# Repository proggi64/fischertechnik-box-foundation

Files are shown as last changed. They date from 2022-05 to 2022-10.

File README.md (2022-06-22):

# Fischertechnik Sorting Box Construction Foundation For OpenSCAD
Find the documentation at https://proggi64.github.io/fischertechnik-box-foundation/

The foundation library provides a continuously expanding collection of parametric sorting elements, deployment and placement modules, as well as base sorting boxes for the Fischertechnik building blocks system. The results are intended to be printed with 3D printers.

This library is based on the mid-1970's high-grade plastic sorting boxes used by the Fischertechnik building kits. Some sample boxes that are almost identical to the original ones are included.

ec2

The goals of this library is to simplify the contruction of sorting boxes and provide an alternative to using CAD software. However, the elements and element groups may be exported as STLs and used in CAD software, as well.

The library modules are divided in these groups:
- Base
- ModelBase
- Elements
- Test
- Original Building Kits
- Building Kits

## Documentation

- [English](Documentation/en/Contents.md) - Not available, yet
- [German](Documentation/de/Contents.md)

## Base
Contains the base functionality of the library:
- Alignment.scad
- Boxes.scad
- BoxInlays.scad
- Constants.scad
- Deployment.scad
- Placement.scad
- PlacementOptions.scad
- Rotation.scad

Additionally, in the base folder are the STL files of the empty 190x130 and 130x95 boxes that are used to place the building block elements.

## ModelBase
Contains simple and complex parametrized base objects that are used with different parameters by concrete elements.

## Elements
Contains concrete elements for specific building parts, some of them with parameters. All of them are linked to one or more Fischertechnik part numbers.

## Test
Contains sample code for each module that demonstrate the parameters und functionality.

## Original Building Kits
Contains boxes that are almost identical to existing boxes from the 1970's and 1980's that demonstrate how to build boxes with the library. Each bulding kit series has its own subfolder (i.e. "ec", "em").

## Building Kits
Contains boxes for newer building kits from the last 20 years or so, that never had there own sorting box. These boxes are completely new designs. Each bulding kit series has its own subfolder (i.e. "Profi", "Computing").

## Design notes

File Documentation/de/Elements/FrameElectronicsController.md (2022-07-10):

# FrameElectronicsController
E-Tec-, Electronics Modul oder Robotics Modul mit Fach für montiertes Kabel.
- 32263
- 152063
- 156499

Das Element kann an Wände oder in Ecken des Sortierkastens angedockt werden.

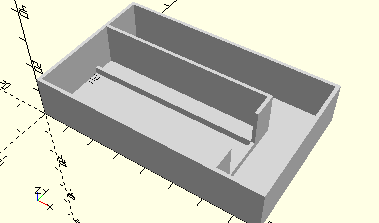
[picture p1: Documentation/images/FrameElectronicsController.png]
FrameElectronicsController


## Use
```
use <../Elements/FrameElectronicsController.scad>

include <../../Base/PlacementOptions.scad>
```

## Syntax
```
FrameElectronicsController(
    alignX);

space = get$FrameElectronicsControllerSpace(
    alignX);
```

| Parameter | Typ | Beschreibung |
| --- | --- | --- |
| alignX | typ | beschreibung |

## Rückgabewert getFrameElectronicsControllerSpace
Fläche als \[x,y]-Liste

## Beispiel
```
use <../../Base/Placement.scad>
use <../../Base/Boxes.scad>
use <../../Elements/FrameElectronicsController.scad>

include <../../Base/PlacementOptions.scad>

Box190();

Place(alignX=AlignRight, alignY=AlignTop, elementSpace=getFrameElectronicsControllerSpace())
    FrameElectronicsController(alignX=AlignRight, alignY=AlignTop);
```

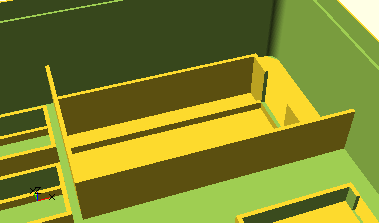
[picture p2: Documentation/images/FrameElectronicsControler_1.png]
FrameElectronicsController angedockt


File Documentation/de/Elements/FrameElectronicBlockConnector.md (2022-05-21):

# FrameElectronicBlockConnector
Verbindungsstecker für Elektronik-Bausteine.
- 36380

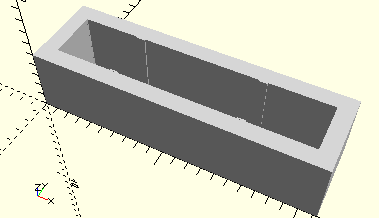
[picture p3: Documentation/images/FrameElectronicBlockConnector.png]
FrameElectronicBlockConnector


## Use
```
use <../Elements/FrameElectronicBlockConnector.scad>
```

## Syntax
```
FrameElectronicBlockConnector();

space = getFrameElectronicBlockConnectorSpace();
```

## Rückgabewert getFrameElectronicBlockConnectorSpace
Fläche als \[x,y]-Liste

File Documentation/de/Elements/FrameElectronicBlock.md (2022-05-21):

# FrameElectronicBlock
Elektronikbaustein (Silberling).
- 36391
- 36392
- 36393
- 36394
- 36479
- 36480
- 36481
- 36482
- 36483
- 36713
- 36733
- 36735
- 36786
- 37140 (alt, hobbylabor1)
- 37683

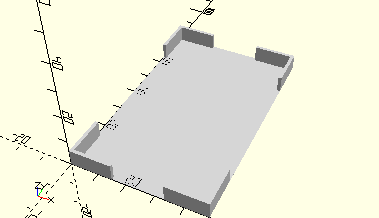
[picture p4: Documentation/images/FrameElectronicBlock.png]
FrameElectronicBlock


## Use
```
use <../Elements/FrameElectronicBlock.scad>
```

## Syntax
```
FrameElectronicBlock(
    alignX=NoAlign,
    alingY=NoAlign);

space = getFrameElectronicBlockSpace(
    alignX=NoAlign,
    alingY=NoAlign);
```

| Parameter | Typ | Beschreibung |
| --- | --- | --- |
| alignX | Integer (Enum) | Erzeugt optional einen Rand für das Andocken an die linke oder rechte Wand des Sortierkastens: 0=NoAlign 1=AlignLeft 4=AlignRight. Es werden Stege erzeugt, die mit der Wand verschmelzen. |
| alignY | Integer (Enum) | Erzeugt optional einen Rand für das Andocken an die hintere oder vordere Wand des Sortierkastens: 0=NoAlign 2=AlignBottom 5=AlignTop. Es werden Stege erzeugt, die mit der Wand verschmelzen. |

## Rückgabewert getFrameElectronicBlockSpace
Fläche als \[x,y]-Liste.

## Beispiel
Test/Elements/TestFrameElectronicBlock.scad

```
use <../../Base/Placement.scad>
use <../../Elements/FrameElectronicBlock.scad>

include <../../Base/PlacementOptions.scad>

FrameElectronicBlock();

Place(0, 85)
    FrameElectronicBlock(alignX=AlignLeft);

Place(80, 85)
    FrameElectronicBlock(alignX=AlignRight);

Place(0, 170)
    FrameElectronicBlock(alignY=AlignBottom);

Place(80, 170)
    FrameElectronicBlock(alignY=AlignTop);

Place(0, 260)
    FrameElectronicBlock(alignX=AlignLeft, alignY=AlignBottom);

Place(80, 260)
    FrameElectronicBlock(alignX=AlignLeft, alignY=AlignTop);

Place(0, 350)
    FrameElectronicBlock(alignX=AlignRight, alignY=AlignBottom);

Place(80, 350)
    FrameElectronicBlock(alignX=AlignRight, alignY=AlignTop);
```

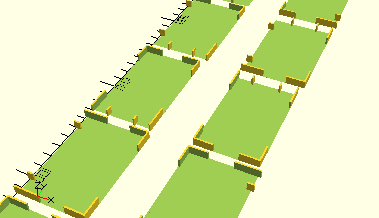
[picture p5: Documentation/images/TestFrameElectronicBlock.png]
TestFrameElectronicBlock


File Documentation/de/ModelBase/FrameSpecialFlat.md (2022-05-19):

# FrameSpecialFlat

Erzeugt einen Rahmen für spezielle Flachbausteine.

Diese Art Rahmen wurde in den ec-Kästen vor allem für Linsen und Lochblenden eingesetzt. Der Baustein liegt flach in Rahmen auf erhöhten Auflagen. Der Rahmen hat seitliche Eingriffe.

## Use
```
use <../ModelBase/Complex.scad>
```

## Syntax
```
FrameSpecialFlat(
  volume);
```

| Parameter | Typ | Beschreibung |
| --- | --- | --- |
| volume | \[x,y,z] | Länge x Breite x Höhe des speziellen Flachbausteins. Auf Länge und Breite wird noch der Wert von *tolerance* für das tatsächliche innere Volumen gerechnet. Die Höhe darf 15 mm nicht überschreiten, da der Rahmen nur so hoch ist. |

## Beispiel
```
use <../../ModelBase/Complex.scad>

FrameSpecialFlat([30, 37, 4]);

translate([40, 0])
FrameSpecialFlat([30, 34, 9]);
```

FrameSpecialFlat

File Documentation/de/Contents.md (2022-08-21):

# Inhalt

Dies ist die erste Version vom 1. Juni 2022. Der Grundstock für die Konstruktion von Sortierkästen umfasst schon ca. 100 Elemente der grauen Bausteine, die Ende der 1970er Jahre existierten. Bis Anfang Juli kamen noch mehr als 35 neue Elemente hinzu. Als Beispiele wurden die Kästen [ec1-3](../../Original%20Building%20Kits/ec/) sowie [mot1 bis mot3](../../Original%20Building%20Kits/mot/) nachgebaut. Unter [Motor Set XS](../../Building%20Kits/PLUS/) findet man ein Beispiel für einen kompletten Eigenentwurf. Für die hobby-Elektronikbausteine ("Silberlinge") sind druckbare Kästen im Verzeichnis [hobby](../../Building%20Kits/hobby/) als SCAD- und STL-Dateien hinterlegt.

Zwei Tutorials [Sortierkästen konstruieren](TutorialSortingBoxes.md) und [Elemente selbst konstruieren](TutorialElements.md) sollen helfen, eigene Beiträge zu ermöglichen.

## Allgemeines
- [Über die Bibliothek](readme.md)
- [Konstruktionsprinzipien](Principles.md)
- [Elemente erst im 3D-Druck testen](PrintTests.md)
- [Sortierkästen konstruieren](TutorialSortingBoxes.md)
- [Elemente selbst konstruieren](TutorialElements.md)
- [Elemente für CAD-Software nach STL exportieren](STLExport.md)
- [Beispielkästen und -Inlays](SampleBoxes.md)
- [Glossar](Glossar.md)

## Elemente für Sortierkästen

[Liste nach Fischertechnik-Artikelnummer](PartFinder.md)

## Basisfunktionen und -module

### Module für Grundelemente
- [__Box130__](Base/Box130.md): Importiert einen leeren Sortierkasten 130 x 95 mm als Basis für eigene Entwürfe.
- [__Box190__](Base/Box190.md): Importiert einen leeren Sortierkasten 190 x 130 mm als Basis für eigene Entwürfe.
- [__Box190Inlay__](Base/Box190Inlay.md): Erzeugt eine Grundplatte für Elemente, die in einen Original-Sortierkasten gelegt werden kann.
- [__Box190InlayWeb__](Base/Box190InlayWeb.md): Erzeugt einen kurzen Steg mit Einrast-Mechanismus für [__Box190Inlay__](Base/Box190Inlay.md).
- [__BoxWeb__](Base/BoxWeb.md): Erzeugt einen kurzen Steg an der Innenwand einer Sortierbox.

### Module zur Platzierung von Elementen
- [__Center__](Base/Center.md): Platziert Children-Elemente horizontal und/oder vertikal zentriert.
- [__CenterHorizontal__](Base/CenterHorizontal.md): Platziert Children-Elemente horizontal zentriert.
- [__CenterVertical__](Base/CenterVertical.md): Platziert Children-Elemente vertikal zentriert.
- [__DeployHorizontal__](Base/DeployHorizontal.md): Verteilt Children-Elemente mit gleichem Abstand horizontal.
- [__DeploySame__](Base/DeploySame.md): Verteilt mehrere Kopien des Children-Elements auf die angegebenen Spalten und Zeilen.
- [__DeployVertical__](Base/DeployVertical.md): Verteilt Children-Elemente mit gleichem Abstand vertikal.
- [__Merge__](Base/Merge.md): Fügt Kopien des Children-Elements so aneinander, dass dessen Trennwände zu jeweils einer verschmelzen.
- [__MergeRow__](Base/MergeRow.md): Fügt die Children-Elemente so aneinander, dass dessen Trennwände zu jeweils einer verschmelzen.
- [__Place__](Base/Place.md): Platziert die Children-Elemente auf die angegebene Position (absolut oder ausgerichtet).
- [__RotateFix__](Base/RotateFix.md): Rotiert das Children-Element um 0, 90, 180 oder 270 Grad im Uhrzeigersinn.

### Funktionen zur Koordinatenberechnung
- [__getAlignedX__](Base/getAlignedX.md): Berechnet X-Position für horizontal ausgerichtetes Element.
- [__getAlignedY__](Base/getAlignedY.md): Berechnet Y-Position für vertikal ausgerichtetes Element.
- [__getDepthSum__](Base/getDepthSum.md): Liefert Summe aller Tiefen der angegebenen Flächen.
- [__getIsHorizontal__](Base/getIsHorizontal.md): Liefert true, wenn die angegebene Ausrichtung eine horizontale Trennwand erfordert.
- [__getIsVertical__](Base/getIsVertical.md): Liefert true, wenn die angegebene Ausrichtung eine vertikale Trennwand erfordert.
- [__getMaxDepth__](Base/getMaxDepth.md): Liefert größte Tiefe der angegebenen Flächen.
- [__getMaxWidth__](Base/getMaxWidth.md): Liefert größte Breite der angegebenen Flächen.
- [__getMergedRowWidth__](Base/getMergedRowWidth.md): Liefert die Gesamtbreite einer zusammengefügten Reihe von Frame-basierten Elementen.
- [__getRotatedSpace__](Base/getRotatedSpace.md): Liefert eine Fläche so transformiert, dass die angegebene Drehung angewandt wird.
- [__getWidthSum__](Base/getWidthSum.md): Liefert Summe aller Breiten der angegebenen Flächen.
- [__getX__](Base/getX.md): Liefert eine Elementposition für die gleichmäßige Verteilung über eine Breite.
- [__getY__](Base/getY.md): Liefert eine Elementposition für die gleichmäßige Verteilung über eine Tiefe.

### Funktionen zur Ermittlung von Konstanten
- [__getAxisBottomDiameter__](Base/getAxisBottomDiameter.md): Liefert den Durchmesser für die Basis einer Achse.
- [__getAxisDiameter__](Base/getAxisDiameter.md): Liefert den Durchmesser einer Fischertechnik-Achse.
- [__getAxisLockingLength__](Base/getAxisLockingLength.md):Liefert die Länge des Rastbereichs einer Rastachse.
- [__getAxisTolerance__](Base/getAxisTolerance.md): Liefert den Betrag, der vom Durchmesser einer Fischertechnik-Achse abgezogen wird, wenn Standachsen generiert werden, damit die Fischertechnikteil darauf passen.
- [__getBox130Space__](Base/getBox130Space.md): Liefert die nutzbare Fläche eines Sortierkastens 130 x 95 mm.
- [__getBox190Space__](Base/getBox190Space.md): Liefert die nutzbare Fläche eines Sortierkastens 190 x 130 mm.
- [__getBoxBaseThickness__](Base/getBoxBaseThickness.md): Liefert die Stärke des Bodens eines Sortierkastens.
- [__getBoxUsageHeight__](Base/getBoxUsageHeight.md): Liefert die nutzbare innere Höhe eines Sortierkastens.
- [__getBoxWallThickness__](Base/getBoxWallThickness.md): Liefert die Stärke der Wände eines Sortierkastens.
- [__getBoxWebWidth__](Base/getBoxWebWidth.md): Liefert die Standardlänge eines Stegs für Sortierkästen.
- [__getDividerThickness__](Base/getDividerThickness.md): Liefert die Standardbreite einer Trennwand.
- [__getExcess__](Base/getExcess.md): Liefert den Betrag, um den ein Objekt mit einem verbundenen Objekt verschmilzt.
- [__getFragments__](Base/getFragments.md): Liefert die Anzahl der Fragmente für cylinder-Objekte ($fn).
- [__getFullStrutLength__](Base/getFullStrutLength.md): Liefert die Gesamtlänge einer Strebe auf Basis ihrer Nominallänge.
- [__getHubRingDiameter__](Base/getHubRingDiameter.md): Äußerer Durchmesser des Zylinders für Räder.
- [__getHubRingLevelDiameter__](Base/getHubRingLevelDiameter.md): Äußerer Durchmesser der Zylinderbasis für Räder.
- [__getPropellerAxisDiameter__](Base/getPropellerAxisDiameter.md): Liefert den Durchmesser der Propellerachse.
- [__getPropellerAxisTolerance__](Base/getPropellerAxisTolerance.md): Wird beim Durchmesser der Propellerachse als Druck-Toleranz verwendet.
- [__getStudHeight__](Base/getStudHeight.md): Länge eines Baustein-Verbindungszapfens.
- [__getStudRailDistance__](Base/getStudRailDistance.md): Abstand zweier Stege, damit Zapfen dazwischen passen.
- [__getStudTolerance__](Base/getStudTolerance.md): Wird zur Länge eines Baustein-Verbindungszapfens addiert, wenn Platz in Elementen dafür erzeugt wird.
- [__getSmallPartsFrameHeight__](Base/getSmallPartsFrameHeight.md): Liefert die Höhe für Rahmen, die für in Sortierkästen Kleinteile vorgesehen sind.
- [__getStandardEdgeDistance__](Base/getStandardEdgeDistance.md): Liefert den Standard-Abstand für andockbare Rahmen mit Stegen.
- [__getStandardWebDistance__](Base/getStandardWebDistance.md): Liefert den Abstand eines Stegs zur jeweiligen Ecke eines andockbaren Elements.
- [__getStandAxisDiameter__](Base/getStandAxisDiameter.md): Liefert den Durchmesser für Standachsen (z.B. für [__Axis__](ModelBase/Axis.md))
- [__getStrutDepth__](Base/getStrutDepth.md): Liefert die Stärke einer Strebe.
- [__getStrutEndRadius__](Base/getStrutEndRadius.md): Liefert den Radius vom Mittelpunkt des Schraublochs zum 
äußeren Ende einer Strebe.
- [__getStrutThickness__](Base/getStrutThickness.md): Liefert den Dicke einer Strebe.
- [__getStrutTolerance__](Base/getStrutTolerance.md): Liefert den Toleranzwert für Strebenhalterungen.
- [__getTolerance__](Base/getTolerance.md): Liefert den Betrag für die Toleranz bei Elementen, damit die Bauteile nach dem Druck in die Elemente passen.
- [__getTubeWallThickness__](Base/getTubeWallThickness.md): Liefert Stärke der Wände eines Element-Zylinders.

## Funktionen und Module für das Konstruieren von Elementen

### Module für einfache Grundformen
- [__AlignedFrame__](Modelbase/AlignedFrame.md): Erzeugt einen Rahmen, der an bis zu zwei Wände gleichzeitig angedockt werden kann.
- [__AngeledFrame__](ModelBase/AngeledFrame.md): Erzeugt einen um 90° gewinkelten Rahmen.
- [__Axis__](ModelBase/Axis.md): Erzeugt eine stehende Achse.
- [__AxisWithSpace__](ModelBase/AxisWithSpace.md): Erzeugt eine stehende Achse mit einer Grundplatte.
- [__Divider__](ModelBase/Divider.md): Erzeugt einen Trenner innerhalb eines Sortierkastens.
- [__DockableFrame__](ModelBase/DockableFrame.md): Erzeugt einen Rahmen, der an Wände angedockt werden kann.
- [__Frame__](ModelBase/Frame.md): Erzeugt einen Rahmen mit optional einzeln offenen Wänden.
- [__FrameBottomCutoff__](Modelbase/FrameBottomCutoff.md): Mit __difference__ in [__Frame__](ModelBase/Frame.md) einen Ausschnitt in die vordere Wand schneiden.
- [__FrameLeftCutoff__](Modelbase/FrameLefttCutoff.md): Mit __difference__ in [__Frame__](ModelBase/Frame.md) einen Ausschnitt in die linke Wand schneiden.
- [__FrameRails__](ModelBase/FrameRails.md): Erzeugt zwei parallele Stege am Boden eines mit [__Frame__](ModelBase/Frame.md) erzugten Rahmens.
- [__FrameRightCutoff__](Modelbase/FrameRightCutoff.md): Mit __difference__ in [__Frame__](ModelBase/Frame.md) einen Ausschnitt in die rechte Wand schneiden.
- [__FrameTopCutoff__](Modelbase/FrameTopCutoff.md): Mit __difference__ in [__Frame__](ModelBase/Frame.md) einen Ausschnitt in die hintere Wand schneiden.
- [__LeveledAxis__](ModelBase/LeveledAxis.md): Erzeugt eine stehende Achse mit einer stärkeren Achsbasis.
- [__LeveledAxisWithSpace__](ModelBase/LeveledAxisWithSpace.md): Erzeugt eine stehende Achse mit einer stärkeren Achsbasis und einer Grundplatte.
- [__LeveledTube__](ModelBase/LeveledTube.md): Erzeugt eine stehenden hohlen Zylinder mit einer stärkeren Basis.
- [__LockingAxis__](ModelBase/LockingAxis.md): Erzeugt eine stehende Achse für Rastachsenkupplungen.
- [__Space__](ModelBase/Space.md): Erzeugt eine dünne Fläche als Basis für ein Element.
- [__Text__](ModelBase/Text.md): Erzeugt einen reliefartigen Text im Boden des Sortierkastens.
- [__Tube__](ModelBase/Tube.md): Erzeugt eine stehenden hohlen Zylinder.
- [__Wall__](ModelBase/Wall.md): Erzeugt eine Wand.

### Funktionen zur Ermittlung der Größe einfacher Grundformen
- [__getAngeledFrameOuterVolume__](ModelBase/getAngeledFrameOuterVolume.md): Liefert das äußere Gesamtvolumen ("bounding box") eines gewinkelten Rahmens.
- [__getFrameInnerVolume__](ModelBase/getFrameInnerVolume.md): Liefert das innere Volumen eines Rahmens.
- [__getFrameOuterVolume__](ModelBase/getFrameOuterVolume.md): Liefert das äußere Volumen ("bounding box") eines Rahmens.

### Module für komplexe Grundformen
- [__AxisMiddleSupport__](ModelBase/AxisMiddleSupport.md): Erzeugt ein Stützelement für Achsen.
- [__ElevatedFramesWithCutoff__](ModelBase/ElevatedFramesWithCutoff.md): Erzeugt eine Halterung, die im Normalfall für einzelne Achsen verwendet wird.
- [__DockableEdgedFrame__](ModelBase/DockableEdgedFrame.md): Erzeugt einen Rahmen für Bauteile, der optional an bis zu zwei Wänden angedockt werden kann.
- [__FrameAxis__](ModelBase/FrameAxis.md): Erzeugt eine Achshalterung für eine Achse.
- [__FrameBracket__](ModelBase/FrameBracket.md): Erzeugt einen Rahmen für einen Getriebeaufsatz mit oder ohne Schnecke.
- [__FrameFlatPiece__](ModelBase/FrameFlatPiece.md): Erzeugt einen Rahmen für Flachstücke.
- [__FrameRack__](ModelBase/FrameRack.md): Erzeugt einen Rahmen für Zahnstangen.
- [__FrameSpecialFlat__](ModelBase/FrameSpecialFlat.md): Erzeugt einen Rahmen für spezielle Flachbausteine.
- [__HolderBuildingPlate__](ModelBase/HolderBuildingPlate.md): Erzeugt Halter für Bauplatten.
- [__RackBase__](ModelBase/RackBase.md): Erzeugt den inneren Rahmen für Zahnstangen.
- [__RailsBasePlate__](ModelBase/RailsBasePlate.md): Erzeugt Fläche mit Stegen für die Ablage einer Grundplatte.

### Funktionen zur Ermittlung von Werten zu komplexen Grundformen
- [__getAxisMiddleSupportSpace__](ModelBase/getFrameAxisMiddleSupportSpace.md): Liefert die Fläche eines mit [__AxisMiddleSupport__](ModelBase/AxisMiddleSupport.md) erzeugten Stützelements.
- [__getDockableEdgedFrameDepth__](ModelBase/getDockableEdgedFrameDepth.md): Liefert den vertikalen Abstand des angedockten Rahmens für [__DockableEdgedFrame__](ModelBase/DockableEdgedFrame.md).
- [__getDockableEdgedFrameWidth__](ModelBase/getDockableEdgedFrameWidth.md): Liefert den horizontalen Abstand des angedockten Rahmens für [__DockableEdgedFrame__](ModelBase/DockableEdgedFrame.md).
- [__getDockableEdgedFrameSpace__](ModelBase/getDockableEdgedFrameSpace.md): Liefert die Fläche für einen mit [__DockableEdgedFrame__](ModelBase/DockableEdgedFrame.md) erzeugten Rahmen.
- [__getDepthPerPlate__](ModelBase/getDepthPerPlate.md): Liefert die Tiefe (Dicke) einer Bauplatte für [__HolderBuildingPlate__](HolderBuildingPlate.md).
- [__getElevatedFramesWithCutoffSpace__](ModelBase/getElevatedFramesWithCutoffSpace.md): Liefert die Fläche des Elements, das mit dem Modul [__ElevatedFramesWithCutoff__](ElevatedFramesWithCutoff.md) erzeugt wird.
- [__getFrameAxisDepth__](ModelBase/getFrameAxisDepth.md): Liefert die Tiefe der Achshalterungen für [__FrameAxis__](ModelBase/FrameAxis.md).
- [__getFrameAxisHeight__](ModelBase/getFrameAxisHeight.md): Liefert die Höhe der Achshalterungen für [__FrameAxis__](ModelBase/FrameAxis.md).
- [__getFrameAxisSpace__](ModelBase/getFrameAxisSpace.md): Liefert die Fläche einer mit [__FrameAxis__](ModelBase/FrameAxis.md) erzeugte Achshalterung.
- [__getFrameBracketSpace__](ModelBase/getFrameBracketSpace.md): Liefert die Fläche für eine Halterung eines Getriebeaufsatzes.
- [__getFrameBracketWidth__](ModelBase/getFrameBracketWidth.md): Liefert die Breite für eine Halterung eines Getriebeaufsatzes ohne die Achse/Schnecke.
- [__getFrameFlatPieceVolume__](ModelBase/getFrameFlatPieceVolume.md): Liefert das Volumen eines mit [__FrameFlatPiece__](Modelbase/FrameFlatPiece.md) erzeugt wird.
- [__getFrameRackSpace__](ModelBase/getFrameRackSpace.md): Liefert die Fläche eines Rahmens für Zahnstangen.
- [__getHolderBuildingPlateSpace__](ModelBase/getHolderBuildingPlateSpace.md): Liefert die Fläche einer Halterung für Bauplatten.
- [__getRackInnerHeight__](ModelBase/getRackInnerHeight.md): Liefert die innere Höhe der Halterungen für Zahnstangen.
- [__getRailsBasePlateVolume__](ModelBase/getRailsBasePlateVolume.md): Liefert das Volumen des Rahmens für Grundplatten.

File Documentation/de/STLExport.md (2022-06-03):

# Elemente als STLs erzeugen
Mit OpenSCAD ist es sehr einfach, ein einzelnes Element als STL-Datei zu exportieren. Damit können die Elemente in CAD-Software weiter verwendet werden.

## Elemente ohne Parameter
Hier gibt es nur eine Variante, so dass nur ein einziger Export notwendig ist.

- die SCAD-Datei des gewünschten Elements aus dem __Elements__-Ordner in OpenSCAD öffnen
- der Dateiname entspricht 1:1 dem Namen aus der Dokumentation
- im Vorschaufenster erscheint bereits das Element
- Menüpunkt __Design__ | __Rendern F6__ wählen 
- die Farbe des Elements in der Vorschau wechselt von grau auf gelb
- Menüpunkt __Datei__ | __Exportieren...__ | __STL exportieren... F7__ wählen
- Zielverzeichnis im Dialog __STL Datei exportieren__ wählen
- Schaltfläche __Speichern__ klicken

## Elemente mit Parametern
Hier muss man sich die Variante einrichten, die man im jeweiligen Fall benötigt. Dazu sind die Parameter einzugeben. OpenSCAD hat ein schönes Feature namens __Customizer__. Die Elemente mit Parametern sind so erstellt, dass man ohne Änderungen des Codes die Parameter über diese Oberfläche einstellen und sich passende Varianten erstellen kann.

- SCAD laden wir bei den Elementen ohne Parameter
- Menüpunkt __Fenster__ | __Customizer__ anklicken

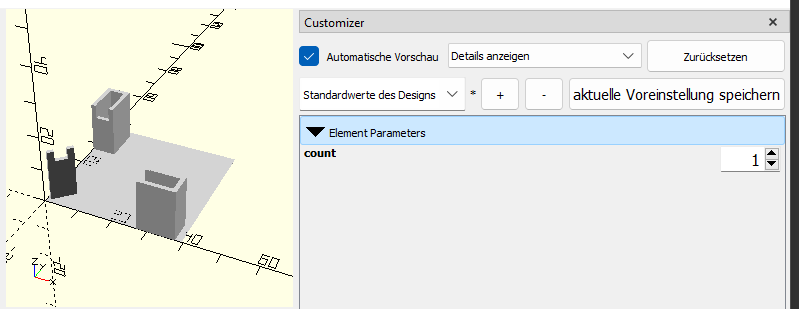
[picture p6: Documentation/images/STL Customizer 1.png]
STL Customizer count 1


- __Element Parameters__ im Customizer-Fenster aufklappen
- alle Parameter des Elements sind jetzt hier sichtbar und können angepasst werden
- nach Änderung eines Parameters einfach die __Tab__-Taste drücken, die Vorschau wird aktualisiert

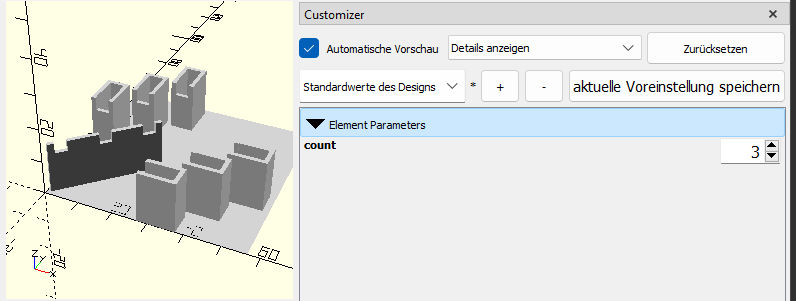
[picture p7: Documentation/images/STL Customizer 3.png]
STL Customizer count 3


- dann wie bei *Elemente ohne Parameter* mit __Rendern__ fortfahren und bis __Speichern__ gehen
- verschiedenen Varianten sollte man unterschiedliche STL-Dateinamen geben

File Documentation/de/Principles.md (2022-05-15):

# Konstruktionsprinzipien

Für die Konstruktion der Bibliothek wurden einige Prinzipien festgelegt, die beim weiteren Ausbau beachtet werden sollten, die aber auch wertvoll für den Einsatz der Bibliothek sind.

## Ziel 3D-Druck

Der gesamte Code ist darauf ausgerichtet, dass die 3D-Druck-Ergebnisse verwendbare Sortierboxen produzieren.

- Sinnvolle Toleranzen für alle Elemente (Constants.scad - __getTolerance()__), damit die Teile in die Elemente passen
- Saubere Verschmelzung von 3D-Elementen und Box (Constants.scad - __getExcess()__), um ungewollte Luftspalte zu vermeiden
- Druckbare Wandstärken, die hinreichend stabil bleiben sollten (Constants.scad - __getDividerThickness()__)
- Elemente benötigen keine Stützstrukturen

Die Bibliothek geht davon aus, dass ein 3D-Drucker mit einer 0,4 mm-Extruderdüse und einer Genauigkeit von 0,2 mm eingesetzt wird. Das Bauvolumen muss für die Sortierbox 190 x 130 ca. 20 x 14 x 4 cm groß sein.

## Elemente
Elemente sind die Konstrukte, die in der Sortierbox zur Aufnahme von ein oder mehreren Bauelementen platziert werden. Sie sind i.d.R. speziell für bestimmte Bauteile zugeschnitten. Für Kleinteile gibt es auch einfache parametrisierbare Kastenformen. Die passenden Elemente können über ihre Artikelnummer gefunden werden.

- Jedes Element hat eine eigene SCAD-Datei, deren Dateiname dem Namen des *module* entspricht.
- Jedes Element hat ein *module*, was das Element darstellt
- Jedes Element hat eine Funktion namen __get*ElementName*Space()__, welche den exakten Platzbedarf des Elements in der Box als x/y-Liste liefert.
- Manche Element benötigen Parameter, z.B. für die Anzahl der Bauteile, die sie fassen sollen
- Die __get*ElementName*Space()__-Funktionen benötigen i.d.R. dieselben Parameter wie das *module*.

Beispiel Getriebeschnecke 31045 für den 6V-Motor:

- Datei: *Elements/FrameBracketWithWorm.scad*
- Module: __FrameBracketWithWorm()__
- Function: __getFrameBracketWithWormSpace()__

Alle Elemente sind so konstruiert, dass sie bei der Platzierung in den Sortierkasten mit deren Boden verschmelzen. Der Betrag dieser Verschmelzung wird durch die in *Constants.scad* festgelegte Funktion __getExcess()__ bestimmt. Jedes Element hat eine Basisfläche der __get*ElementName*Space()__-Größe in dieser dünnen Stärke, die beim Platzieren im Boden des Sortierkastens verschwindet.

## Andockbare Elemente

Einige Elemente sind so entworfen, dass sie an eine oder zwei Wände der Box angedockt werden können. Diese Elemente haben i.d.R. Teile, die mit der Wand der Box beim Platzieren (in Verbindung mit dem Alignment) verschmolzen werden. Dafür ragen diese Teile über die jeweilige Nullposition hinaus, so dass sie in die Wand der Box integriert werden. Beispiele sind die Elemente für die Silberlinge (__FrameElectronicBlock__). Welche Seiten an die Wände gedockt werden, wird i.d.R. über entsprechende Parameter der Module gesteuert.

## Sortierboxen

Die Sortierkästen werden als STL-Dateien eingebunden. Sie wurden mit einem CAD-Programm entworfen und können mit den Original-Kästen von Fischertechnik gestapelt werden. Bei der Platzierung der Elemente ist die z-Nullinie exakt der obere Rand des Bodens des Sortierkastens. Die Position 0,0 ist exakt die Ecke der nutzbaren Innenfläche der Box.

Die Elemente werden, wie schon erwähnt, um den Betrag von __getExcess()__ in den Boden versenkt. Dies erledigen die Unterstützungs- und Platzierungsfunktionen.

## Ausrichtung

Die Bibliothek stell eine Reihe von Platzierungs- und Ausrichtungsfunktionen zur Verfügung, die bei der Konstruktion von Sortierboxen nützlich sind.

## Baukastenprinzip kombinierbar mit individuellen Elementen

Vorgefertigte Elemente und das individuelle Programmieren mit OpenSCAD-Code sollen beliebig kombinierbar sein. Die Funktionen und Module aus dem *Base*-Verzeichnis sollen auch bei der individuellen Gestaltung der Sortierkästen helfen. Beispiele für solche Kombinationen sind die Nachbauten der Originalkästen, z.B. der mot2.

## Tests als Beispiel

Im Verzeichnis *Test* befinden sich in entsprechenden Unterverzeichnissen jeweils Quellcodes mit Demonstrationen der Module, Funktionen und aller Elemente. Jedes Element und jedes Modul hat einen separate Testdatei. Dies sind so aufgebaut, dass sie gleichzeitig als manueller Test und Beispiel dienen.

- Test/Base: *Gruppenname*Test*Module*.scad oder *Gruppenname*Test*Function*.scad
- Test/ModelBase: SimpleTest*Module*.scad oder ComplexTest*Module*.scad
- Test/Elements: Test*Elementname*.scad

## Weitere Prinzipien

- Redundanzen bei Code und Konstanten werden vermieden, um an zentralen Stellen Anpassungen zu ermöglichen
- Namen sind über alle Quellcodes konsistent
- Sinnvolle Standardwerte für Parameter sollen den Einsatz vereinfachen

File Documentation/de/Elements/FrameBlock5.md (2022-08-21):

# FrameBlock5
Baustein 5 mit einem Zapfen.
- 37237
- 37468

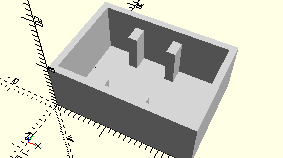
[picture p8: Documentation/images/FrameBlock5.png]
FrameBlock5


Die Abbildung zeigt ein Beispiel für 3 Bausteine 5. Es werden ab einer Zahl größer 1 automatisch Trenner eingefügt, damit die Steine nicht kippen.

3D-Druck getestet.

## Use
```
use <../Elements/FrameBlock5.scad>
```

## Syntax
```
FrameBlock5(
    count=1);

space = get$FrameBlock5Space(
    count=1);
```

| Parameter | Typ | Beschreibung |
| --- | --- | --- |
| count | Integer | Anzahl der Bausteine 5. |

## Rückgabewert getFrameBlock5Space
Fläche als \[x,y]-Liste

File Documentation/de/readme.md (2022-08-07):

# Fischertechnik Konstruktionsbibliothek für Sortierkästen mit OpenSCAD
Die Bibliothek bietet eine sich kontinuierlich erweiternde Sammlung an parametrisierten Sortierlementen, Verteilungs- und Platzierfunktionen, sowie Basis-Sortierkästen und Einsätze für Originalkästen für das Fischertechnik-Baukastensystem. Die Kästen und Einsätze sind so entworfen, dass sie sich mit 3D-Druckern selbst herstellen lassen.

Die Bibliothek wurde inspiriert durch die Kunstoff-Sortierkästen der Fischertechnik-Baukästen der 1970er bis Anfang 1980er Jahre. Einige Beispielkästen im Verzeichnis *Original Building Kits* sind weitgehend identisch mit den Originalkästen.

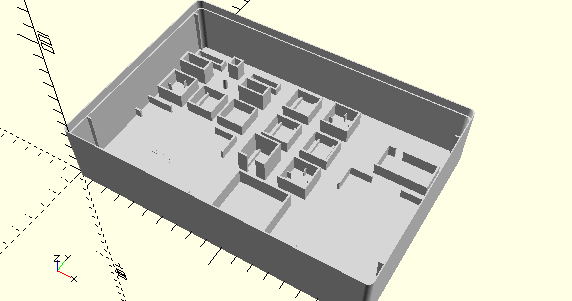
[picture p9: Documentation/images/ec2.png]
ec2


Die Ziele dieser Bibliothek sind es die Konstruktion eigener Sortierkästen zu vereinfachen und eine Alternative zur CAD-Programmen zu bieten. Dennoch können die Elemente auch in CAD-Programmen verwendet werden, wenn man sie einzeln als STL-Dateien exportiert. Dafür wird bei Elementen, die Parameter benötigen, der OpenSCAD-Customizer unterstützt. Dadurch können alle benötigten Varianten gerendert und als STL-Datei exportiert werden, ohne dass OpenSCAD-Skripte geändert werden müssen.

Um die Bibliothek sinnvoll einsetzen zu können, sollte man zumindest die Grundlagen von [OpenSCAD](https://openscad.org/documentation.html) beherrschen:
- Koordinatensystem auf den X/Y/Z-Achsen
- Module und Funktionen
- Einfache Geometrie

Die Bibliothek teilt sich in folgende Gruppen:
- Base
- ModelBase
- Elements
- Test
- Original Building Kits
- Building Kits

## Base
Enthält die Basisfunktionalität der Bibliothek:
- Alignment.scad  
Funktionen für die Berechnung von Koordinaten für die Ausrichtung (Links/Oben/Rechts/Unten/Zentriert)
- Boxes.scad  
Module für den Import leerer Sortierboxen als Grundlage für jede Box
- BoxInlays.scad  
Module zum Erzeugen von bestückbaren Bodeneinlagen für Original-Fischertechnik Sortierkästen statt ganzer Kästen
- Constants.scad  
Funktionen, die konstante Werte liefern, z.B. die Wandstärke und die Toleranz
- Deployment.scad  
Module, die Elemente gleichmäßig verteilen
- Placement.scad  
Module, die Elemente platzieren und ausrichten
- PlacementOptions.scad  
Optionswerte für die Ausrichtung und Drehung, die per __include__ eingebunden werden
- Rotation.scad  
Module, die Elemente drehen

Im Base-Verzeichnis finden sich auch die STL-Dateien mit den Leerboxen 190x130 und 130x95, die als Basis zur Konstruktion verwendet werden.

## ModelBase
Enthält einfache (__Simple.scad__) und komplexere (__Complex.scad__) parametrisierbare Basiselemente, mit denen die Elemente für spezifische Bauteile erstellt werden. Diese können aber auch für individuelle Elemente für spezifische Sortierkästen verwendet werden.

## Elements
Enthält Elemente für spezifische Fischertechnik-Bauteile, einige von ihnen parametrisierbar. Alle sind auch Fischertechnik-Teilenummern zugeordnet, die in den Quelldateien als Kommentare vermerkt sind. Diese Elemente sind sofort für die Konstruktion von Sortierboxen verwendbar. Diese Sammlung wird kontinuierlich erweitert. Über die Dokumentationsseite [PartFinder](PartFinder.md) können mit der Fischertechnik-Teilenummer die passenden Elemente gefunden werden.

## Test
Enthält Testdateien für alle Module, die Funktionalität und Elemente demonstrieren. Im Unterverzeichnis __PrintTest__ befinden sich außerdem für den 3D-Druck vorbereitete SCAD-Dateien für den Testdruck jedes Elements.

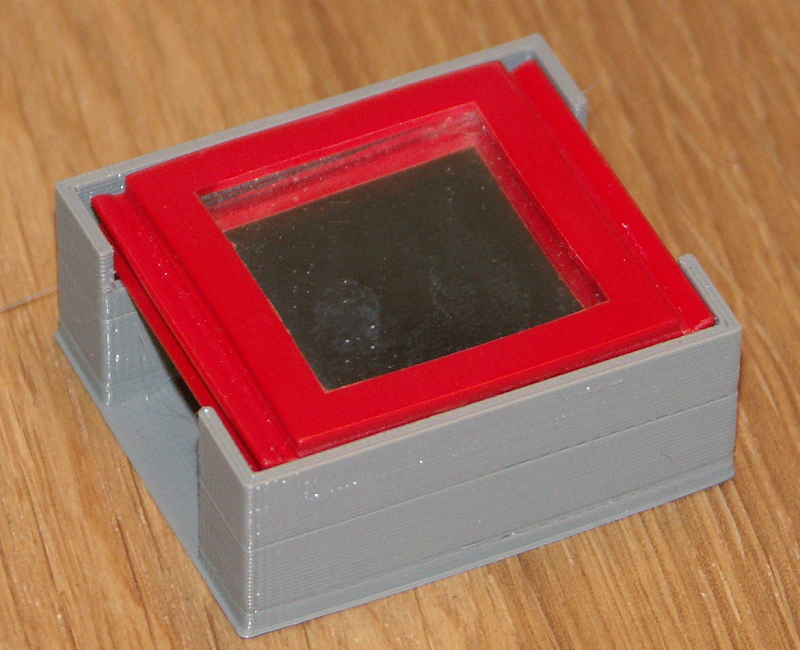
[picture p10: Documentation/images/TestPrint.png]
Testdruck für Element


*Testdruck eines Elements vermeidet große Fehldrucke*

## Original Building Kits
Enthält Beispiele von nachgebauten Original-Sortierkästen aus den 1970er Jahren zur Demonstration, wie Kästen konstruiert werden können. Beispielweise sind die drei Elektronikkästen ec1 bis ec3 im Unterverzeichnis ec enthalten.

## Building Kits
Enthält selbstkonstruierte Sortierkästen für Baukästen ab den 1980er Jahren. Diese sind komplette Neuentwürfe.

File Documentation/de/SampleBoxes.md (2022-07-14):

# Beispiele für Sortierkästen

Es gibt zwei Arten von Beispielkästen, die sukzessive erweitert werden:
- Nachgebaute Originalkästen
- Neue Entwürfe

## Neu entworfene Sortierkästen für aktuelle oder historische Fischertechnikkästen

Verzeichnis: Building Kits/*group*

Im Juli 2022 gibt es hier die Gruppen *hobby*, *PLUS* und *PROFI*.

## Nachgebaute Originalkästen

Verzeichnis: Original Building Kits/*group*

Gruppen sind z.B. Baukastenreihen wie ec (Elektronik) oder mot (Motoren)

## Kompletter Kasten oder Inlay

Die Kästen ec1-ec3 wurden so modifiziert, dass sie als komplette Kästen oder Inlays für die Box-1000-Sortierkästen generiert werden können. Die Auswahl erfolgt über den OpenSCAD-Customizer:

### ec1 als Inlay
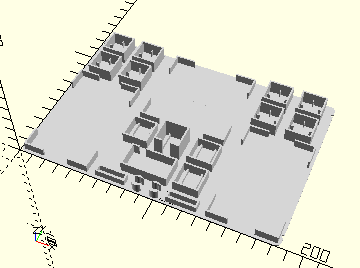
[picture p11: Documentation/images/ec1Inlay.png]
ec1Inlay


### ec1 komplett
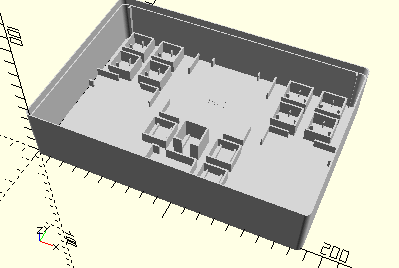
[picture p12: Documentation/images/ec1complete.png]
ec1


### Auswahl im Customizer
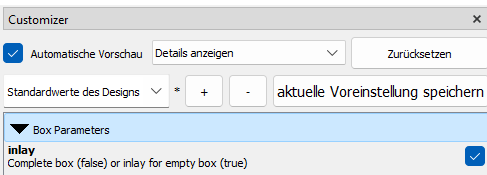
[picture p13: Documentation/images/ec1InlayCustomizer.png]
ec1 Customizer


### Was zu beachten war

Zunächst muss eine boolsche Variable eingeführt werden. Ein sinnvoller Name dafür ist *inlay*:

```
/* [Box Parameters] */
// Complete box (false) or inlay for empty box (true)
inlay = false;
```

Ebenfalls sinnvoll ist das Ausblenden von weiteren internen Variablen durch diese Kommentarzeile:

```
/* [Hidden] */
```

Um den kompletten Kasten durch ein Inlay auszutauschen muss man lediglich diese Sequenz verwenden:

```
if (inlay) {
    Box190Inlay();
} else {
    Box190();
    BoxWeb(LowerLeft, RightOfCorner, 15.2);
    BoxWeb(LowerRight, LeftOfCorner, 15.2);
    BoxWeb(UpperRight, RightOfCorner, 5);
    BoxWeb(UpperLeft, LeftOfCorner, 5);
}
```

Dadurch werden auch die Stege entfernt.

Falls man, wie beim ec1, auch Elemente verwendet, die sich an die Wand andocken, muss man weitere Änderungen einbauen. Beim ec1 war das der Rahmen für die Kassette oben, sowie die beiden links und rechts angedockten Rahmen für Relais und Gleichrichter. Diese beiden Elemente ([__FrameCassette__](Elements/FrameCassette.md) und [__FrameElectronicBlock__](Elements/FrameElectronicBlock.md)) rücken sich automatisch etwas von den Wänden ab und generiern Stege, wenn sie gedockt werden. Das muss man bei *inlay* = __true__ ausschalten:

```
    FrameElectronicBlock(alignX=inlay ? NoAlign : AlignLeft, alignY=inlay ? NoAlign : AlignBottom);
```

Beim Docken am linken (__AlignLeft__) oder unteren Rand (__AlignBottom__) muss man außerdem beim Platzieren berücksichtigen, die Differenz des zusätzlichen Platzes für den Docking-Abstand zu x bzw. y zu addieren. Dadurch bleiben die Rahmen auch ohne Abstand und Stege an der vorgesehenen Position:

```
xInlayDiff = inlay ? 
    (getFrameElectronicBlockSpace(alignX=AlignRight, alignY=AlignBottom).x - getFrameElectronicBlockSpace().x) : 
    0;
yInlayDiff = inlay ? 
    (getFrameElectronicBlockSpace(alignX=AlignRight, alignY=AlignBottom).y - getFrameElectronicBlockSpace().y) : 
    0;
Place(xInlayDiff, yInlayDiff)
    FrameElectronicBlock(alignX=inlay ? NoAlign : AlignLeft, alignY=inlay ? NoAlign : AlignBottom);
```

Beim ec3 liegen Wände genau auf der Höhe der Stege der Sortierboxen des Kastens 1000. Deswegen mussten sie um einen Offset von -1,8 mm nach innen versetzt werden. Auch das muss beachtet werden, wenn man die Kästen für Inlays modifiziert.

In zukünftigen Versionen soll das noch besser unterstützt werden. Zunächst soll aber noch an weiteren Kästen geprüft werden, welche Auswirkungen durch *inlay*-Varianten auftreten können.

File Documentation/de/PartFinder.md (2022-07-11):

# Teileliste

Hier findet man fertige Elemente, die für Fischertechnikteile bereits entworfen wurden. Die Liste ist nach Gruppen von Artikelnummern gegliedert. Auf den verlinkten Seiten für die Elemente sind alle Artikelnummern der Bausteine zum Element aufgeführt.

Alle Elemente besitzen neben dem __module__ auch eine __function__ nach dem Namensschema __get*ElementName*Space__. Sie liefert die benötigte Fläche für das Element in Form einer \[x,y]-Liste. Zumeist haben diese Funktionen dieselben Parameter wie das __module__. Vielen Modulen für die Platzierung muss diese Fläche als Parameter mitgegeben werden, damit Drehungen und die Verteilung funktionieren.

__module__ und __function__ sind beide auf den verlinkten Seiten dokumentiert. Codebeispiele zeigen die Anwendung.

Die hier verlinkten Elemente sind Vorschläge. Viele Bausteine, die hier nicht aufgeführt sind, passen ebenfalls in vorhandene Elemente.

- [1 bis 29999](Parts_1_to_29999.md)
- [30000 bis 31499](Parts_30000_to_31499.md)
- [31500 bis 31999](Parts_31500_to_31999.md)
- [32000 bis 34999](Parts_32000_to_34999.md)
- [35000 bis 35499](Parts_35000_to_35499.md)
- [35500 bis 35999](Parts_35500_to_35999.md)
- [36000 bis 36499](Parts_36000_to_36499.md)
- [36500 bis 36999](Parts_36500_to_36999.md)
- [37000 bis 37999](Parts_37000_to_37999.md)
- [38000 bis 38999](Parts_38000_to_38999.md)
- [39000 bis 39999](Parts_39000_to_39999.md)
- [40000 bis 99999](Parts_40000_to_99999.md)
- [100000 bis 149999](Parts_100000_to_149999.md)
- [150000 bis 169999](Parts_150000_to_169999.md)
- [170000 bis 999999](Parts_170000_to_999999.md)

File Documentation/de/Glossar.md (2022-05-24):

# Glossar

| Begriff | Bedeutung |
| --- | ---  |
| __Alignment__ | Fasst alle Ausrichtungsmodule und -funktionen zusammen, mit denen *Elemente* an Rändern ausgerichtet oder zentriert werden können. |
| __Axis__ | Stehende Achse als Aufnahmeelement für Naben, Achskupplungen oder andere Bauteile, die mit Achsen verbunden werden. Alle *Elemente*, die als Basis eine Achse haben, bekommen im Modulnamen das Präfix *Axis*. |
| __Bottom__ | Bezeichnet den vorderen Bereich von Elementen oder Boxen, z.B. bei __AlignBottom__. |
| __Center__ | Zentrieren von Elementen auf Strecken oder Flächen. |
| __Combo__  | Namens-Präfix für Kombinationen von gruppierten Elementen, die ein größeres Element bilden. |
| __Cylinder__ | Stehende Zylinder als Aufnahmeelement für Reifen oder andere Bauteile, die mit Naben oder anderen rundenBauelementen verbunden werden. Alle *Elemente*, die als Basis einen Zylinder haben, bekommen im Modulnamen das Präfix *Cylinder*. |
| __Deploy__ | Automatisches Verteilen gleicher oder verschiedener Elemente auf Strecken oder Flächen. |
| __Deployment__ | Fasst alle Module und Funktionen zusammen, mit denen mehrere Elemente gleichmäßig über Strecken oder Flächen verteilt werden können. |
| __Depth__ | Strecken auf der Y-Achse ("Tiefe"). |
| __Divider__ | Bezeichner für Trennwand. |
| __Element__ | 3D-Konstrukt, welches den Platz für einzelne oder mehrere Bauteile innerhalb der Sortierbox definiert. Einige können über Parameter modifiziert werden, z.B. um die Anzahl der Teile anzugeben. |
| __Frame__ | Rahmen für Bauteile, die im einfachen Fall *Element* sein können. Alle *Elemente*, die als Basis einen Rahmen haben, bekommen im Modulnamen das Präfix *Frame*. Die Rahmen bestehen aus Wänden, deren Standardstärke über die in *Constants.scad* definierte Funktion *getDividerThickness()* abgerufen werden kann. Das gleichname __Frame__-Modul bekommt als Parameter die Raumgröße des Fischertechnik-Teils und addiert für diesen noch die Standard-Toleranz in x- und y-Richtung (aus *Constants.scad* die Funktion *getTolerance()*). |
| __get__ | Namens-Präfix für alle Funktionen (__function__). |
| __Height__ | Strecken auf der Z-Achse. |
| __Holder__ | Halterung für Bauteile, die z.B. für Achsen oder Naben verwendet werden. Diese haben keinen *Frame* als Basis, sondern andere Grundformen. Diese Elemente bekommen das Präfix *Holder* im Modulnamen. |
| __Horizontal__ | Alles, was auf der X-Achse liegt. |
| __Placement__ | Fasst alle Platzierungs-Module zusammen, mit denen Elemente platziert und ausgerichtet werden können. |
| __Rotation__ | Fasst alle Module zusammen, mit denen Element rotiert werden können. Dabei wird jeweils die neue untere rechte Ecke an der urspünglichen Position der alten platziert. Bei rotierten Elemente, die an Rändern ausgerichtet sind, bleibt die Ausrichtung erwartungskonform, als wenn das Element auch urspünglich die Drehung hatte. |
| __Space__ | Fläche mit x/y-Ausdehnung. In der SCAD-Datei jedes *Elements* ist eine Funktion namens get*ElementName*Space() definiert, welche die Ausdehnung des Elements liefert. Da OpenSCAD eine funktionale Sprache ist und Objekte mit Methoden und Eigenschaften nicht vorgesehen sind, können diese Daten nicht über die 3D-Objekte abgerufen werden, sondern müssen separat als Funktion über Namenskonvention definiert werden. Flächen sind in OpenSCAD Listen aus mindestens zwei Werten \[x,y\]. Viele der Space-Funktionen liefern aber auch gleich den Z-Wert als dritten Wert mit. |
| __Top__ | Bezeichnet den hinteren Bereich von Elementen oder Boxen, z.B. bei __AlignTop__. |
| __Vertikal__ | Alles, was auf der Y-Achse liegt. |
| __Volume__ | Volumen mit x/y/z-Ausdehnung. Diese werden als Listen in OpenSCAD angegeben \[x,y,z\]. |
| __Width__ | Strecken auf der X-Achse ("Breite"). |

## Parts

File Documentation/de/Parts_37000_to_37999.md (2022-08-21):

# 37000 bis 37999
- 37140 [FrameElectronicBlock](Elements/FrameElectronicBlock.md)
- 37237 [FrameBlock5](Elements/FrameBlock5.md), [FrameSmallBlock](Elements/FrameSmallBlock.md)
- 37238 [FrameBlock5TwoStuds](Elements/FrameBlock5TwoStuds.md)
- 37263 [FrameLiftingGear](Elements/FrameLiftingGear.md)
- 37268 [FrameLiftingGear](Elements/FrameLiftingGear.md)
- 37271 [FrameLiftingGear](Elements/FrameLiftingGear.md)
- 37272 [FrameLiftingGear](Elements/FrameLiftingGear.md)
- 37276 [FrameConnectingRod30](Elements/FrameConnectingRod30.md)
- 37282 [HolderLiftingJoint](Elements/HolderLiftingJoint.md)
- 37283 [FrameConnectingRod60](Elements/FrameConnectingRod60.md)
- 37353 [HolderCompleteBucket](Elements/HolderCompleteBucket.md)
- 37354 [HolderCompleteBucket](Elements/HolderCompleteBucket.md)
- 37355 [HolderCompleteBucket](Elements/HolderCompleteBucket.md)
- 37384 [FrameAxis80](Elements/FrameAxis80.md)
- 37451 [FrameGearRack60](Elements/FrameGearRack60.md)
- 37457 [FrameGearRack30](Elements/FrameGearRack30.md)
- 37468 [FrameBlock5](Elements/FrameBlock5.md), [FrameSmallBlock](Elements/FrameSmallBlock.md)
- 37527 [FrameAxis180](Elements/FrameAxis180.md)
- 37636 [FrameBlockWithStud](Elements/FrameBlockWithStud.md)
- 37679 [Divider](ModelBase/Divider.md), [FrameCassette](Elements/FrameCassette.md)
- 37681 [AxisPropellerTip](Elements/AxisPropellerTip.md)
- 37683 [FrameElectronicBlock](Elements/FrameElectronicBlock.md)
- 37780 [FrameMiniPushButton](Elements/FrameMiniPushButton.md)
- 37783 [FrameMiniPushButton](Elements/FrameMiniPushButton.md)
- 37858 [ComboWormAndNutScrew](Elements/ComboWormAndNutScrew.md)
- 37869 [HolderBulbLamp](Elements/HolderBulbLamp.md)
- 37875 [HolderBulbLamp](Elements/HolderBulbLamp.md)

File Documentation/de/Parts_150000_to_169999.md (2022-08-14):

# 150000 bis 169999
- 152059 [FrameTransistorBlock](Elements/FrameTransistorBlock.md)
- 152063 [FrameElectronicsController](Elements/FrameElectronicsController.md)
- 152218 [FrameTransistorBlock](Elements/FrameTransistorBlock.md)
- 152219 [FrameBlockWithStud](Elements/FrameBlockWithStud.md), [Divider](ModelBase/Divider.md), [FrameCassette](Elements/FrameCassette.md)
- 152220 [FrameBlockWithStud](Elements/FrameBlockWithStud.md), [Divider](ModelBase/Divider.md), [FrameCassette](Elements/FrameCassette.md)
- 152222 [FrameBlockWithStud](Elements/FrameBlockWithStud.md), [Divider](ModelBase/Divider.md), [FrameCassette](Elements/FrameCassette.md)
- 152223 [FrameBlockWithStud](Elements/FrameBlockWithStud.md), [Divider](ModelBase/Divider.md), [FrameCassette](Elements/FrameCassette.md)
- 152860 [FrameTransistorBlock](Elements/FrameTransistorBlock.md)
- 153513 [FrameTXTController](Elements/FrameTXTController.md)
- 156042 [Divider](ModelBase/Divider.md), [FrameCassette](Elements/FrameCassette.md)
- 156499 [FrameElectronicsController](Elements/FrameElectronicsController.md)
- 156511 [HolderBuildingPlate30x30](Elements/HolderBuildingPlate30x30.md)
- 158402 [FrameSensor45x30](Elements/FrameSensor45x30.md)
- 160545 [FrameTwoStrut30](Elements/FrameTwoStrut30.md)
- 161944 [FrameBTSmartController](Elements/FrameBTSmartController.md)
- 162134 [FrameBlockWithStud](Elements/FrameBlockWithStud.md)
- 163042 [HolderBuildingPlate30x45](Elements/HolderBuildingPlate30x45.md)
- 163198 [FrameSidePieceLeft](Elements/FrameSidePieceLeft.md)
- 163199 [FrameSidePieceRight](Elements/FrameSidePieceRight.md)
- 163200 [FrameSidePiece15](Elements/FrameSidePiece15.md)
- 163201 [FrameStandardBlock](Elements/FrameStandardBlock.md)
- 163202 [FrameStandardBlock](Elements/FrameStandardBlock.md)
- 163203 [Divider](ModelBase/Divider.md), [FrameCassette](Elements/FrameCassette.md)
- 163204 [Divider](ModelBase/Divider.md), [FrameCassette](Elements/FrameCassette.md)
- 163436 [FrameSidePieceLeft](Elements/FrameSidePieceLeft.md)
- 163437 [FrameSidePieceRight](Elements/FrameSidePieceRight.md)
- 163439 [FrameStandardBlock](Elements/FrameStandardBlock.md)
- 167358 [FrameSensor45x30](Elements/FrameSensor45x30.md)

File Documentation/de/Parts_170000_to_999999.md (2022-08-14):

# 170000 bis 999999
- 172542 [FrameStandardBlock](Elements/FrameStandardBlock.md)
- 172545 [AxisIdlerGearZ15](Elements/AxisIdlerGearZ15.md)
- 172804 [FrameJointBlock](Elements/FrameJointBlock.md)
- 172805 [FrameJointBlock](Elements/FrameJointBlock.md)
- 173067 [FrameTXTController](Elements/FrameTXTController.md)
- 181583 [Divider](ModelBase/Divider.md), [FrameCassette](Elements/FrameCassette.md)
- 181584 [Divider](ModelBase/Divider.md), [FrameCassette](Elements/FrameCassette.md)
- 183025 [CylinderOmniWheel](Elements/CylinderOmniWheel.md)
- 183026 [CylinderOmniWheel](Elements/CylinderOmniWheel.md)
- 183027 [CylinderOmniWheel](Elements/CylinderOmniWheel.md)
- 183028 [CylinderOmniWheel](Elements/CylinderOmniWheel.md)
- 183233 [FrameElectronicsController](Elements/FrameElectronicsController.md)
- 183267 [FrameSensor45x30](Elements/FrameSensor45x30.md)
- 185516 [FrameTransistorBlock](Elements/FrameTransistorBlock.md)
- 186027 [FrameTransistorBlock](Elements/FrameTransistorBlock.md)
- 186028 [FrameTransistorBlock](Elements/FrameTransistorBlock.md)
- 186029 [FrameTransistorBlock](Elements/FrameTransistorBlock.md)
- 185695 [FramePlasticBall20](Elements/FramePlasticBall20.md), [Divider](ModelBase/Divider.md), [FrameCassette](Elements/FrameCassette.md)
- 185849 [FrameAxis50WithGearwheelZ28](Elements/FrameAxis50WithGearwheelZ28.md)
- 186705 [FrameSensor45x30](Elements/FrameSensor45x30.md)

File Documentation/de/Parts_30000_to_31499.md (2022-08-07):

# 30000 bis 31499
- 31001 [RailsBasePlate180x90](Elements/RailsBasePlate180x90.md)
- 31002 [RailsBasePlate90x90](Elements/RailsBasePlate90x90.md)
- 31003 [FrameStandardBlock](Elements/FrameStandardBlock.md)
- 31004 [FrameStandardBlock](Elements/FrameStandardBlock.md), [FrameSingleLayingStandardBlock](Elements/FrameSingleLayingStandardBlock.md)
- 31005 [FrameStandardBlock](Elements/FrameStandardBlock.md)
- 31006 [FrameBlockWithStud](Elements/FrameBlockWithStud.md)
- 31007 [FrameBlockWithStud](Elements/FrameBlockWithStud.md)
- 31008 [FrameHingedBlock](Elements/FrameHingedBlock.md), [FrameJointBlock](Elements/FrameJointBlock.md)
- 31009 [FrameHingedBlock](Elements/FrameHingedBlock.md), [FrameJointBlock](Elements/FrameJointBlock.md)
- 31010 [FrameAngleEquilateral](Elements/FrameAngleEquilateral.md)
- 31011 [FrameAngleIsosceles](Elements/FrameAngleIsosceles.md)
- 31012 [FrameAngleRight](Elements/FrameAngleRight.md)
- 31013 [FrameFlatPiece30](Elements/FrameFlatPiece30.md)
- 31014 [CylinderHub](Elements/CylinderHub.md), [CylinderHubWithZ30](Elements/CylinderHubWithZ30.md)
- 31015 [AxisFlatHub](Elements/AxisFlatHub.md), [CylinderHub](Elements/CylinderHub.md), [ComboFlatHubLargePulleyWheel](Elements/ComboFlatHubLargePulleyWheel.md)
- 31016 [HolderWinchDrum](Elements/HolderWinchDrum.md)
- 31017 [CylinderTire20](Elements/CylinderTire20.md)
- 31018 [HolderTire45](Elements/HolderTire45.md)
- 31019 [CylinderLargePulleyWheel](Elements/CylinderLargePulleyWheel.md), [ComboFlatHubLargePulleyWheel](Elements/ComboFlatHubLargePulleyWheel.md)
- 31020 [FrameLockingRing](Elements/FrameLockingRing.md)
- 31021 [CylinderGearZ20](Elements/CylinderGearZ20.md)
- 31022 [AxisFlatHubWithGearZ40](Elements/AxisFlatHubWithGearZ40.md)
- 31023 [AxisClip10](Elements/AxisClip10.md)
- 31024 [AxisCoupling](Elements/AxisCoupling.md)
- 31025 [Divider](ModelBase/Divider.md), [FrameCassette](Elements/FrameCassette.md)
- 31026 [AxisHandCrank](Elements/AxisHandCrank.md)
- 31027 [Divider](ModelBase/Divider.md), [FrameCassette](Elements/FrameCassette.md)
- 31028 [Divider](ModelBase/Divider.md), [FrameCassette](Elements/FrameCassette.md)
- 31029 [Divider](ModelBase/Divider.md), [FrameCassette](Elements/FrameCassette.md)
- 31031 [FrameAxis110](Elements/FrameAxis110.md)
- 31032 [FrameAxis60](Elements/FrameAxis60.md), [FrameAxis60open](Elements/FrameAxis60Open.md)
- 31033 [FrameAxis50](Elements/FrameAxis50.md)
- 31034 [FrameAxis30](Elements/FrameAxis30.md), [CylinderAxis30](Elements/CylinderAxis30.md)
- 31035 [FrameAngleAxis](Elements/FrameAngleAxis.md)
- 31036 [FrameAxis125](Elements/FrameAxis125.md)
- 31037 [CylinderAndAxisSegmentDisc](Elements/CylinderAndAxisSegmentDisc.md)
- 31038 [CylinderAndAxisDiscCam](Elements/CylinderAndAxisDiscCam.md), [ComboDiscCamPlusCogWheel](Elements/ComboDiscCamPlusCogWheel.md)
- 31039 [FrameMotor6V](Elements/FrameMotor6V.md)
- 31040 [FrameAxis90](Elements/FrameAxis90.md)
- 31041 [HolderBatterySet](Elements/HolderBatterySet.md)
- 31042 [Divider](ModelBase/Divider.md), [FrameCassette](Elements/FrameCassette.md)
- 31043 [FrameDifferentialGearbox](Elements/FrameDifferentialGearbox.md)
- 31044 [FrameUniversalJointCardan](Elements/FrameUniversalJointCardan.md)
- 31045 [FrameBracketWithWorm](Elements/FrameBracketWithWorm.md), [ComboFrameBrackets](Elements/ComboFrameBrackets.md)
- 31046 [FrameBracketWithoutWorm](Elements/FrameBracketWithoutWorm.md), [ComboFrameBrackets](Elements/ComboFrameBrackets.md)
- 31047 [AxisCogWheel](Elements/AxisCogWheel.md), [ComboDiscCamPlusCogWheel](Elements/ComboDiscCamPlusCogWheel.md)
- 31048 [FrameGearBox](Elements/FrameGearBox.md)
- 31051 [AxisCogWheel](Elements/AxisCogWheel.md), [ComboDiscCamPlusCogWheel](Elements/ComboDiscCamPlusCogWheel.md)
- 31052 [CylinderStepUpDownCog](Elements/CylinderStepUpDownCog.md)
- 31053 [FrameRack60](Elements/FrameRack60.md)
- 31054 [FrameRack30](Elements/FrameRack30.md)
- 31055 [FrameRack60](Elements/FrameRack60.md)
- 31056 [FrameRack30](Elements/FrameRack30.md)
- 31057 [Divider](ModelBase/Divider.md), [FrameCassette](Elements/FrameCassette.md)
- 31058 [CylinderHub](Elements/CylinderHub.md), [AxisFlatHub](Elements/AxisFlatHub.md)
- 31059 [FrameStandardBlock](Elements/FrameStandardBlock.md)
- 31060 [FrameTwoConnectors15](Elements/FrameTwoConnectors15.md)
- 31061 [FrameTwoConnectors30](Elements/FrameTwoConnectors30.md)
- 31062 [FrameMiniMotor](Elements/FrameMiniMotor.md)
- 31063 [FrameAxis60WithGearwheelZ28](Elements/FrameAxis60WithGearwheelZ28.md)
- 31064 [FrameAxis40WithGearwheelZ28](Elements/FrameAxis40WithGearwheelZ28.md)
- 31066 [FrameGearBlockWithWorm](Elements/FrameGearBlockWithWorm.md)
- 31067 [FrameGearBlock](Elements/FrameGearBlock.md)
- 31068 [FrameUFormGearbox](Elements/FrameUFormGearbox.md)
- 31069 [HolderGearSupportWithWorm](Elements/HolderGearSupportWithWorm.md)
- 31070 [FrameSwivelBaseForMiniMotor](Elements/FrameSwivelBaseForMiniMotor.md)
- 31075 [FrameGearBlockWithWorm](Elements/FrameGearBlockWithWorm.md)
- 31078 [FrameUFormGearbox](Elements/FrameUFormGearbox.md)
- 31080 [FrameCrankedAxis](Elements/FrameCrankedAxis.md)
- 31082 [CylinderLockingGearZ28](Elements/CylinderLockingGearZ28.md)
- 31194 [Divider](ModelBase/Divider.md), [FrameCassette](Elements/FrameCassette.md)
- 31308 [FrameJointBlock](Elements/FrameJointBlock.md)
- 31316 [FrameLightCap](Elements/FrameLightCap.md)
- 31317 [FrameLightCap](Elements/FrameLightCap.md)
- 31318 [FrameLightCap](Elements/FrameLightCap.md)
- 31319 [FrameLightCap](Elements/FrameLightCap.md)
- 31320 [FrameLightCap](Elements/FrameLightCap.md)
- 31321 [FrameLightCap](Elements/FrameLightCap.md)
- 31330 [FrameTwoConnectors45](Elements/FrameTwoConnectors45.md)
- 31331 [FramePushButton](Elements/FramePushButton.md)
- 31332 [FramePushButton](Elements/FramePushButton.md)
- 31338 [CylinderClipContact](Elements/CylinderClipContact.md)
- 31361 [FramePhotoResistor30](Elements/FramePhotoResistor30.md)
- 31362 [FrameLightCap](Elements/FrameLightCap.md)
- 31363 [FrameLightTube](Elements/FrameLightTube.md)
- 31365 [FrameLens](Elements/FrameLens.md)
- 31366 [FrameLens](Elements/FrameLens.md)
- 31367 [FrameLens](Elements/FrameLens.md)
- 31368 [FramePlaneMirror](Elements/FramePlaneMirror.md)
- 31369 [FrameConcaveMirror](Elements/FrameConcaveMirror.md)
- 31370 [HolderMirrorBand](Elements/HolderMirrorBand.md)
- 31371 [FrameAperture](Elements/FrameAperture.md)
- 31372 [FrameAperture](Elements/FrameAperture.md)
- 31373 [FrameAperture](Elements/FrameAperture.md)
- 31379 [Divider](ModelBase/Divider.md), [FrameCassette](Elements/FrameCassette.md)
- 31380 [Divider](ModelBase/Divider.md), [FrameCassette](Elements/FrameCassette.md)
- 31381 [Divider](ModelBase/Divider.md), [FrameCassette](Elements/FrameCassette.md)
- 31422 [Divider](ModelBase/Divider.md), [FrameCassette](Elements/FrameCassette.md)
- 31426 [FrameStandardBlock](Elements/FrameStandardBlock.md)
- 31436 [FrameStandardBlock](Elements/FrameStandardBlock.md)

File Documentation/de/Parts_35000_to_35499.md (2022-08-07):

# 35000 bis 35499
- 35030 [AxisFlatHub](Elements/AxisFlatHub.md), [CylinderHub](Elements/CylinderHub.md)
- 35049 [FrameBlock15x30x5](Elements/FrameBlock15x30x5.md)
- 35053 [FrameStandardBlock](Elements/FrameStandardBlock.md)
- 35063 [CylinderLockingAxis30](Elements/CylinderLockingAxis30.md), [FrameAxis30](Elements/FrameAxis30.md)
- 35069 [ComboLockingWinchDrumAndHolder](Elements/ComboLockingWinchDrumAndHolder.md)
- 35070 [ComboLockingWinchDrumAndHolder](Elements/ComboLockingWinchDrumAndHolder.md)
- 35072 [AxisLockingWorm](Elements/AxisLockingWorm.md)
- 35073 [AxisLockingAxisCoupling](Elements/AxisLockingAxisCoupling.md), [Divider](ModelBase/Divider.md), [FrameCassette](Elements/FrameCassette.md)
- 35077 [FrameBlockWithStud](Elements/FrameBlockWithStud.md)
- 35078 [FrameBlockWithStud](Elements/FrameBlockWithStud.md)
- 35079 [FrameBlockWithStud](Elements/FrameBlockWithStud.md)
- 35084 [FrameBlockWithStud](Elements/FrameBlockWithStud.md)
- 35085 [FrameBlockWithStud](Elements/FrameBlockWithStud.md)
- 35086 [FrameBlockWithStud](Elements/FrameBlockWithStud.md)
- 35088 [AxisLockingCrank](Elements/AxisLockingCrank.md)
- 35112 [ComboDiscCamPlusCogWheel](Elements/ComboDiscCamPlusCogWheel.md)
- 35113 [ComboDiscCamPlusCogWheel](Elements/ComboDiscCamPlusCogWheel.md), [FrameUniversalJointCardan](Elements/FrameUniversalJointCardan.md)
- 35466 [CylinderAndAxisDiscCam](Elements/CylinderAndAxisDiscCam.md), [ComboDiscCamPlusCogWheel](Elements/ComboDiscCamPlusCogWheel.md)

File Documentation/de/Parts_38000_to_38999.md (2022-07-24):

# 38000 bis 38999
- 38201 [FrameBracketWithAxle80](Elements/FrameBracketWithAxle80.md)
- 38216 [FrameBlockWithStud](Elements/FrameBlockWithStud.md)
- 38217 [FrameBlockWithStud](Elements/FrameBlockWithStud.md)
- 38224 [FrameShortHook](Elements/FrameShortHook.md)
- 38225 [FrameShortHook](Elements/FrameShortHook.md)
- 38237 [HolderBuildingPlate30x45](Elements/HolderBuildingPlate30x45.md)
- 38238 [HolderBuildingPlate30x45](Elements/HolderBuildingPlate30x45.md)
- 38240 [FrameBlockWithStud](Elements/FrameBlockWithStud.md)
- 38243 [HolderBuildingPlate30x45](Elements/HolderBuildingPlate30x45.md)
- 38246 [Divider](ModelBase/Divider.md), [FrameCassette](Elements/FrameCassette.md)
- 38248 [HolderBuildingPlate30x45](Elements/HolderBuildingPlate30x45.md)
- 38251 [HolderBuildingPlate30x90](Elements/HolderBuildingPlate30x90.md)
- 38252 [FrameCouplingBracket](Elements/FrameCouplingBracket.md)
- 38257 [HolderCompleteBucket](Elements/HolderCompleteBucket.md)
- 38259 [HolderBuildingPlate30x30](Elements/HolderBuildingPlate30x30.md)
- 38261 [HolderBuildingPlate30x45](Elements/HolderBuildingPlate30x45.md)
- 38266 [HolderBuildingPlate30x30](Elements/HolderBuildingPlate30x30.md)
- 38267 [HolderBuildingPlate30x30](Elements/HolderBuildingPlate30x30.md)
- 38268 [HolderBuildingPlate30x30](Elements/HolderBuildingPlate30x30.md)
- 38269 [HolderBuildingPlate30x45](Elements/HolderBuildingPlate30x45.md)
- 38313 [FrameAxis30](Elements/FrameAxis30.md), [CylinderAxis30](Elements/CylinderAxis30.md)
- 38314 alt Kunststoffachse grau [FrameAxis40](Elements/FrameAxis40.md)
- 38315 alt Kunststoffachse grau [FrameAxis50](Elements/FrameAxis50.md)
- 38316 alt Kunststoffachse grau [FrameAxis60](Elements/FrameAxis60.md)
- 38414 [FrameAxis40](Elements/FrameAxis40.md)
- 38415 [FrameAxis50](Elements/FrameAxis50.md)
- 38416 [FrameAxis60](Elements/FrameAxis60.md)
- 38418 [HolderLinkBeam](Elements/HolderLinkBeam.md)
- 38423 [FrameAngleBlock10x15x15](Elements/FrameAngleBlock10x15x15.md)
- 38428 [FrameBuildingPlate5x15x30](Elements/FrameBuildingPlate5x15x30.md)
- 38435 [FrameDriversCabLeftRight](Elements/FrameDriversCabLeftRight.md)
- 38436 [FrameDriversCabLeftRight](Elements/FrameDriversCabLeftRight.md)
- 38485 [HolderBuildingPlate30x90](Elements/HolderBuildingPlate30x90.md)
- 38537 [FrameTwoStrut30](Elements/FrameTwoStrut30.md)
- 38538 [FrameTwoStrut30](Elements/FrameTwoStrut30.md)

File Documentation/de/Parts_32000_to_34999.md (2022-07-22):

# 32000 bis 34999
- 32064 [FrameBlockWithStud](Elements/FrameBlockWithStud.md)
- 32071 [FrameAngle7p5](Elements/FrameAngle7p5.md)
- 32076 [FrameCassette](Elements/FrameCassette.md)
- 32085 [FrameRollerBuck](Elements/FrameRollerBuck.md)
- 32263 [FrameElectronicsController](Elements/FrameElectronicsController.md)
- 32293 [Frame9VMiniMotor](Elements/Frame9VMiniMotor.md)
- 32316 [Divider](ModelBase/Divider.md), [FrameCassette](Elements/FrameCassette.md)
- 32321 [FrameBlockWithStud](Elements/FrameBlockWithStud.md)
- 32330 [FrameBuildingPlate5x15x30](Elements/FrameBuildingPlate5x15x30.md)
- 32698 [FrameBlockWithStud](Elements/FrameBlockWithStud.md)
- 32850 [FrameStandardBlock](Elements/FrameStandardBlock.md)
- 32879 [FrameStandardBlock](Elements/FrameStandardBlock.md)
- 32880 [FrameStandardBlock](Elements/FrameStandardBlock.md), [FrameSingleLayingStandardBlock](Elements/FrameSingleLayingStandardBlock.md)
- 32881 [FrameStandardBlock](Elements/FrameStandardBlock.md)
- 32882 [FrameBlockWithStud](Elements/FrameBlockWithStud.md)
- 33582 [Divider](ModelBase/Divider.md), [FrameCassette](Elements/FrameCassette.md)

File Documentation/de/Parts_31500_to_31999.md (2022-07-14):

# 31500 bis 31999
- 31501 [HolderBuildingPlate30x30](Elements/HolderBuildingPlate30x30.md)
- 31502 [HolderBuildingPlate30x45](Elements/HolderBuildingPlate30x45.md)
- 31503 [HolderBuildingPlate30x90](Elements/HolderBuildingPlate30x90.md)
- 31510 [HolderBuildingPlate30x30](Elements/HolderBuildingPlate30x30.md)
- 31511 [HolderBuildingPlate30x45](Elements/HolderBuildingPlate30x45.md)
- 31555 [FrameFlatPiece60](Elements/FrameFlatPiece60.md)
- 31556 [FrameFlatPiece30](Elements/FrameFlatPiece30.md)
- 31597 [Divider](ModelBase/Divider.md), [FrameCassette](Elements/FrameCassette.md)
- 31602 [Divider](ModelBase/Divider.md), [FrameCassette](Elements/FrameCassette.md)
- 31642 [Divider](ModelBase/Divider.md), [FrameCassette](Elements/FrameCassette.md)
- 31764 [FrameTwoStrut30](Elements/FrameTwoStrut30.md)
- 31848 [Divider](ModelBase/Divider.md), [FrameCassette](Elements/FrameCassette.md)
- 31915 [ComboWormAndNutScrew](Elements/ComboWormAndNutScrew.md)
- 31918 [FrameAngleEquilateral](Elements/FrameAngleEquilateral.md)
- 31981 [FrameAngle15](Elements/FrameAngle15.md)
- 31982 [Divider](ModelBase/Divider.md), [FrameCassette](Elements/FrameCassette.md)
- 31983 [AxisCoupling](Elements/AxisCoupling.md)

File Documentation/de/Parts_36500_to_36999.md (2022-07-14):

# 36500 bis 36999
- 36508 [HolderBuildingPlate30x45](Elements/HolderBuildingPlate30x45.md)
- 36518 [FrameCassette](Elements/FrameCassette.md)
- 36531 [FrameLightCap](Elements/FrameLightCap.md)
- 36532 [FrameLightCap](Elements/FrameLightCap.md)
- 36573 [Divider](ModelBase/Divider.md), [FrameCassette](Elements/FrameCassette.md)
- 36581 [CylinderWheel23](../Elements/CylinderWheel23.md)
- 36624 [CylinderHubWithZ30](Elements/CylinderHubWithZ30.md)
- 36391 [FrameElectronicBlock](Elements/FrameElectronicBlock.md)
- 36392 [FrameElectronicBlock](Elements/FrameElectronicBlock.md)
- 36393 [FrameElectronicBlock](Elements/FrameElectronicBlock.md)
- 36394 [FrameElectronicBlock](Elements/FrameElectronicBlock.md)
- 36479 [FrameElectronicBlock](Elements/FrameElectronicBlock.md)
- 36480 [FrameElectronicBlock](Elements/FrameElectronicBlock.md)
- 36481 [FrameElectronicBlock](Elements/FrameElectronicBlock.md)
- 36482 [FrameElectronicBlock](Elements/FrameElectronicBlock.md)
- 36483 [FrameElectronicBlock](Elements/FrameElectronicBlock.md)
- 36713 [FrameElectronicBlock](Elements/FrameElectronicBlock.md)
- 36733 [FrameElectronicBlock](Elements/FrameElectronicBlock.md)
- 36735 [FrameElectronicBlock](Elements/FrameElectronicBlock.md)
- 36786 [FrameElectronicBlock](Elements/FrameElectronicBlock.md)
- 36912 [FrameTwoStrut30](Elements/FrameTwoStrut30.md)
- 36915 [Divider](ModelBase/Divider.md), [FrameCassette](Elements/FrameCassette.md)
- 36918 [HolderBuildingPlate30x30](Elements/HolderBuildingPlate30x30.md)
- 36920 [FrameStandardBlock](Elements/FrameStandardBlock.md)
- 36922 [FrameBlockWithStud](Elements/FrameBlockWithStud.md)
- 36950 [FrameBlockWithStud](Elements/FrameBlockWithStud.md)

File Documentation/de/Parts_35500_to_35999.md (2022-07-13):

# 35500 bis 35999
- 35537 [FrameCassette](Elements/FrameCassette.md)
- 35586 [CylinderWheel23](Elements/CylinderWheel23.md)
- 35608 [Divider](ModelBase/Divider.md), [FrameCassette](Elements/FrameCassette.md)
- 35694 [CylinderInternalGearWheel](Elements/CylinderInternalGearWheel.md), [ComboInnerGearWheelAndIdlerGearZ15](Elements/ComboInnerGearWheelAndIdlerGearZ15.md), [ComboInnerGearWheelAndIdlerGearZ15](Elements/ComboInnerGearWheelAndIdlerGearZ15.md)
- 35695 [AxisAndCylinderIdlerGearZ15](Elements/AxisAndCylinderIdlerGearZ15.md), [AxisIdlerGearZ15](Elements/AxisIdlerGearZ15.md), [ComboInnerGearWheelAndIdlerGearZ15](Elements/ComboInnerGearWheelAndIdlerGearZ15.md)
- 35795 [FramePulley](Elements/FramePulley.md), [AxisPulley](Elements/AxisPulley.md)
- 35797 [FramePulley](Elements/FramePulley.md), [AxisPulley](Elements/AxisPulley.md)
- 35831 [FrameHingedBlock](Elements/FrameHingedBlock.md), [FrameJointBlock](Elements/FrameJointBlock.md)
- 35885 [FrameBlockWithStud](Elements/FrameBlockWithStud.md)
- 35886 [FrameBlockWithStud](Elements/FrameBlockWithStud.md)
- 35945 [AxisLockingGear10](Elements/AxisLockingGear10.md)
- 35969 [FrameReedRelayHolder](Elements/FrameReedRelayHolder.md), [Divider](ModelBase/Divider.md), [FrameCassette](Elements/FrameCassette.md)
- 35975 [Divider](ModelBase/Divider.md), [FrameCassette](Elements/FrameCassette.md)

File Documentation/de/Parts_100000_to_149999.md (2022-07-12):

# 100000 bis 149999
- 110349 [CylinderAndAxisSegmentDisc](Elements/CylinderAndAxisSegmentDisc.md)
- 116251 [FrameStandardBlock](Elements/FrameStandardBlock.md)
- 116252 [FrameStandardBlock](Elements/FrameStandardBlock.md)
- 117336 [Divider](ModelBase/Divider.md), [FrameCassette](Elements/FrameCassette.md)
- 127471 [FrameStandardBlock](Elements/FrameStandardBlock.md)
- 127472 [FrameStandardBlock](Elements/FrameStandardBlock.md)
- 128598 [FrameTrailSensor](Elements/FrameTrailSensor.md)
- 128659 [Divider](ModelBase/Divider.md), [FrameCassette](Elements/FrameCassette.md)
- 130593 [FrameBlockWithStud](Elements/FrameBlockWithStud.md)
- 132226 [FrameBlockWithStud](Elements/FrameBlockWithStud.md)
- 132875 [Divider](ModelBase/Divider.md), [FrameCassette](Elements/FrameCassette.md)
- 134867 [Divider](ModelBase/Divider.md), [FrameCassette](Elements/FrameCassette.md)
- 135719 [Frame9VBatterySet](Elements/Frame9VBatterySet.md)
- 136528 [FrameStandardBlock](Elements/FrameStandardBlock.md)
- 136529 [FrameStandardBlock](Elements/FrameStandardBlock.md)
- 136775 [AxisLockingPulley12](Elements/AxisLockingPulley12.md)
- 137096 [FrameMiniMotor](Elements/FrameMiniMotor.md)
- 139645 [FrameBlockWithStud](Elements/FrameBlockWithStud.md)
- 146534 [HolderBuildingPlate30x30](Elements/HolderBuildingPlate30x30.md)

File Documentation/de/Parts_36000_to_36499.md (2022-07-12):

# 36000 bis 36499
- 36223 [FrameJointBlock](Elements/FrameJointBlock.md)
- 36248 [Divider](ModelBase/Divider.md), [FrameCassette](Elements/FrameCassette.md)
- 36263 [Divider](ModelBase/Divider.md), [FrameCassette](Elements/FrameCassette.md)
- 36264 [CylinderHubWithZ30](Elements/CylinderHubWithZ30.md)
- 36298 [FrameBlockWithStud](Elements/FrameBlockWithStud.md)
- 36299 [FrameStandardBlock](Elements/FrameStandardBlock.md)
- 36300 [FrameStandardBlock](Elements/FrameStandardBlock.md)
- 36301 [FrameStandardBlock](Elements/FrameStandardBlock.md)
- 36304 [FrameBlockWithStud](Elements/FrameBlockWithStud.md)
- 36309 [FrameTwoStrut30](Elements/FrameTwoStrut30.md)
- 36323 [Divider](ModelBase/Divider.md), [FrameCassette](Elements/FrameCassette.md)
- 36324 [Divider](ModelBase/Divider.md), [FrameCassette](Elements/FrameCassette.md)
- 36334 [Divider](ModelBase/Divider.md), [FrameCassette](Elements/FrameCassette.md)
- 36380 [FrameElectronicBlockConnector](Elements/FrameElectronicBlockConnector.md)
- 36387 [FramePluggedCapacitor](Elements/FramePluggedCapacitor.md)
- 36388 [AxisDial](Elements/AxisDial.md)
- 36390 [FrameControlLight](Elements/FrameControlLight.md)
- 36457 [Divider](ModelBase/Divider.md), [FrameCassette](Elements/FrameCassette.md)
- 36478 [FrameLightCap](Elements/FrameLightCap.md)
- 36495 [Divider](ModelBase/Divider.md), [FrameCassette](Elements/FrameCassette.md)

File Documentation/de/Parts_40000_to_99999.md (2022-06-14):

# 40000 bis 99999
- 75067 [FrameLiftingGear](Elements/FrameLiftingGear.md)

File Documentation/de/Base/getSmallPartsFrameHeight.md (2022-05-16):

# getSmallPartsFrameHeight

Funktion: Liefert die Höhe für Rahmen, die für in Sortierkästen Kleinteile vorgesehen sind.

Divider

## Use
```
use <../ModelBase/Simple.scad>
```

## Syntax
```
getSmallPartsFrameHeight();
```

## Rückgabewert
Standardhöhe einer Trennwand für Kleinteile, z.B. für [__Divider__](../ModelBase/Divider.md).

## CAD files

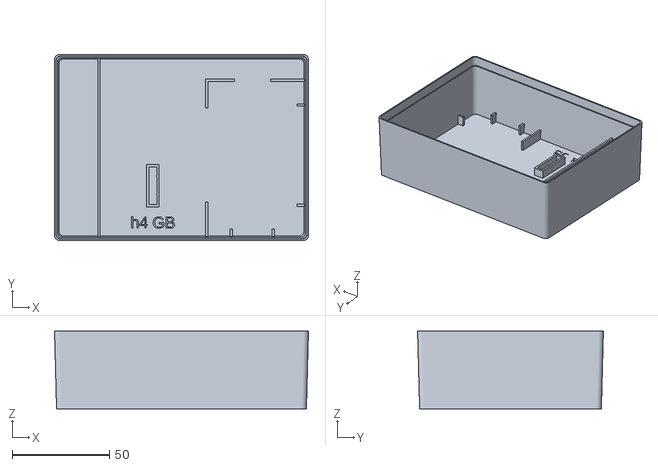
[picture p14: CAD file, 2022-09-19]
Building Kits/hobby/h4 GB.stl
130.6 x 95.6 x 40.0

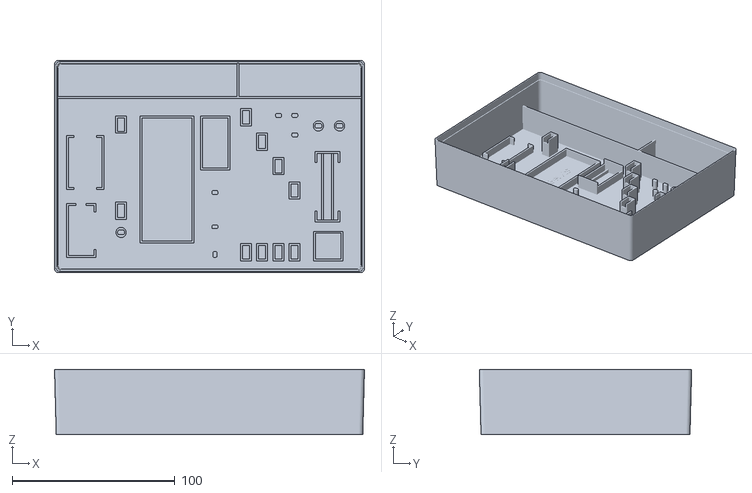
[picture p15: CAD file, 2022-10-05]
Building Kits/PLUS/MotorSetXS.stl
190.6 x 130.6 x 40.0

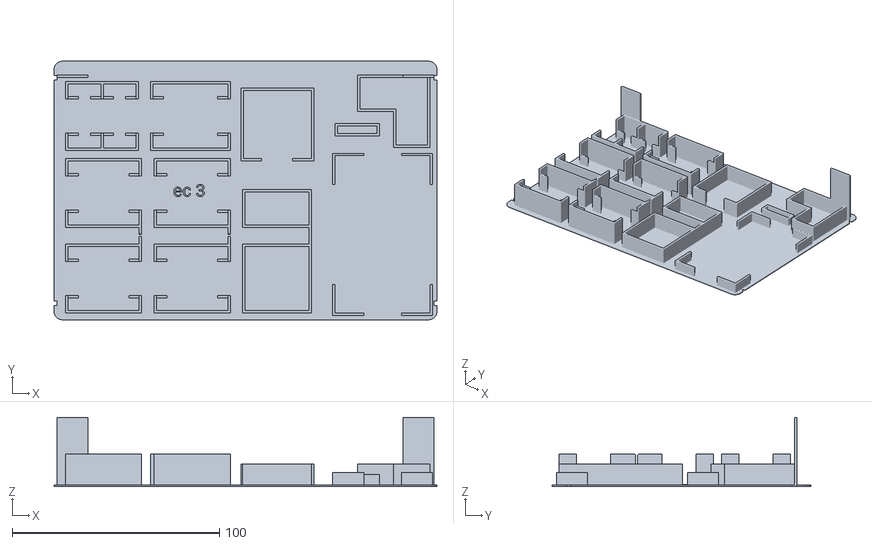
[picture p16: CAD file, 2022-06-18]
Original Building Kits/ec/ec3_inlay.stl
184.7 x 124.7 x 33.3

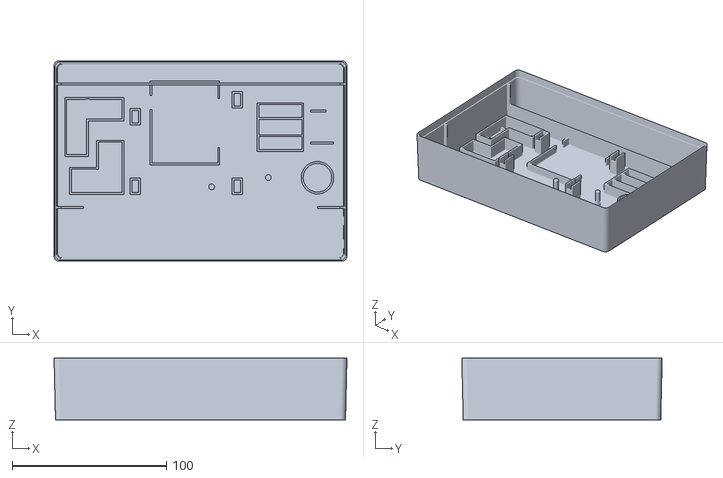
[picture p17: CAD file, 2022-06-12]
Original Building Kits/mot/mot1.stl
190.0 x 130.0 x 40.0

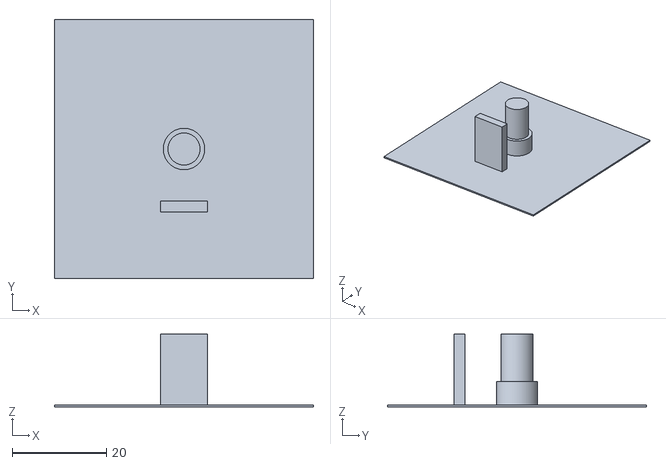
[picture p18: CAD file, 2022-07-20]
Test/Print/TestPrintHolderPropellerFourBlades.stl
55.0 x 55.0 x 15.4

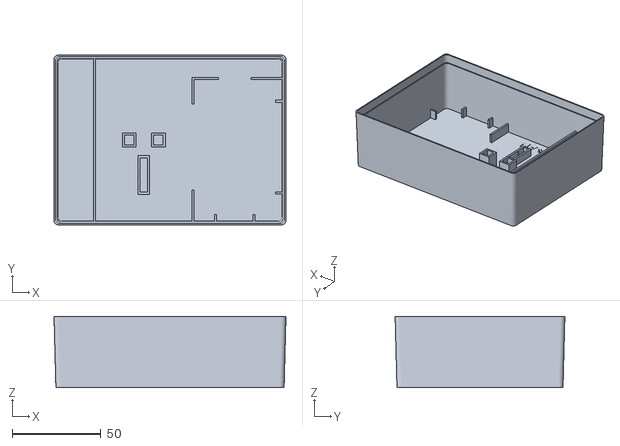
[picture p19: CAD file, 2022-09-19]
Building Kits/hobby/h4 AN.stl
130.6 x 95.6 x 40.0

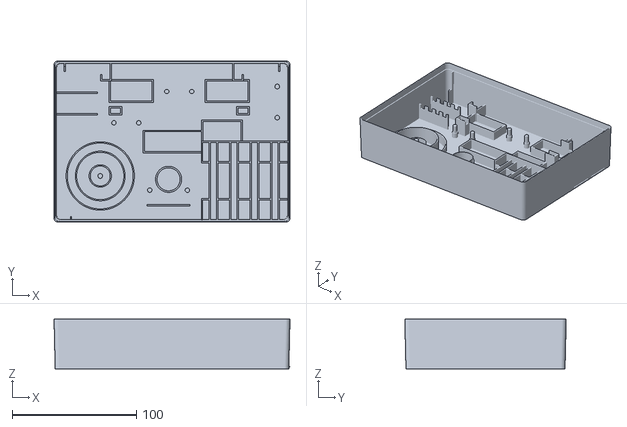
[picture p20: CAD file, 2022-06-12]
Original Building Kits/mot/mot3.stl
190.0 x 130.0 x 40.0

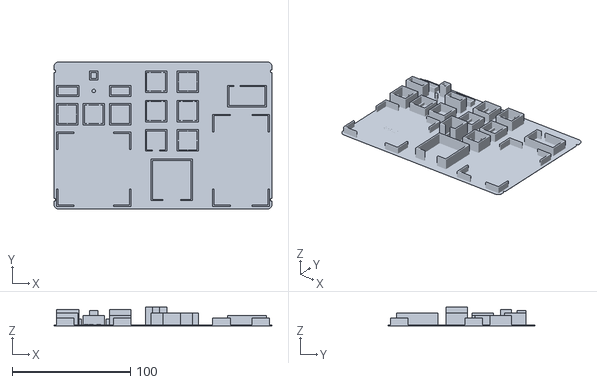
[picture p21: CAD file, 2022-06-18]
Original Building Kits/ec/ec2_inlay.stl
184.7 x 124.7 x 15.8

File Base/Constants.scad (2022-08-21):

// Fischertechnik Box Foundation
// Constants

// Constant values necessary for multiple elements

// Base constants
dividerThickness = 1.2;
excess = 0.01;
fragments = 90;
tolerance = 0.8;

// Gets the thickness of a divider 
function getDividerThickness() = dividerThickness;

// Gets the excess that is used to merge walls into each other
function getExcess() = excess;

// Gets amount of fragments of a cylinder
function getFragments() = fragments;

// Gets the inner tolerance of a frame to each side
function getTolerance() = tolerance;


// Fischertechnik specific constants
axisDiameter = 4;
axisBottomDiameter = axisDiameter + 1;
axisTolerance = 0.2;
axisLockingLength = 8;

// Gets axis diameter of Fischertechnik axis
function getAxisDiameter() = axisDiameter;

// Gets axis diameter tolerance (subtracted for element axis)
function getAxisTolerance() = axisTolerance;

// Gets the axis diameter for standing axis
function getStandAxisDiameter() = getAxisDiameter() - getAxisTolerance();

// Gets axis bottom diameter for thicker part at the bottom
function getAxisBottomDiameter() = axisBottomDiameter;

// Gets the lengthh of the locking part of a locking axis
function getAxisLockingLength() = axisLockingLength;

// Studs

studHeight = 2.5;
studTolerance = 0.2;
studRailDistance = 9;   // as in ft 50

// gets the height of a connecting stud
function getStudHeight() = studHeight;

// gets the connecting stud height tolerance
function getStudTolerance() = studTolerance;

// gets the default rail distance for studs
function getStudRailDistance() = studRailDistance;

// Dockable Frame with Edge

standardEdgeDistance = 2.5;
standardWebDistance = 11.5;
standardCornerLength = 15;

// gets the standard distance to the wall of the box for dockable frames with webs
function getStandardEdgeDistance() = standardEdgeDistance;

// gets the standard distance of each web to the corner of the dockable frame
function getStandardWebDistance() = standardWebDistance;

// gets the standard length of the corner walls of a dockable frame
function getStandardCornerLength() = standardCornerLength;

// Tubes

tubeWallFactor = 0.8;

// gets the wall thickness of a tube.
function getTubeWallThickness() = tubeWallFactor * getDividerThickness();

// Small Parts and Divider Frame

smallPartsFrameHeight = 20;

// gets the frame height for docked small parts boxes.
function getSmallPartsFrameHeight() = smallPartsFrameHeight;

// Hubs

hubRingDiameter = 19.5;
hubRingLevelDiameter = 21;

// gets the diameter of a tube matching the inner ring of a wheel
function getHubRingDiameter() = hubRingDiameter;

// gets the diameter of a hub tube with a thicker diameter
function getHubRingLevelDiameter() = hubRingLevelDiameter;

// Struts

strutAddLength = 9.0;
strutDepth = 8.0;
strutThickness = 2.8;
strutOuterTolerance = 0.6;

// gets the full length of a strut (nominal length plus 2x radius at the ends)
function getFullStrutLength(length) = length + strutAddLength;

// gets the radius of the end of a strut
function getStrutEndRadius() = strutAddLength / 2;

// gets the the depth (width) of a strut
function getStrutDepth() = strutDepth;

// gets the the thickness of a strut
function getStrutThickness() = strutThickness;

// gets the tolerance added to the strut sizes for strut holders
function getStrutOuterTolerance() = strutOuterTolerance;

// Propeller

propellerAxisDiameter = 7.0;
propellerAxisTolerance = 0.2;

// gets the propeller axis outer diameter
function getPropellerAxisDiameter() = propellerAxisDiameter;

// gets the propeller axis printing tolerance
function getPropellerAxisTolerance() = propellerAxisTolerance;

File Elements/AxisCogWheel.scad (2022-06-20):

// Fischertechnik Box Library
// Axis for Cog Wheel 10 and Bevel Gear Wheel
// 31047 and 31051

use <../Base/Constants.scad>
use <../ModelBase/Simple.scad>

/* [Hidden] */
space = 20;

// getAxisCogWheelSpace()
// Gets the space the winch drum holder needs as width (.x and .y as a list)

function getAxisCogWheelSpace() = [space, space];

// AxisCogWheel()
// Standing axis for a cog wheel 31047 or
// a bevel gear wheel 31051

module AxisCogWheel() {
    height = 11.8;
    AxisWithSpace(height, getAxisCogWheelSpace());
}

// Tests
color("lightgray")
AxisCogWheel();

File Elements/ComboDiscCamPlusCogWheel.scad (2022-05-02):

// Cylinder and Axis for Disc-Cam plus Axis for CogWheel
// 31038 plus 31047 or 31051

use <AxisCogWheel.scad>
use <CylinderAndAxisDiscCam.scad>

// getComboDiscCamPlusCogWheel()
// Gets the space the combo of disc cam plus cog wheel needs as width and depth (.x and .y as a list)

function getComboDiscCamPlusCogWheelSpace() = [getCylinderAndAxisDiscCamSpace().x, getCylinderAndAxisDiscCamSpace().y];

// ComboDiscCamPlusCogWheel()
// Standing cylinder with axis for disc-cam 31038
// plus cog wheel axis centered in the cylinder

module ComboDiscCamPlusCogWheel() {
    CylinderAndAxisDiscCam();
    offsetX = (getCylinderAndAxisDiscCamSpace().y - getAxisCogWheelSpace().x) / 2;
    offsetY = (getCylinderAndAxisDiscCamSpace().y - getAxisCogWheelSpace().y) / 2;
    translate([offsetX, offsetY, 0])
        AxisCogWheel();
}

// Tests
color("lightgray") {
    ComboDiscCamPlusCogWheel();
}

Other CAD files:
Building Kits/PROFI/Electronics Box2.stl
Building Kits/PROFI/Electronics Box3.stl
Original Building Kits/ec/ec3.stl
Original Building Kits/mot/mot2.stl
Building Kits/hobby/h4 G.stl
Building Kits/PROFI/Electronics Box1.stl
Original Building Kits/ec/ec1.stl
Building Kits/hobby/h4 ML.stl
Original Building Kits/ec/ec2.stl
Building Kits/hobby/h4 RB.stl
Elements/ComboFlatHubLargePulleyWheel.scad
Base/Alignment.scad
Base/BoxInlays.scad
Base/Boxes.scad
Base/Deployment.scad
Base/Helper.scad
Base/Placement.scad
Base/PlacementOptions.scad
Base/Rotation.scad
Building Kits/ElectronicBlockBoxBase.scad
Building Kits/PLUS/MotorSetXS.scad
Building Kits/PROFI/Electronics Box1.scad
Building Kits/PROFI/Electronics Box2.scad
Building Kits/PROFI/Electronics Box3.scad
Building Kits/hobby/ElectronicBlockBoxBase.scad
Building Kits/hobby/h4 AN.scad
Building Kits/hobby/h4 FF.scad
Building Kits/hobby/h4 FF.stl
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

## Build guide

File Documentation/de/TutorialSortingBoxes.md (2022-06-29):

# Wie konstruiere ich einen Sortierkasten?
Im folgenden Tutorial erfährt man
- was man braucht
- wie man startet
- wie man Elemente platziert

## Was brauche ich?
- Computer
- [OpenSCAD](https://openscad.org/) - gibt's für alle größeren Betriebssysteme und experimentell auch schon über WebAssembly im Browser
- [Kenntnisse](https://openscad.org/documentation.html#tutorial) der SCAD-Sprache
- Download oder Fork [dieser Bibliothek](https://github.com/proggi64/fischertechnik-box-foundation) auf dem lokalen Computer
- 3D-Drucker mit mindestens 20 x 14 cm Druckfläche (oder 3D-Druck-Dienstleister)

## Erste Schritte: Eine kleine Box für den Elektronik-Grundbaustein
Ziel des Tutorials ist der Bau eines 130 x 95 kleinen Sortierkastens, in den der Silberling mitsamt Verbindungsstecker, Drehknopf, zwei Kontrollleuchten und einigen Kleinteilen Platz findet. Der Kasten ist nur halb so groß wie ein Standardeinsatz im Fischertechnik-Kasten 1000. Wenn man den auf einen Sortierkasten 190 x 130 stapelt, hat man daneben noch Platz für einen zweiten.

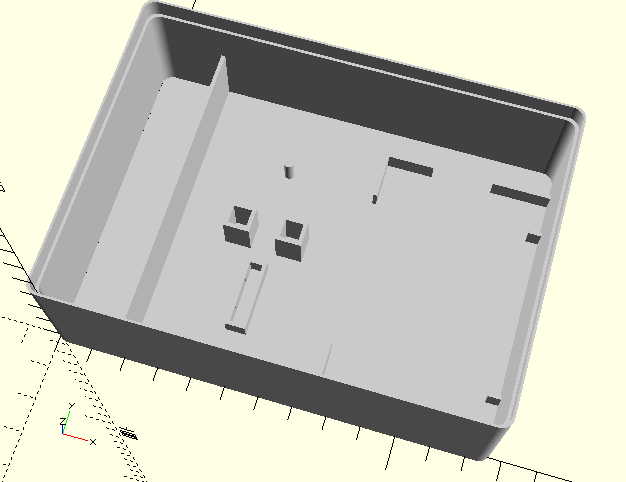
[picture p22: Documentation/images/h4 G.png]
h4 G


Falls man sein Ergebnis hier auf GitHub veröffentlichen will: Der Platz für Eigenentwürfe ist im Ordner __Building Kits__ vorgesehen. Die relativen Pfade bei den __use__-Anweisungen gehen davon aus, dass die Dateien dort in einem weiteren Unterverzeichnis stehen. Das Beispiel hier existiert bereits im Unterverzeichnis __hobby__ als __h4 GB.scad__.

### Neue SCAD.Datei
Wir legen die SCAD-Datei an und speichern sie.

- OpenSCAD starten
- __Datei__ | __Neue Datei__
- Optional: Kommentarzeilen, die die Box identifizieren

```
// Box 130x95
// h4 G
// Elektronik Grundbeistein
// 39581
```

- __Datei__ | __Datei speichern__

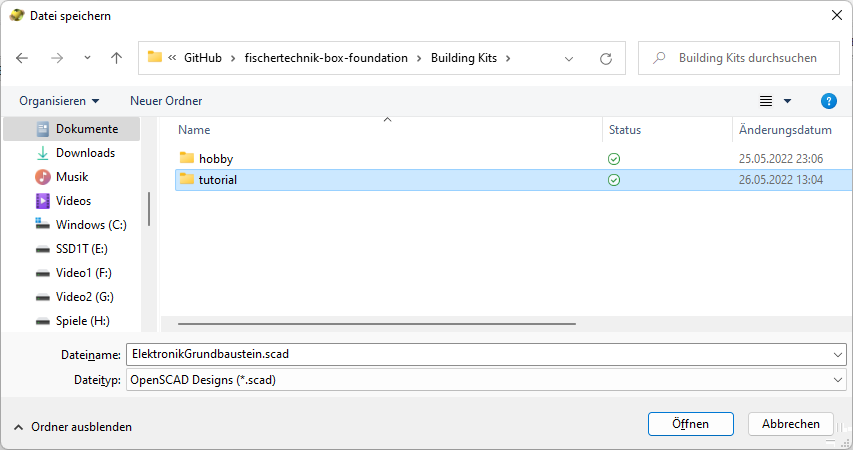
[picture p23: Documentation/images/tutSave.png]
Datei speichern
)

Erst nach dem Speichern können die Pfade der noch folgenden __use__-Anweisungen aufgelöst werden, damit wir ein Vorschaubild unseres Kastens sehen können.

Wenn wir die Datei wie hier im Beispiel innerhalb der Pfadstruktur der Bibliothek anlegen (hier __tutorial__), bauen wir automatisch eine Kopplung an GitHub auf, d.h. wir können unser Beispiel auch ins Git pushen, falls wir einen Fork statt eines Downloads verwenden. Wem das zu kompliziert ist, dem sei empfohlen, einfach die Bibliothek per Download zu holen.

### Der Basiskasten
Wir legen den Basiskasten 130 x 95 an. Dieser ist die halb so große Version der acht Standard-Sortierkästen aus der Box 1000. Für unseren Silberling reicht das, für alle größeren gibt's die [__Box190__](Base/Box190.md).

- per __use__ Base/Boxes.scad importieren
- [__Box130__](Base/Box130.md) aufrufen, um diesen Grundkasten als Element zu verwenden

```
use <../../Base/Boxes.scad>

Box130();
```

Die leere Box wird so platziert, dass die Oberfläche des Bodens exakt auf Höhe 0 liegt. Der verwendbare Bereich liegt an X/Y-Position 0,0, so dass man die Wände bei der Positionierung nicht berücksichtigen muss.

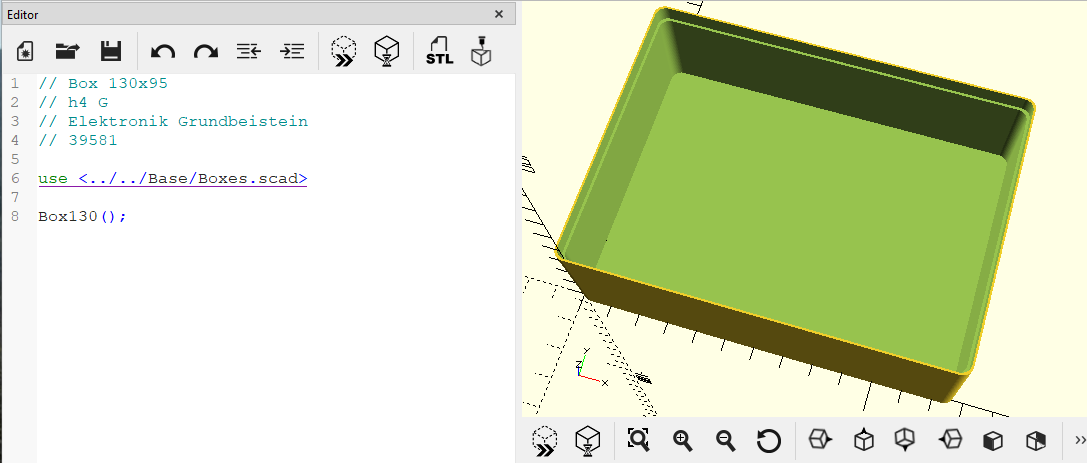
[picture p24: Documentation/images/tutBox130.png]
Box 130
)

### Für die Kleinteile
Wir erzeugen eine Trennwand für den Bereich, in den später die Kabel, der Kondensator und der Widerstand Platz finden.

- per __use__ ModelBase/Simple.scad importieren
- mit [__Divider__](ModelBase/Divider.md) die Trennwand erzeugen

```
use <../../Base/Boxes.scad>
use <../../ModelBase/Simple.scad>

Box130();

boxSpace=getBox130Space();
dividerWidth = 20;

Divider(dividerWidth, boxSpace=boxSpace);
```

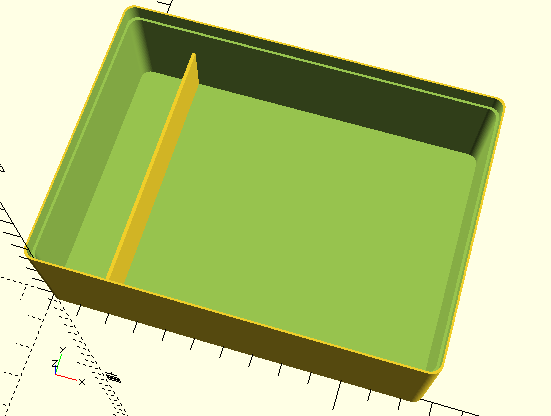
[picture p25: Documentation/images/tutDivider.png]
Divider
)

Zumeist ist es eine gute Idee, konstante Werte Variablen zuzuweisen. Wir brauchen diese später noch an anderen Stellen, deswegen werden hier *boxSpace* und *dividerWidth* zugewiesen, bevor sie __Divider__ übergeben werden.

Zwei Anmerkungen zu SCAD:

"Variablen" sind nicht variabel. Sie können nicht wie in den prozeduralen Sprachen Java oder C verändert werden. Stattdessen bekommen sie den zuletzt zugewiesenen Wert, und der gilt auch in allen Zeilen desselben Gültigkeitsbereichs zuvor. Wenn in Zeile 10 x=5 steht und in Zeile 20 x=10, dann hat x in Zeile 10 schon den Wert 10. Eine Warnung in der Konsole bei der Ausführung weist zumindest auf die überschreibende Zuweisung hin. Wenn man Variablen verändern will, muss man die __let__-Anweisung verwenden.

Optionale Parameter kann man durch Angabe des Parameternamens beim Aufruf setzen. Das passiert in unserem Beispiel, wo der Name des optionalen Parameters *boxSpace* zufällig dem der Variablen *boxSpace* entspricht. Was was ist, erkennt SCAD am Kontext, gleiche Namen sind hier also erlaubt und durchaus sinnvoll.

### Für den Silberling
Wir erzeugen einen an zwei Wände angedockten Rahmen für den Silberlink rechts vorne in der Ecke.

- per __use__ Elements/FrameElectronicBlock.scad importieren
- per __use__ Base/Placement.scad importieren
- per __include__ Base/PlacementOptions.scad importieren
- Aufruf von [__FrameElectronicBlock__](Elements/FrameElectronicBlock.md) mit den richtigen Werten
- Platzieren mit dem [__Place__](Base/Place.md)-Modul

```
use <../../Base/Boxes.scad>
use <../../Base/Placement.scad>
use <../../ModelBase/Simple.scad>
use <../../Elements/FrameElectronicBlock.scad>

include <../../Base/PlacementOptions.scad>

Box130();

boxSpace=getBox130Space();
dividerWidth = 20;
electronicBlockSpace = getFrameElectronicBlockSpace(alignX=AlignRight, alignY=AlignBottom);

Divider(dividerWidth, boxSpace=boxSpace);

Place(alignX=AlignRight, alignY=AlignBottom, 
    elementSpace=electronicBlockSpace,
    boxSpace=getBox130Space())
    FrameElectronicBlock(alignX=AlignRight, alignY=AlignBottom);
```

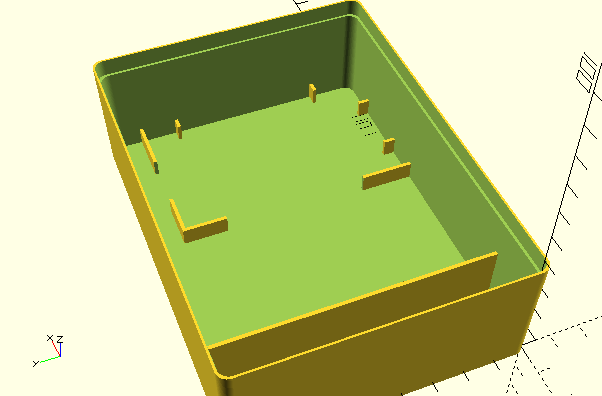
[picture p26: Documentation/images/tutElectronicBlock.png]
FrameElectronicBlock
)

Placement.scad enthält das [__Place__](Base/Place.md)-Modul. Das kann u.a. Elemente auf Flächen ausrichten. Das verwenden wir hier, um das Element [__FrameElectronicBlock__](Elements/FrameElectronicBlock.md) in der vorderen rechten Ecke zu verankern.

Dafür benötigt __Place__ die Fläche, die das Element hat (*elementSpace*), und die Fläche, auf der ausgerichtet wird ([__getBox130Space__](Base/getBox130Space.md)). In OpenSCAD kann man das nicht über das Element ermitteln, sondern muss es explizit in einer separaten Funktion zur Verfügung stellt. jedes Element der Bibliothek hat dafür die Funktion mit den Namensschema __get*ElementName*Space()__, wobei man *ElementName* durch den tatsächlichen namend es Elements ersetzen muss. Hier verwenden wir __getframeElectronicBlockSpace()__.

Damit die Funktion __getframeElectronicBlockSpace()__ dies auch korrekt errechnen kann, benötigt es die notwendigen Parameter. Die meisten Element haben keine Parameter, so das man dort auch der Funktion keine übergeben muss. Hier verändert sich aber der Rahmen durch die Angabe, an welche Seiten angedockt werden soll, und dadurch verändert sich auch die Fläche des Elements.

Die Parameter *xAlign* und *yAlign* sind optional. Wenn der Rahmen nicht angedockt wird, fallen beide weg. Da wir hier an zwei Seiten docken, brauchen wir aber beide. Es gibt einige Elemente, die auch durch Andocken ihre Gestalt ändern, und bei allen werden dieselben Parameter verwendet. Damit man sich keine Zahlen merken muss, wurden in der Datei __Base/PlacementOptions.scad__ Variablen mit sprechenden Namen definiert, die man hier als Werte für die Variablen übergeben kann. Diese Datei muss als einzige per __include__ eingebunden werden, da __use__ keine Variablen, sondern nur Funktionen und Module importiert. Bei den Beschreibungen aller Module und Elemente, die solche Wert verwenden können, sind diese Namen dokumentiert.

Das Ergebnis: Der Rahmen für den Silberling sieht so aus, wie er auch in den ec-Kästen vorkommt. Es werden Stege als Abstandshalter zu den Wänden generiert, die mit den Außenwänden verschmelzen. Wenn man ein "#" vor [__Box130__](Base/Box130.md) stellt und dadurch die Box teilweise transparent macht, kann man diese Verschmelzung gut erkennen.

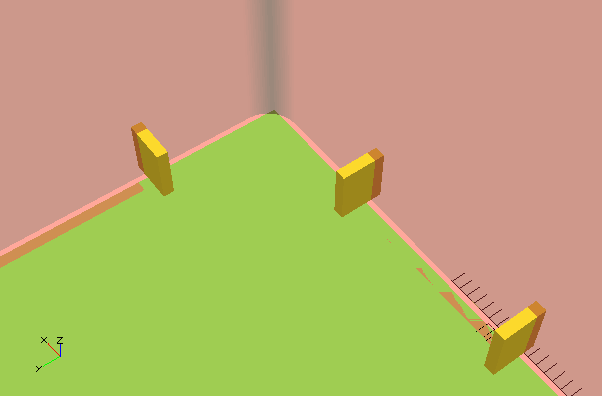
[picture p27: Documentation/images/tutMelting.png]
Dock Melting
)

Einige Elemente in der Bibliothek unterstützen explizit das Andocken. Die Vorbilder dazu finden sich in den Kunststoffkästen von Fischertechnik, wie sie in den 70er Jahren geliefert wurden.

### Elemente für die Spezialteile
Ziel der Bibliothek ist es, einen umfangreichen Grundstock an Elementen zur Verfügung zu stellen. Für unseren Kasten sind die Elemente bereits alle vorhanden:

- [__FrameElectronicBlockConnector__](Element/FrameElectronicBlockConnector.md) für die Verbindungsstecker
- [__FrameControlLight__](Elements/FrameControlLight.md) für die Kontrolllämpchen
- [__AxisDial__](Elements/AxisDial.md) für die Drehknöpfe

Um auf diese Element zugreifen zu können, fügen wir oben im Code die folgenden __use_-Anweisungen ein:

```
use <../../Elements/FrameControlLight.scad>
use <../../Elements/AxisDial.scad>
use <../../Elements/FrameElectronicBlockConnector.scad>
```

### Vorbereitung der Platzierung
Jetzt müssen wir die Elemente noch platzieren. Kriterien sollten dabei sein:
- Hinreichend Platz ohne Konflikte zu benachbarten Bausteinen
- Hindernisfreier Zugriff ohne andere Bauteile herausnehmen zu müssen
- Übersichtlichkeit und eine Portion Ästhetik

Der freie Platz zwischen dem Silberling und der Trennwand links bietet sich für die Elemente an. Die Bibliothek stellt einige Module zur Verfügung, die Elemente ausrichten oder verteilen können. Prinzipiell kann man sich auch auf die mit OpenSCAD gelieferten Funktionalitäten beschränken, aber Ausrichten und Verteilen kann OpenSCAD nicht von allein.

Nachträgliche Veränderungen fallen in einigen Situationen leichter, wenn die Positionen relativ zueinander berechnet werden, anstatt sie alle absolut anzugeben. Dadurch kann die Änderung eines Wertes reichen, um eine Korrektur durchzuführen. Das muss aber nicht immer so sein. Hier muss man sich vorher die Frage stellen, wo Änderungen und Anpassungen während des Entwurfs am wahrscheinlichsten sind und welche Wirkung das haben kann.

In unserem Fall werden Position und Größe der freien Fläche mit relativen Werten bezogen auf die beiden schon platzierten Elemente berechnet. Jetzt brauchen wir noch die Datei __Base/Constants.scad__:

```
use <../../Base/Constants.scad>
```

Hier finden wir Funktionen, die Standardwerte liefern, z.B. die Stärke von Trennwänden ([__getDividerThickness__](Base/getDividerThickness.md)), den Durchmesser von Fischertechnik-Achsen ([__getAxisDiameter__](Base/getAxisDiameter.md)), die Toleranzen und eine Reihe weiterer Werte.

```
    boxSpace=getBox130Space();

    electronicBlockSpace = getFrameElectronicBlockSpace(alignX=AlignRight, alignY=AlignBottom);
```

Wie weiter oben schon gezeigt, benötigen wir die tatsächliche Fläche des Rahmens für den Silberling und stellen sie in die Variable *electronicBlockSpace*.

```
    dividerWidth = 20;
    leftOffset = dividerWidth + getDividerThickness();
    rightOffset = getBox130Space().x - electronicBlockSpace.x;
```

Auch die Breite des Fachs mit der Trennwand spielt eine wichtige Rolle und wird in *dividerWidth* gespeichert. *leftOffset* wird dann berechnet, indem zu diesem betrag noch die Stärke der Trennwand addiert wird. Ab dort beginnt der freie Platz links.

Für *rightOffset* rechnen wir die Breite des nutzbaren BEreichs des Sortierkastens und ziehen den Platz für den Rahmen des Silberlings ab. Die Stärke von dessen Trennwand ist bereits im Wert entahlten, den *electronicBlockSpace* gespeichert hat.

Damit haben wir die linke und rechte X-Position des freien Bereichs.

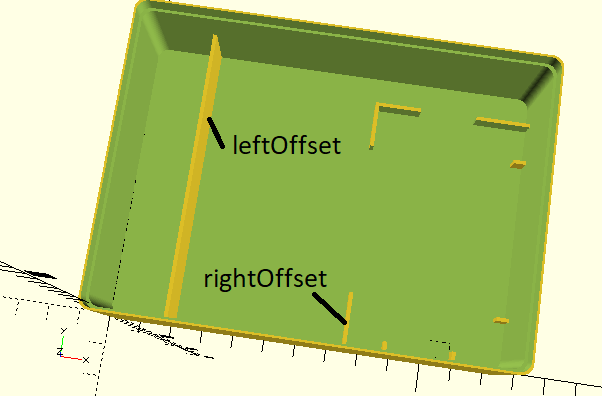
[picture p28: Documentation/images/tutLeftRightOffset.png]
Left Right Offset
)

```
    distance = 15;
    bottomOffset = 15;
    topOffset = 15;

    partsSpace = [rightOffset - leftOffset - 2*distance, boxSpace.y - bottomOffset - topOffset];
```

Die Abstände zu diesen Positionen legen wir mit konstanten Werten fest und stellen sie in diese Variablen:
- *distance*: Abstand der Fläche zur linken Trennwand und rechts zum Rahmen des Silberlings
- *bottomOffset*: Abstand zur unteren Wand des Kastens
- *topOffset*: Abstand zur oberen Wand des Kastens

Damit können wir auch den Platz berechnen, der für die Teile genutzt werden soll. Dieser wird in *partsSpace* als \[x,y]-Liste abgelegt.

- *partsSpace*: Fläche, auf dem die Spezialteile platziert werden

Hilfreich für die Konstruktion ist es oft, diese Fläche über ein transparentes Rechteck sichtbar zu machen. Das kann man nach dem Platzieren wieder löschen, hilft aber für die Einschätzung und ob alles richtig gerechnetund platziert wurde:

```
partsXPosition = leftOffset + distance;
partsYPosition = bottomOffset;

Place(partsXPosition, partsYPosition) {
    #cube([partsSpace.x, partsSpace.y, 2]);
}
```

- *partsXPosition*: X-Position der Fläche
- *partsYPosition*: Y-Position der Fläche, identisch mit *bottomOffset*, aber für die Lesbarkeit...

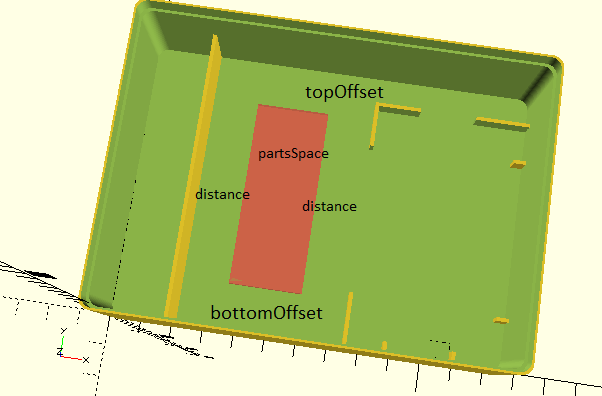
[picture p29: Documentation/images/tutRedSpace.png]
Parts Space
)

Das ist also die Ausgangsposition, um die letzten Elemente zu platzieren. *partsSpace* und die Koordinaten brauchen wir beim nächsten Schritt.

Die gute Nachricht ist, dass die Bibliothek das Konstruieren der Kästen weitestgehend mit nur zweidimensionsionaler Geometrie ermöglicht. um die dritte Dimension kümmern sich die vorgefertigten Elemente.

### Verteilen der Elemente
Wir brauchen jetzt noch eine weitere __use__-Anweisung:

```
use <../../Base/Deployment.scad>
```

*Deployment.scad* liefert uns Zugriff auf die Module zur Verteilung von Elementen. Wir wollen davon das Modul [__DeploySame__](Base/DeploySame.md) verwenden.

Jetzt werden noch die drei Elemente [__FrameElectronicBlockConnector__](Elements/FrameElectronicBlockConnector.md), [__FrameControlLight__](Elements/FrameControlLight.md) und [__AxisDial__](Elements/AxisDial.md) auf der Fläche verteilt.

Wir starten mit [__FrameElectronicBlockConnector__](Elements/FrameElectronicBlockConnector.md):

```
Place(partsXPosition, partsYPosition) {
    #cube([partsSpace.x, partsSpace.y, 2]);

    DeploySame(partsSpace, getFrameElectronicBlockConnectorSpace(), rotation=Rotate90, columns=1)
        FrameElectronicBlockConnector();
```

[__DeploySame__](Base/DeploySame.md) erzeugt und verteilt das angegebene __children__-Element einmal oder mehrfach. Es hat eine Reihe optionaler Parameter. In unserem Fall wollen wir nur ein Element (*columns*=1), und dieses soll um 90° gedreht werden. Weil keine weiteren Koordinaten angegeben sind, wird das eine Element mittig unten (lokale 0-X-Position) auf der Fläche platziert.

Damit die Rotation und die Verteilung möglich sind, müssen sowohl die Fläche des Elements, wie auch die Zielfläche angegeben werden.

Alternativ kann man in unserem Fall mit dem einen Element auch [__Center__](Base/Center.md) verwenden. Durch [__DeploySame__](Base/DeploySame.md) können wir aber durch Setzen von *columns* auf 2 einfach zwei Elemente platzieren. Diese werden dann links und rechts an den Rand gestellt. Bei 3 wären die drei Elemente im gleichen Abstand verteilt. Einfach mal im Code ausprobieren.

In denselben Block setzen wir jetzt die Kontrolleuchten:
```
    CenterVertical(depth=getFrameControlLightSpace().y, space=partsSpace)
        DeploySame(partsSpace, getFrameControlLightSpace())
            FrameControlLight();
```

Standardwert für *columns* ist 2, so dass wir durch Weglassen dieses optionalen Parameters Rahmen für zwei Kontrollleuchten bekommen. Mit [__CenterVertical](Base/CenterVertical.md) sorgen wir dafür, dass das Element vertikal mittig platziert wird.

Zum Schluss noch die Achse für den Drehregler, wieder innerhalb desselben Blocks:
```
    Place(elementSpace=getAxisDialSpace(), alignY=AlignTop, alignX=AlignCenter, boxSpace=partsSpace)
        AxisDial();
```

Die Ausrichtung oben in der Fläche erledigt wieder [__Place__](Base/Place.md) mit dem Parameterwerten *alignY*=__AlignTop__ und *alignX*=__AlignCenter__.

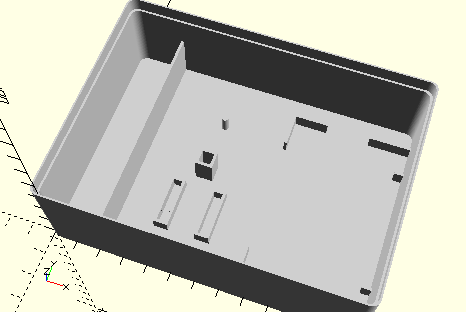
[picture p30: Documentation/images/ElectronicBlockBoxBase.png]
BoxSilberling


## Ausblick
Das Beispiel mit dem Silberling ist eine vereinfachte Variante der flexibler einsetzbaren SCAD-Datei *BuildingKits/hobby/ElectronicBlockBoxBase.scad*. Bei diesem Modul kann die Anzahl der Spezialelemente jeweils als Parameter übergeben werden, so dass Kästen für Silberlinge mit 0 bis 2 Drehknöpfen oder Kontrollleuchten nur durch Parameter erzeugt werden können. Das Modul unterstützt dabei auch den Customizer von OpenSCAD, um diese Parameter dynamisch in der Oberfläche zu setzen.

Voraussichtlich werden immer wieder neue Elemente hinzukommen, aber auch komfortablere Verteil- und Platzierungsfunktionen. Am besten immer wieder mal die neue Version holen.

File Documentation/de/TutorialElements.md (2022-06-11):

# Wie konstruiere ich ein Element für Bauteile?
Im folgenden Tutorial erfährt man
- was man braucht
- wie man startet
- wie man konstruiert
- wie man dokumentiert

## Was brauche ich?
- Computer
- [OpenSCAD](https://openscad.org/) - gibt's für alle größeren Betriebssysteme und experimentell auch schon über WebAssembly im Browser
- [Kenntnisse](https://openscad.org/documentation.html#tutorial) der SCAD-Sprache
- Download oder Fork [dieser Bibliothek](https://github.com/proggi64/fischertechnik-box-foundation) auf dem lokalen Computer
- Optional: Schieblehre zum exakten Ausmessen von Teilen
- Optional: [Visual Studio Code](https://code.visualstudio.com/?wt.mc_id=DX_841432) als Editor und die Erweiterungen [scad](https://marketplace.visualstudio.com/items?itemName=efbenson.scad) und [Markdown Preview Github Styling](https://marketplace.visualstudio.com/items?itemName=bierner.markdown-preview-github-styles).

Ich verwende Visual Studio Code als Editor, weil
- der Editor komfortabler als der von OpenSCAD ist
- alles automatisch in Git über die Quellcodeverwaltung gebunden ist (direkt auf GitHub)
- die Dokumentation per Markdown und Vorschau komfortabel integriert werden kann
- für SCAD und Markdown eigene Code-Snippets die Tipparbeit minimieren (siehe Ordner __VS Code Snippets__)
- mit dem zweiten Monitor OpenSCAD "live" 

## Erste Schritte: Halterung für Winkelachse
Ziel des Tutorials ist die Konstruktion eines Achshalters für die Winkelachse 31035, wie sie im Kasten 50/2 vorkommt. Solche 3D-Objekte werden in diesem Projekt als __Element__ bezeichnet. Elemente können in den Sortierkästen platziert werden.

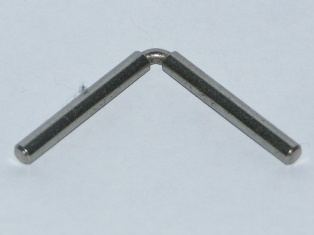
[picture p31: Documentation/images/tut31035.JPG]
Winkelachse 31035


### Was kennzeichnet ein Element?
- Sie halten ein oder mehrere Bauteile oder Kombinationen davon
- Sie werden als SCAD __module__ entworfen
- Es wird immer eine __function__ mitgeliefert, die den 2D-Flächenbedarf liefert
- Sie können einfache Parameter verwenden, z.B. Anzahlen oder Informationen für das Andocken an die Seitenwand
- Sie sollten leicht und ohne Stützstruktur mit einem 3D-Drucker druckbar sein

### Tipps für die Konstruktionsschritte
- Maße des Bauteils z.B. mit einer (elektronischen) Schieblehre ermitteln
- Vorbilder in den "alten" Sortierkästen suchen
- Hilfsfunktionen für Grundformen im Ordner *ModelBase* kennenlernen 
- Hilfsfunktionen ür das Platzieren und Ausrichten im Ordner *Base* kennelernen
- Funktionen für Konstanten im Ordner *Base* kennenlernen
- Ähnliche Konstruktionen im Ordner *Elements* sichten

## Wir legen die Element-Datei an
Wer Elemente nicht im Github veröffentlichen will, kann beim Namen natürlich frei entscheiden. Für Elemente, die veröffentlicht werden sollen, ist allerdings die Einhaltung des Namensschemas für die Dateinamen hilfreich:

*Grundform in englisch* - *Name des Bauelements in englisch* . __scad__.

Das Ganze wird zusammengeschrieben, z.B. __FrameBracketWithAxle80.scad__ oder __CylinderHub.scad__.

Grundformen gibt es folgende:
- __Axis__: Stehende Achse, z.B. für Räder oder Naben
- __Cylinder__: Stehender Zylinder, z.B. für Reifen oder Zahnräder
- __Frame__: Rahmen, z.B. für Bausteine

Außerdem werden für komplexere Elemente noch diese Begriffe verwendet:
- __Combo__: Kombination mehrerer Elemente, z.B. für Schaufelteile oder komplette Lenkungen
- __Holder__: Halterungen, die keiner der Grundformen so richtig zuzuordnen sind

Das Schema ist kein Gesetz, sondern soll lediglich eine Orientierung darstellen.

Alle SCAD-Dateien verwenden die englischen Bezeichnungen der Bauteile im Namensschema. Diese sind nicht immer einfach herauszufinden. In den "alten" Anleitungen aus den 70ern sind viele dieser Bezeichnungen in mehreren Sprachen abgedruckt, das hilft. Ansonsten kann man auch die üblichen Übersetzer im Internet verwenden. Auch hier gilt: Es soll eine grobe Orientierung sein.

Für die Winkelachse 31035 findet man in der Anleitung des Kastens 50/3 die englische Bezeichnung "Angle Axle". Für Achshalterungen wurde bereits unvorsichtigerweise der Präfix __Frame__ verwendet (siehe z.B. [__FrameAxis50__](Elements/FrameAxis50.md)), so dass sich als Name unserer Elementdatei __FrameAngleAxis.scad__ ergibt. Axis statt Axle, weil auch hier die Entscheidung schon getroffen wurde, *axis* statt das eher britische *axle* zu verwenden.

Der Ablauf beim Anlegen der Datei hängt von verwendeten Werkzeug ab. In OpenSCAD wählt man __Datei__ | __Neu Datei__. In Visual Studio Code sollte man die ganze Bibliothek gleich über einen privaten Fork einbinden, dann kann man im Projektbaum mit der rechten Maustaste auf dem Ordner __Tutorial__ (für echte neue Elemente __Elements__) das Kontextmenü aufrufen und __Neue Datei__ auswählen. Die Datei ist dann automatisch auch als Änderung im Git vermerkt und kann später gepusht werden.

Im Kopf der neu angelegten Datei sollten wir gleich beschreiben, was für ein Element die Datei enthält. Dabei ist folgendes Schema hilfreich:

```
// Fischertechnik Box Library
// Frame for Angle Axis
// 31035
```

Die zweite Zeile beschreibt auf englisch den Inhalt, die dritte listet die Fischertechnik-Teilenummern auf (hier ist's nur eine).

## Was wir brauchen: Erste Use-Anweisungen
Wir beginnen am besten mit den Use-Anweisungen, die gleich zu Anfang sehr wahrscheinlich benötigt werden. In den meisten Fällen sind diese Dateien eine gute Idee:

```
use <../Base/Constants.scad>
use <../ModelBase/Simple.scad>
```

### Use Base/Constants.scad
Hier sind Standardwerte als __function__ hinterlegt, z.B. Achsdurchmesser, Wandstärken und Toleranzen. Damit spart man sich nicht nur das eigene Ausmessen dieser Werte, sondern stellt auch sicher, dass die eigenen Elemente immer mit den schon vorhandenen zusammenpassen.

Auf der [Startseite der Dokumentation](Contents.md) findet man alle diese Funktionen unter der Überschrift [Funktionen zur Ermittlung von Konstanten](Contents.md#funktionen-zur-ermittlung-von-konstanten).

### Use ModelBase/Simple.scad
Unter ModelBase/Simple.scad finden sich [einfache Basisformen](Contents.md#module-für-einfache-grundformen) und [dazu hilfreiche Funktionen](Contents.md#funktionen-zur-ermittlung-der-größe-einfacher-grundformen) für die Element-Konstruktion. Hierzu gehören u.a. Rahmen, Zylinder und stehende Achsen.

## Was wir über das Bauteil wissen sollten
Die Messung der Winkelachse ergibt folgende Werte:
- Schenkellänge: 30 mm
- Durchmesser des gebogenen Teils: 2,5 mm
- Gesamtlänge: 34,5 mm (vom einen Ende der Achse zur Rand des dazu quer stehenden Achs-Arms)

Folgende Standardwerte fließen ein:
- Durchmesser Achse: 4 mm ([__getAxisDiameter__](Base/getAxisDiameter.md))
- Höhe von Achshaltern: 15 mm ([__getFrameAxisHeight__](ModelBase/getFrameAxisHeight.md))

Aus dem Fischertechnik-Kasten 50/2 wissen wir, dass ein Steg mit 45° zwischen den zwei Achshaltern am jeweiligen End der Winkelachse den Mittelteil stützt. Auch dieser Steg ist 15 mm hoch und hat eine Aussparung, in die der gebogene Teil mit seinen 2,5 mm passt.

Für den Hinterkopf: In 50/2 sind zwei dieser Achshalter im 45°-Winkel aneinander gereiht, wobei die beiden Stege an den Biegungen zu einem Steg verschmolzen sind.

## Hintergrund: Ein bisschen 3D-Konstruktion mit OpenSCAD
Die Enden der Winkelachse sind in Rahmen gelagert, die eine Aussparung für die Achse haben. Es gibt bei der Konstruktion von Öffnungen und Aussparungen zwei Möglichkeiten:

- Man baut solche Rahmen mit vier einzelnen Wänden (__cube__) mit entsprechenden Höhen
- Man nimmt einen einfachen Rahmen und erzeugt die Aussparungen durch __difference__

In der Bibliothek wurde fast immer die zweite Variante gewählt. Das Modul [__Frame__](Modelbase/Frame.md) erzeugt dafür zwei __cube__ ineinander und zieht den kleineren vom größeren ab. __Frame__ wird als Grundlage praktisch aller Elemente verwendet, deren name mit "__Frame__" beginnt. Die Standard-Wandstärke ist der Wert von [__getDividerThickness__](Base/getDividerThickness.md).

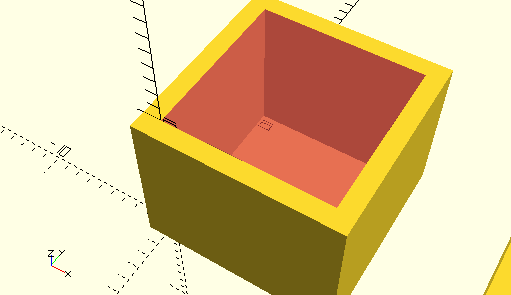
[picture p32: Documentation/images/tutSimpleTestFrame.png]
Frame Difference


Die Abbildung zeigt zwei __cube__ ineinander, wobei der innere hier rot-transparent dargestellt wird. Der Code unten zeigt, wie das in __ModelBase/Simple.scad__ gelöst wurde. __Frame__ kann auch jede einzelne Wand weglassen, deswegen auch der zusätzliche Code.

```
module Frame(volume, tolerance=getTolerance(), openLeft=false, openRight=false, openTop=false, openBottom=false) {
    outerVolume = getFrameOuterVolume(volume, tolerance);
    
    cutoffAdd = getDividerThickness() + getExcess();

    cutoffVolume = [
        volume.x + (openLeft ? cutoffAdd : 0) + (openRight ? cutoffAdd : 0),
        volume.y + (openBottom ? cutoffAdd : 0) + (openTop ? cutoffAdd : 0),
        volume.z];
    innerXOffset = openLeft ? 0-getExcess() : getDividerThickness()+getExcess();
    innerYOffset = openBottom ? 0-getExcess() : getDividerThickness()+getExcess();

    translate([0,0,-getExcess()]) {
        difference() {
            cube(outerVolume);
            // Remove inner and optional each specified wall
            translate([innerXOffset, innerYOffset, getExcess()])
                #cube(getFrameInnerVolume(cutoffVolume, tolerance));
        }
    }
}
```

## Erstmal aufrufbar machen
Die Schnittstelle unseres Elements besteht aus Folgendem:

- __module__ FrameAngleAxis - das 3D-Element
- __function__ getFrameAngleAxisSpace__ - liefert die Fläche des Elements

Dieses Muster gilt für alle Elemente: __module__ und __function__ entsprechen immer diesem Namensschema.

Da wir im Hinterkopf schon wissen, dass die Winkelachse nicht immer allein auftritt und eine Gruppe der Elemente ziemlich speziell angeordnet (45°) und verschmolzen ist, sollte sich um diese Anordnung am besten das Element selbst kümmern, weil hier die notwendigen Daten bekannt sind. Bei einfacheren Elementen sind Gruppen oft auch erst beim Konstruieren der Baukästen leicht zu bilden. Hier sieht es etwas anders aus. Deswegen werden wir gleich als Parameter die Anzahl der Winkelachsen mit einplanen.

Grundsätzlich machen Parameter den Einsatz schwieriger und man muss in der Dokumentation nachschauen. Deswegen sollte es gute Gründe geben, sie einzusetzen:

- Wenn Gruppen mehrerer gleicher Elemente nicht einfach zu erzeugen sind Parameter *count* oder *rows* und *columns*
- Wenn das Andocken an Seitenwände das Element selbst verändert, dann Parameter *dock* oder *alignX* und *alignY*
- Wenn man mehrere einfache Varianten in der Größe benötigt, dann Parameter *length*, *width* oder *height*.

Hilfreich und in jedem Element immer vorhanden: Ein Aufruf des Moduls am Ende der Datei, damit man in der Vorschau von OpenSCAD stets zur Kontrolle sein Element live sehen kann. daraus ergibt sich als Start folgender Inhalt:

```
// Fischertechnik Box Library
// Frame for Angle Axis
// 31035

use <../Base/Constants.scad>
use <../ModelBase/Simple.scad>

function getFrameAngleAxisSpace(count=1) = [0,0];

module FrameAngleAxis(count=1) {

}

// Test
FrameAngleAxis();
```

Wir sehen in der Vorschau jetzt noch nichts, aber beim Aktualisieren in OpenSCAD sollte auch keine Warn- oder Fehlermeldung in der Konsole erscheinen.

## Die Fläche
Die Fläche des Elements umfasst die gesamte Außenfläche, inklusive der Wandstärken von Rahmenwänden. Bei manchen Elementen, bei denen die Bauteile aus dem Rahmen herausragen, werden diese Extra-Spielräume ebenfalls in der Fläche berücksichtigt. Beim Taster ist dies z.B. der Fall, vo der Knopf des Tasters aus dem Rahmen herausragt (siehe [__FrameOushButton__](Elements/FramePushButton.md)).

Um das auch otisch zu untermalen, sollte die gesamte Grundfläche mit dem Modul [__Space__](ModelBase/Space.md) unterlegt werden. __Space__ erzeugt eine dünne Schicht, die später beim Platzieren automatisch in den Boden des Kasten gesenkt wird. Das vermeidet minimale Luftspalte in den 3D-Modellen, die durch Rundungsfehler entstehen können.

Der minmale Platz, den unsere Winkelachse benötigt, ist deren Gesamtlänge (also 34,5 mm) im Quadrat. Dazu müssen wir aber mindestens noch zwei Wandstärken rechnen. Die Rahmen, die die Achse halten, sind mit solchen Wänden eingerahmt.

Prinzipiell würde das reichen. Dennoch kann man am Vorbild im Kaste 50/3 sehen, dass noch etwas zusätzlicher Raum zwischen den im 45°-Winkel aneinanderliegenden Haterungen liegt. Die Messung ergibt hier zusätzliche 1,8 mm nach links und nach unten. Das muss nicht so präzise nachgebaut werden, aber wenn wir diesen Wert schon haben, verwenden wir ihn auch.

### width, depth

Die Variablen- und Parameternamen für Breite, Tiefe und Höhe lauten durchgängig in der Bibliothek *width* (X-Achse), *depth* (Y-Achse) und *height* (Z-Achse). In den Element-Dateien werden die Werte dafür i.d.R. als Variablen vor den __function__- und __module__-Definitionen festgelegt:

```
width = 34.5;
depth = 34.5;
extra = 1.8;
```

Wie man sieht, sind in *width* und *depth* weder Wandstärken, noch die zusätzliche Distanz eingerechnet. *distance* wurde als eigene Variable definiert.

Regel: *width* and *depth* sollen die Fläche des Bauteils angeben.

Das liegt daran, dass mit [__getDividerWidth__](Base/getDividerThickness.md) und [__getTolerance__](Base/getTolerance.md) die zu addierenden Werte über __Constants.scad__ ermittelt werden sollen. Die meisten Bibliotheksmodule und -funktionen erwarten die Bauteilgrößen und addieren intern diese Werte erst dazu. Dadurch wird es viel leichter, zentral Änderungen durchzuführen, wenn sich z.B. die Toleranzwerte als nicht optimal erweisen. Die Bauteilgrößen ändern sich sicher nicht mehr.

### Complex.scad liefert Hilfe

Jetzt müssen wir __getFrameAngleAxisSpace__ noch beibringen, den richtigen Wert zurückzuliefern: Wandstärken und Toleranz, sowie die zusätzlichen 1,8 mm müssen zur Bauteilgröße addiert werden.

Für die Fläche ist es unerheblich, dass es sich um eine um 90° geknickte Achse handelt. Wir können also die Fläche mit der Annahme angeben, dass eine 34,5 mm x 34,5 mm große Platte im Rahmen Platz finden muss. Und für diesen Fall gibt's eine vorgefertige Funktion namens [__getFrameOuterVolume__](ModelBase/getFrameOuterVolume.md). Diese Funktion liefert eine Liste aus drei Werten für X-, Y- und Z-Ausdehnung, eben das Volumen. Eingerechnet sind da schon die Wandstärken und die Toleranz.

Da wir auch eine Höhe als Eingangswert benötigen, der aber für die Fläche nicht relevant ist, können wir einen beliebigen Wert angeben. Trotzdem wäre hier die Standardhöhe der Achshalter keine schlechte Idee. Um an die heranzukommen, brauchen wir noch eine weitere __use__-Anweisung:

```
use <../ModelBase/Complex.scad>
```

### Parameter *count* beeinflusst das Ergebnis

Jetzt kommt noch der Parameter *count* ins Spiel. Bei fast allen Elementen kann man bei der Berechnung der Fläche für mehrere Bauteile mit einfacher Multiplikation der Einzelfläche arbeiten. Hier wäre das falsch: Die Winkelachsen werden im 45°-Winkel relativ eng ineinander geschachtelt. Wir benötigen also die Breite der Achshalter plus 1,8 mm Extra-Platz, damit wir korrekt rechnen. Ein Blick in die Datei __ModelBase/Complex.scad__ bzw. die Dokumentation liefert uns die notwendige Funktion: [__getFrameAxisSpace__](Modelbase/getFrameAxisSpace.md). Der y-Wert entspricht der Breite zweier Wände plus des Durchmessers einer Achse (plus etwas Toleranz).

Wie erwähnt, wollen wir die Fläche gleich auch noch mit [__Space__](ModelBase/Space.md) darstellen, was uns die erste optische Rückmeldung in OpenSCAD beschwert. So sieht alles zusammen aus:

```
// Fischertechnik Box Library
// Frame for Angle Axis
// 31035

use <../Base/Constants.scad>
use <../ModelBase/Simple.scad>
use <../ModelBase/Complex.scad>

width = 34.5;
depth = 34.5;
extra = 1.8;

function getFrameAngleAxisSpace(count=1) = getFrameOuterVolume([
    width + extra + (count-1)*(getFrameAxisSpace().y + extra), 
    depth + extra + (count-1)*(getFrameAxisSpace().y + extra), 
    getFrameAxisHeight()]);

module FrameAngleAxis(count=1) {
    Space(getFrameAngleAxisSpace(count));
}

// Test
FrameAngleAxis();
```

### Hintergrund: Parameter von getFrameOuterVolume
Bei der großen Mehrheit der Elemente ist die Berechnung der Fläche trivial. In unserem Beispiel ist sie zwar keine Raketentechnik, bedarf aber einiger Erklärungen.

[__getFrameOuterVolume__](ModelBase/getFrameOuterVolume.md) benötigt eine Liste aus drei Werten für X-, Y- und Z-Wert. Die werden in OpenSCAD in eckigen Klammern mit Kommas getrennt angegeben.

Wir verwenden den Parameter *count* für die Anzahl der Winkelachsen. Bei nur einer (*count* = 1) entspricht die Fläche den 34,5 mal 34,5 mm plus den Wänden und der Toleranz. Mit jeder weiteren Achse wird aber nur die Breite des Achshalters plus die 1,8 mm Extra-Abstand dazugerechnet. Deswegen wird erst ab *count* = 2 dieser Betrag zu Breite und Tiefe dazugezählt.

Die Funktion [__getFrameAxisSpace__](ModelBase/getFrameAxisSpace.md) arbeitet mit einer Standard-Achlänge von 30 mm für ihren optionalen Parameter *length*. Da wir nur die Breite (y) benötigen, ist die Länge nicht wichtig und wir können den Parameter weglassen.

In der Vorschau von OpenSCAD kann man das Verhalten prüfen, wenn man beim Testaufruf Werte größer 1 übergibt:

#### count = 1

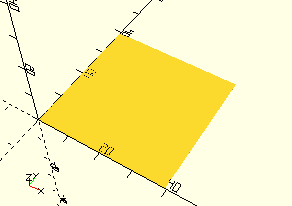
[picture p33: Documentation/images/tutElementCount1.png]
count 1


#### count = 2

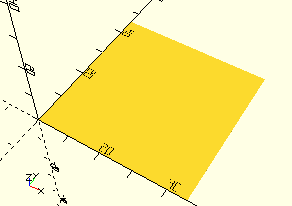
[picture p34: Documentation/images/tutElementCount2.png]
count 2


#### count = 3

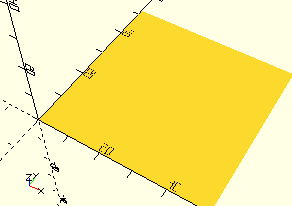
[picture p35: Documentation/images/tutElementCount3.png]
count 3


## Jetzt die Achshalter
Auch hier ist es eine gute idee, sich die Funktionen und Module anzuschauen, die in der Bibliothek vorhanden sind. Für Achsen wurde das Basismodul [__FrameAxis__](ModelBase/FrameAxis.md) entwickelt. In dessen erster Version wurden nur Achshalter für eine gerade Achse mit Haltern an beiden Enden unterstützt. Im Rahmen der Entwicklung dieses Tutorials kam die Anforderung auf, auch einen einzelnen Achshalter für nur ein Ende der Achse zu erzeugen. Durch einen weiteren optionalen Parameter war dies relativ einfach zu implementieren: Parameter *single* muss jetzt nur auf __true__ gesetzt werden, dann wird nur eine Seite erzeugt. Außerdem kann man in diesem Fall den Parameter *length* weglassen. Jetzt erzeugen wir einfach zwei einzelne Halter im 90°-Winkel an den richtigen Stellen.

Beginnen wir mit dem ersten Achshalter. Der Extra-Platz von 1,8 mm muss als Einrückung vom linken Rand angegeben werden. Dafür wollen wir statt __translate__ gleich das Bibliotheksmodul [__Place__](Base/Place.md) einsetzen. Die Bibliothek liefert für die Platzierung von Objekten auf Flächen eine Reihe von Funktionen und Modulen. In der Hilfe findet man sie unter [__Module zur Platzierung von Elementen__](Contents.md#module-zur-platzierung-von-elementen). Diese Funktionen und Module arbeiten normalerweise mit dem Sortierkasten 190 x 130 mm als Grundfläche. Über optionale Parameter funktioneren sie aber auf beliebigen Flächen.

Dafür benötigen wir noch die Datei __Base/Placement.scad__. Eine weitere __use__-Anweisung importiert sie in unser Element.

```
use <../Base/Placement.scad>
```

In der Dokumentation des [__Place__](Base/Place.md)-Moduls finden wir Konstanten mit sprechenden Namen für die Drehung ud Ausrichtung. Diese befinden sich alle in der Datei __Base/PlacementOptions.scad__. Hier müssen wir statt __use__ allerdings __include__ verwenden. Die dort definierten Variablen importiert __use__ nicht. __include__ importiert diese, als wenn sie Bestandteil unserer eigenen SCAD-Datei wären. Nur so funktioniert es:

```
include <../Base/PlacementOptions.scad>
```

### Platzieren mit Place
Jetzt platzieren wir nur noch den ersten Achshalter. Der optionale Parameter *x* gibt den X-Wert an. in unserem Fall ist dies der Extra-Abstand *extra*, den wir für weitere Winkelachsen reservieren wollen:

```
    Place(x=extra)
        FrameAxis(single=true);
```

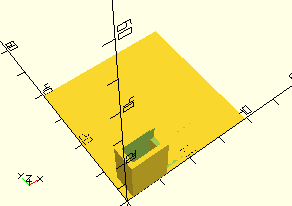
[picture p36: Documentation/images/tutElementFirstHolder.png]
Erster Halter


Man sieht, dass es keine einfache Grundform ist, aber für alle möglichen Arten von Achshalterungen zum Einsatz kommen kann. Die Konstruktion hat uns die Bibliothek abgenommen, der Aufruf war ziemlich trivial. Die Länge *partLength* wird auch hier verlangt, aber nicht verwendet, da ja nur ein einzelner Halter generiert wird.

### Drehen und Ausrichten mit Place
Jetzt brauchen wird dasselbe, nur gedreht und am rechten Rand des Rechtecks. Auch das kann [__Place__](Base/Place.md) erledigen, allerdings mit einer Reihe zusätzlicher Parameter:

```
    spaceWithoutExtra = getFrameOuterVolume([
        width,
        depth,
        getFrameAxisHeight()
    ]);

    Place(
        elementSpace=[spaceWithoutExtra.x, getFrameAxisSpace().y], 
        boxSpace = getFrameAngleAxisSpace(),
        alignX = AlignRight,
        rotation = Rotate90)
        FrameAxis(single=true);
```

[__Place__](Base/Place.md) kann viel, muss aber dafür auch mit genug Daten versorgt werden. Hier wollen wir gleich zwei Dinge:
- Drehe das Teil um 90°
- Richte es am rechten Rand aus

Dazu braucht __Place__ zwei Flächen:
- Die Fläche, auf der ausgerichtet werden soll (*boxSpace*)
- Die Fläche des Teils, das gedreht und ausgerichtet werden soll (*elementSpace*)

*boxSpace* ist in diesem Fall identisch mit dem Ergebnis, das unsere Funktion __-_getFrameAngleAxisSpace()__  liefert. Wir müssen auch, anders als bei der X-Achse, nicht den *extra*-Offset angeben, weil der oben in der Y-Achse ist und die Y-Position 0 deswegen passt.

*elementSpace* müssen wir neu ermitteln, den legen wir in der Variablen *spaceWithoutExtra* ab. Dort wird der Platz errechnet, der für einen Zweig unserer Winkelachse für die Halterung benötigt wird. Zur Ermittlung der Breite des Achshalters rufen wir wieder [__getFrameAxisSpace__](ModelBase/getFrameAxisSpace.md) auf, benötigen aber am Ende nur dessen y-Wert.

## Fast fertig

Keine Angst: Beim Erstellen des Tutorials klappte auch nicht alles wie gewünscht sofort. Ausprobieren und Fehler bereinigen ist, wie beim Programmieren, immer ein großer Bestandteil der Arbeit. Eine große Hilfe ist immer die Vorschau von OpenSCAD. Am besten bei jedem Schritt prüfen, ob's noch tut.

Schauen wir uns das Zwischenergebnis an:

```
// Fischertechnik Box Library
// Frame for Angle Axis
// 31035

use <../Base/Constants.scad>
use <../Base/Placement.scad>
use <../ModelBase/Simple.scad>
use <../ModelBase/Complex.scad>

include <../Base/PlacementOptions.scad>

width = 34.5;
depth = 34.5;
extra = 1.8;

function getFrameAngleAxisSpace(count=1) = getFrameOuterVolume([
    width + extra + (count-1)*(getFrameAxisSpace().y + extra), 
    depth + extra + (count-1)*(getFrameAxisSpace().y + extra), 
    getFrameAxisHeight()]);

module FrameAngleAxis(count=1) {
    Space(getFrameAngleAxisSpace(count));
    
    Place(x=extra)
        FrameAxis(single=true);
    
    spaceWithoutExtra = getFrameOuterVolume([
        width,
        depth,
        getFrameAxisHeight()
    ]);

    Place(
        elementSpace=[spaceWithoutExtra.x, getFrameAxisSpace().y], 
        boxSpace = getFrameAngleAxisSpace(),
        alignX = AlignRight,
        rotation = Rotate90)
        FrameAxis(single=true);
}

// Test
FrameAngleAxis();
```

Und das Ergebnis in der Vorschau:

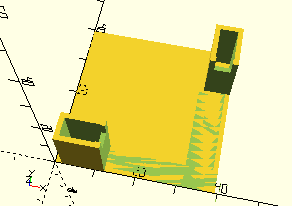
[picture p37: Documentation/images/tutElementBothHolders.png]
Zwei Achshalter


## Nochmal alles drehen
Der Parameter *count* lässt die Fläche nach oben rechts wachsen. Aktuell ist die Ausrichtung der Halter dafür aber falsch. Eine Drehung des gesamten Konstrukts um 90° heilt das. Dafür brauchen wir erneut einen weiteren Import:

```
use <../Base/Rotation.scad>
```

Weil wir über *count* mehrere der Halterungen benötigen, ergibt ein lokales __module__ zum Erzeugen und Drehen der beiden Halterungen Sinn. Das ermöglicht uns später den Aufruf in einer __for__-Schleife. Ein kleiner Umbau erldigt diese Aufgabe:

```
module FrameAngleAxis(count=1) {
    Space(getFrameAngleAxisSpace(count));
    
    module Holders() {
        RotateFix(getFrameAngleAxisSpace(), Rotate90) {
            Place(x=extra)
                FrameAxis(single=true);
            
            spaceWithoutExtra = getFrameOuterVolume([
                width,
                depth,
                getFrameAxisHeight()
            ]);

            Place(
                elementSpace=[spaceWithoutExtra.x, getFrameAxisSpace().y], 
                boxSpace = getFrameAngleAxisSpace(),
                alignX = AlignRight,
                rotation = Rotate90)
                FrameAxis(single=true);
        }
    }

    Holders();
}
```

Der bisherige Code wurde einfach in das neue lokale __module__ __Holders__ verschoben. Anschließend wird es nur noch aufgerufen. Das mach alles übersichtlicher und änderungsfreundlicher. Module in Modulen sind nur innerhalb des Moduls sichtbar und werden nicht exportiert. Wenn unser Element per __use__ importiert wird, ist __Holders__ dort nicht sichtbar.

Wir drehen das Konstrukt mit dem Modul [__RotateFix__](Base/RotateFix.md). Damit es das richtig machen kann, muss es die Fläche des zu drehenden Objekts kennen (hier __getFrameAngleAxisSpace()__) und um wieviel es gedreht werden soll. *count* spielt hier keine Rolle, weil __Holders__ immer nur für eine einzelne Winkelachse zuständig ist. Das Ergebnis in der Vorschau:

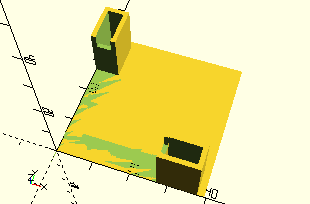
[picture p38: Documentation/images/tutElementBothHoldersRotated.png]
Zwei Achshalter gedreht


Jetzt kann nach oben und rechts angebaut werden.

## Wir wollen Halter für *count* Achsen
Wir haben jetzt (fast) alles vorbereitet, um auch mehrere Achshalter an den richtigen Stellen zu erzeugen. Zur Erinnerung: Die verwinkelten Halter sollen ineinander nach rechts oben in 45° aneinandergereiht werden.

Der Abstand der halter voneinander soll der Wert von *extra* sein. Wenn wir die Halter über __Holders__ erzeugen, müssen wir bei __translate__ noch die Tiefe des Achshalters selbst addieren ([__getFrameAxisSpace().y__](ModelBase/getFrameAxisSpace.md)). Genau diesen Wert benötigt auch die eigene Funktion __getFrameAngleAxisSpace__ intern zwei Mal. Deswegen ändern wir jetzt noch eine Kleinigkeit, weil ein errechneter Wert ein drittes Mal benötigt wird:

```
difference = getFrameAxisSpace().y + extra;

function getFrameAngleAxisSpace(count=1) = getFrameOuterVolume([
    width + extra + (count-1)*difference, 
    depth + extra + (count-1)*difference, 
    getFrameAxisHeight()]);
```

Jetzt kommt unten im Modul __FrameAngleAxis__ die neue Variable *difference* das dritte mal in der schon angekündigten Schleife zum Einsatz:

```
    for (i = [0:count-1])
        translate([difference*i, difference*i])
            Holders();
```

Zum Testen ändern wir jetzt den Aufruf in der letzten Zeile und übergeben für den Parameter *count* eine 2:

```
FrameAngleAxis(2);
```

Sieht schon ganz gut aus (und funktioniert auch mit beliebig höheren Werten):

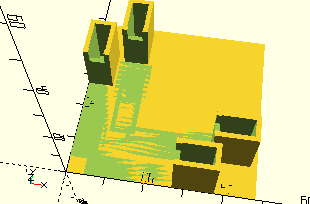
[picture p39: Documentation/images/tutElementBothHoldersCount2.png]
Für zwei Achsen


## Der schräge Steg fehlt noch
Ohne eine weitere Stütze kippt die Winkelachse aus den Halterungen. Am Knick brauchen wir jetzt noch einen Steg mit Aussparung. Im 50/2 ist das ein 45° Steg. Den müssen wir jetzt konstruieren.

Das Vorbild im 50/2 ist ein durchgängiger Steg für zwei Winkelachsen. Der beginnt nicht ganz in der linken unteren Ecke und endet kurz nach dem Knick der letzten Achse weiter rechts oben. Würde man lauter einzelne Halter pro Achse konstruieren, müsste man sie zusätzlich bei mehreren Achsen irgendwie über die entstehenden Abstände hinweg verbinden. Es erscheint also sinnvoll, diesen Steg auf Basis des Werts von *count* gleich als ein Objekt zu konstruieren. Das erhöht gerade bei frei stehenden Wänden die Stabilität, was bei gedruckten Kästen ein wichtiger Aspekt ist.

### Konstruktion des Stegs
Das englische Wort für Steg (im Sinne eines Trennstegs) ist laut Internet *Web*. Dieser Begriff wird in der Bibliothek durchgängig für alle Stege in Sortierkästen und Elementen verwendet. Zuerst lösen wir das Problem, einen Steg der richtigen Länge mit der richtigen Anzahl Aussparungen an den richtigen Stellen zu erzeugen. Dafür bietet sich wieder ein lokales Modul an. Wir nennen es überraschenderweise __Web__.

Direkt unter dem lokalen __module__ __Holders__ legen wir das neue __module__ __Web__ an:

```
    module Web() {
        baseLength = getFrameAxisSpace().y + (count - 1) * difference;
        webLength = sqrt(baseLength^2 + baseLength^2);
        
        webVolume = [webLength - 2*getDividerThickness(), getDividerThickness(), getFrameAxisHeight()];
        
        rotate([0,0,45]) {
            translate([getDividerThickness(), 0])
                Wall(webVolume);
        }
    }
```

*baseLength* ist die Basis zur Berechnung der Länge des Stegs. Die Breite einer Halterung plus die Breite jeder weiteren Halterung und deren zusätzlichen Abstands. Halterungsbreite plus Abstand haben wir zuvor schon in der Variablen *distance* angelegt. Stünde der Steg senkrecht, wäre diese Länge jetzt schon richtig. Aber wir müssen sie um 45° schräg stellen, und dadurch ändert sich die Länge. Wir müssen Herrn Pythagoras um Hilfe bitten:

```
        baseLength = getFrameAxisSpace().y + (count - 1) * difference;
        webLength = sqrt(baseLength^2 + baseLength^2);
        webOffset = sqrt(getDividerThickness()^2 + getDividerThickness()^2);
```

Für den Steg verwenden wir wieder das Bibliotheksmodul [__Wall__](ModelBase/Wall.md). Das Volumen des Stegs *webVolume* sieht so aus:

```
        webVolume = [webLength - 2*getDividerThickness(), getDividerThickness(), getFrameAxisHeight()];
```

Länge, Breite und Höhe: Aber warum die Verkürzung um -2*[__getDividerThickness()](Base/getDividerThickness.md)? Das hat kosmetische Gründe. Im Kasten 50/2 haben die beiden Enden des Stegs eine etwas verkürzte Länge, wohl damit die Ecken der Wand nicht aus der Fläche ragen. Durch diese Verkürzung erreichen wir das. Wir müssen nur noch das Ergebnis um *webOffset* nach rechts verschieben. Das passiert hier vor dem Drehen (das Zeug innerhalb der Klammer wird vor __rotate__ ausgeführt):

```
        rotate([0,0,45]) {
            translate([webOffset, 0])
                Wall(webVolume);
        }
```

Um unser Kunstwerk in der Vorschau zu betrachten, fügen wir noch den Aufruf von __Web__ ein:

```
    for (i = [0:count-1])
        translate([difference*i, difference*i])
            Holders();
        
    Web();
```

Der Aufruf mit *count* = 4 zeigt uns, dass wir nicht ganz falsch liegen:

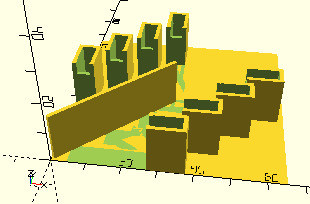
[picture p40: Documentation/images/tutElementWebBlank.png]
Steg ohne Aussparungen


Die Länge passt, der Winkel passt, die Höhe und die Position passen.

### Noch die Aussparungen
Der untere Teil des __module__ __Web__ dreht sich um die Aussparungen. *webDifference* errechnet einfach wieder über Pythagoras die 45°-Länge des Abstands *distance*. Den brauchen wir als __step__ in der Schleife.

```
                webDifference = sqrt(difference^2 + difference^2);
```

Für die jeweils mittige Platzierung der Aussparung brauchen wir die Länge des Stegs pro Achse. Die erledigt ein letztes Mal Pythagoras und speichert sie in *singleLength*. Die Breite der Aussparung *webCutoffWidth* setzen wir mit gemessenen 3,5 mm an, die Höhe *webCutoffHeight* mit 3 mm. Die Achse ist im Knick der Achse deutlich dünner als 4 mm.

```
                singleLength = sqrt(getFrameAxisSpace().y^2 + getFrameAxisSpace().y^2);
                webCutoffHeight = 3.0;
                webCutoffWidth = 3.5;
```

Damit können wir jetzt einen Körper definieren, der über __difference__ aus dem Steg als Aussparung herausgeschnitten werden. Das Volumen eines solchen Körpers ist:

```
                cutoffVolume = [webCutoffWidth, getDividerThickness()*2, webCutoffHeight + getExcess()];
```

Wir haben für y nicht exakt die Wandstärke genommen, sondern die doppelte. Die verschieben wir beim Ausschneiden um eine halbe Wandstärke nach vorne. Bei der Höhe schlagen wir den kleinen Betrag von [__getExcess__](Base/getExcess.md) drauf, damit oben kein superdünner Rest beim Wegschneiden übrig bleibt. Wenn man die __cube__-Objekte mit # transparent ausgibt, sieht das Ganze bei *count* = 4 so aus:

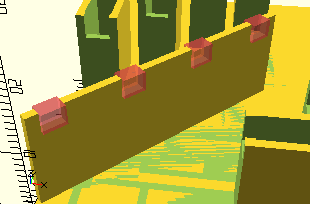
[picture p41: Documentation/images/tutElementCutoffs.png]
Aussparungen


## Unterstützung für CAD-Programme: STL-Export
Unser Element hat einen Parameter namens *count*. Falls man das Element als STL-Datei in einem CAD-Programm nutzen will, sollte man es nach STL exportieren. Aber ohne ein kleines SCAD-Programm zu schreiben, bekommt man nicht die verschiedenen Varianten, die durch die Werte von *count* entstehen.

Die Lösung ist, dass unsere Element-SCAD-Datei das gleich durch den OpenSCAD-*Customizer* unterstützt. Der ermöglicht es ohne Änderung der SCAD-Datei parameter in einem Fenster einzustellen und die Varianetn live zu erzeugen.

Um genau die Parameter dort anzuzeigen, die wir auch im __module__ definiert haben, schreiben wir sie einfach als Variablen als erstes in die SCAD-Datei:

```
/* [Element Parameters] */
count = 1;
```

Der Kommentar mit dem Text in den eckigen Klammern erzeugt im Customizer eine Registerseite, in welcher unsere Parameter erscheinen. Das sieht dann so aus:

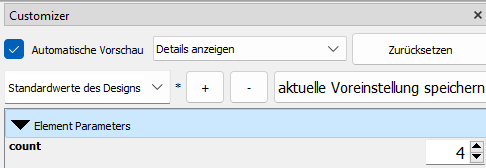
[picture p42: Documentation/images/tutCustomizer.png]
Customizer


Damit die anderen Variablen nicht erscheinen, müssen wir noch einen Kommentar drüber schreiben:

```
/* [Hidden] */
width = 34.5;
depth = 34.5;
extra = 1.8;
difference = getFrameAxisSpace().y + extra;
```

Das war's. Jetzt kann man ohne Codeänderungen alle Varianten des Elements erzeugen, exportieren und später in einem CAD-Programm verwenden.

## Fertig!
Das ganze Element sieht jetzt so aus:

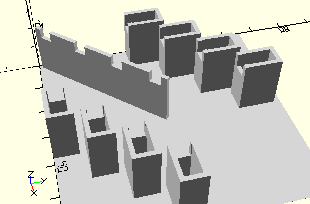
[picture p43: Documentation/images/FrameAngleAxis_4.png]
Vier Winkelachsen


Der Code ist nicht ganz trivial, aber auch kein Lebenswerk:

```
// Fischertechnik Box Library
// Frame for Angle Axis
// 31035

use <../Base/Constants.scad>
use <../Base/Placement.scad>
use <../Base/Rotation.scad>
use <../ModelBase/Simple.scad>
use <../ModelBase/Complex.scad>

include <../Base/PlacementOptions.scad>

/* [Element Parameters] */
count = 1;

/* [Hidden] */
width = 34.5;
depth = 34.5;
extra = 1.8;
difference = getFrameAxisSpace().y + extra;

function getFrameAngleAxisSpace(count=1) = getFrameOuterVolume([
    width + extra + (count-1)*difference, 
    depth + extra + (count-1)*difference, 
    getFrameAxisHeight()]);

module FrameAngleAxis(count=1) {
    Space(getFrameAngleAxisSpace(count));
    
    module Holders() {
        RotateFix(getFrameAngleAxisSpace(), Rotate90) {
            Place(x=extra)
                FrameAxis(single=true);
            
            spaceWithoutExtra = getFrameOuterVolume([
                width,
                depth,
                getFrameAxisHeight()
            ]);

            Place(
                elementSpace=[spaceWithoutExtra.x, getFrameAxisSpace().y], 
                boxSpace = getFrameAngleAxisSpace(),
                alignX = AlignRight,
                rotation = Rotate90)
                FrameAxis(single=true);
        }
    }
    
    module Web() {
        baseLength = getFrameAxisSpace().y + (count - 1) * difference;
        webLength = sqrt(baseLength^2 + baseLength^2);
        
        webVolume = [webLength - 2*getDividerThickness(), getDividerThickness(), getFrameAxisHeight()];
        
        rotate([0,0,45]) {
            difference() {
                translate([getDividerThickness(), 0])
                    Wall(webVolume);
        
                webDifference = sqrt(difference^2 + difference^2);
                singleLength = sqrt(getFrameAxisSpace().y^2 + getFrameAxisSpace().y^2);
                webCutoffHeight = 3.0;
                webCutoffWidth = 3.5;
                cutoffVolume = [webCutoffWidth, getDividerThickness()*2, webCutoffHeight + getExcess()];
                for (xWebCutoffOffset = [0:webDifference:webLength])
                    translate([
                        (singleLength - cutoffVolume.x)/2 + xWebCutoffOffset + (webOffset - getDividerThickness()) , 
                        -getDividerThickness()/2, 
                        webVolume.z - webCutoffHeight])
                        cube(cutoffVolume);
            }
        }
    }

    for (i = [0:count-1])
        translate([difference*i, difference*i])
            Holders();
        
    Web();
}

// Test
color("lightgray")
FrameAngleAxis(count);
```

Als Reminiszenz an die guten alten grauen Tage von Fischertechnik bekommen die Test-Zeilen immer noch ein __color("lightgray")__ vorangestellt.

## Nacharbeiten in der echten Welt
Wenn man seine ersten echten Elemente erstellt, kommen noch die Themen Tests und Dokumentation dazu. Die folgenden gehen darauf ein, was zu tun ist.

### Tests
Im Ordner __Test/Elements__ sollte noch ein Testskript für jedes neue Element hinterlegt werden. Dessen Namensschema ist einfach __Test*Elementname*.scad__. In unserem Fall also __TestFrameAngleAxis.scad__.

Für die Generierung dieser Testdatei gibt es im Ordner __VS Code Snippets__ für *Visual Studio Code* vordefinierte Snippets (Datei __scad.json__), die in vielen Fällen automatisch die beiden relevanten Tests generieren. Wenn man eine Leere Datei mit dem richtigen Dateinamen nach dem Schema anlegt, muss man nur noch "tst" in der ersten Zeile eingeben. Dann erscheint schon das Snippet und nach der Auswahl wird dieser Code generiert:

```
// Fischertechnik Box Foundation
// Elements
// Test FrameAngleAxis

use <../../base/Placement.scad>
use <../../Elements/FrameAngleAxis.scad>

include <../../Base/PlacementOptions.scad>

FrameAngleAxis();

Place(getFrameAngleAxisSpace().x+15, 0, elementSpace=getFrameAngleAxisSpace(), rotation=Rotate90)
    FrameAngleAxis();
```

Die Namen des Moduls, der __use__-Dateien und der Funktion erzeugt das Snippet auf Basis des Dateinamens der Test-SCAD-Datei. Wenn man sich nicht vertut, hat man danach schon die erste Version einer lauffähigen Testdatei.

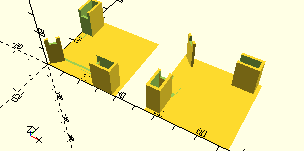
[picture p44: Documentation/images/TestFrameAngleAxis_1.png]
Generierter Test


Ausprobieren sollte man immer, ob sich das Element korrekt drehen lässt, was der generierte Code bereits einmal mit 90° erledigt. Hintergrund: Die Funktion __get*Elementname*Space()__ wird dadurch getestet, weil sie die Grundlage für korrekte Drehungen und Ausrichtungen ist.

In unserem Fall wären noch manuelle Erweiterungen mit *count*-Werten größer 1 sinnvoll:

```
Place(2*(getFrameAngleAxisSpace().x+15), 0, elementSpace=getFrameAngleAxisSpace(3), rotation=Rotate270)
    FrameAngleAxis(3);
```

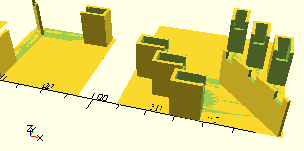
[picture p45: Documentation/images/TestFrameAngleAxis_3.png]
Test für 3


Läuft...

## Drucktest
Sinnvoll ist jetzt noch, dass man ein Exemplar auf dem 3D-Drucker testet. Wenn wir uns vermessen haben, passt das Bauteil womöglich nicht ins Element. Das wäre nicht nur peinlich, sondern belastet auch die Umwelt und den Geldbeutel durch Fehldrucke ganzer Kästen.

Zu diesem Zweck gibt es auch ein Visual Studio Snippet in der __scad.json__-Datei. Die SCAD-Datei muss im Ordner __Test/Print__ angelegt werden: __TestPrint*Elementname*.scad__, in unserem Fall __TestPrintFrameAngleAxis.scad__. Mit dem Snippet geht es hier vollautomatisch, einfach "3dpt" eintippen und Return drücken:

```
// 3D Print Test
// FrameAngleAxis

use <../TestPrint.scad>
use <../../Elements/FrameAngleAxis.scad>

TestPrint(getFrameAngleAxisSpace())
    FrameAngleAxis();
```

Dieses Skript erzeugt ein mit einerm etwas dickeren, druckbaren Boden unterlegtes Element. Versionen mit Varianten von Parametern muss man manuell angeben. Über den Export eine STL-Datei ist der Test mit dem Drucker sparsamer, als wenn man erst in einem Sortierkasten Fehler bemerkt.

## Dokumentation
Die meisten Elemente haben ein sehr einfaches Schema für die Hilfeseite. Deswegen gibt es  Visual Studio Code Snippets, die einen Großteil der Arbeit generieren. Das Vorgehen wird [separat beschrieben](HelpHowTo.md). Das ist zu tun:
- Hilfeseite für den Einsatz des Elements
- Element in die [__PartFinder__](PartFinder.md)-Dateien aufnehmen

## Tipp für Nutzer des Fischertechnik Designers
Nutzer des [Fischertechnik Designers](http://www.3dprofi.de/de/) können die im Programmverzeichnis gespeicherten STL-Dateien der Fischertechnik-Bauteile auch für die Konstruktion der Elemente einsetzen. Dessen STL-Format konnte ich allerdings nicht direkt in OpenSCAD importieren. Stattdessen habe ich die STL-Dateien erst über den Windows-3D-Viewer nach .3mf exportiert. Das wiederum funktionierte dann in OpenSCAD.

Wenn man ein bisschen herumprobiert, kann man die Teile so platzieren, dass sich die Maße des Elements damit ganz gut überprüfen lassen. In der Abbildung ist das importierte Teil in rot-transparent dargestellt:

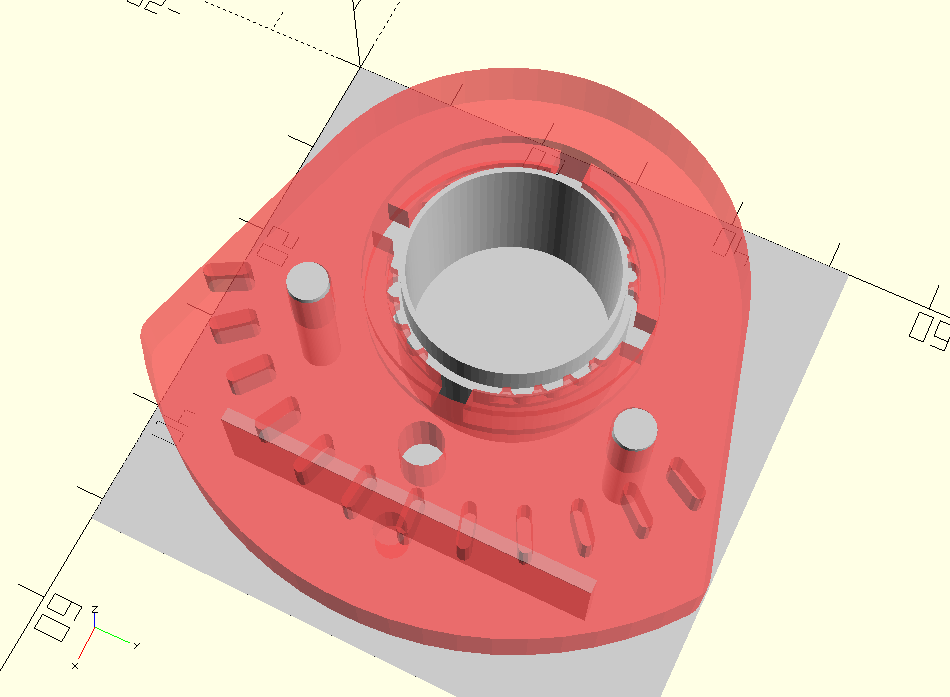
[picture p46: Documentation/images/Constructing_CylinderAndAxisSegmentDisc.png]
Beispiel Konstruktion


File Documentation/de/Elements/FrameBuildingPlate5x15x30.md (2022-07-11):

# FrameBuildingPlate5x15x30
Bauplatte 5x15x30 mit einer oder drei Nuten.
- 32330
- 38428

Mit *count* kann die Anzahl der Bauplatten angegeben werden.

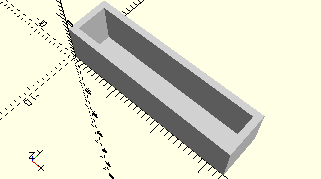
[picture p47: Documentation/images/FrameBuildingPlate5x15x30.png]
FrameBuildingPlate5x15x30


## Use
```
use <../Elements/FrameBuildingPlate5x15x30.scad>
```

## Syntax
```
FrameBuildingPlate5x15x30(
    count=1);

space = getFrameBuildingPlate5x15x30Space(
    count=1);
```

| Parameter | Typ | Beschreibung |
| --- | --- | --- |
| count | Integer | Anzahl der Bauplatten, die im Rahmen nebeneinander Platz haben sollen. |

## Rückgabewert getFrameBuildingPlate5x15x30Space
Fläche als \[x,y]-Liste

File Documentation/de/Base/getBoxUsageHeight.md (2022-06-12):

# getBoxUsageHeight

Funktion: Liefert die Höhe des nutzbaren Innenraums der fischertechnik Sortierbox. Dies ist die Höhe vom Boden bis zum oberen Absatz, auf dem ein gestapelter Sortierkasten steht.

## Use
```
use <../Base/Boxes.scad>
```

## Syntax
```
getBoxUsageHeight(
    height = 40);
```

| Parameter | Typ | Beschreibung |
| --- | --- | --- |
| height | Decimal | Höhe der Box vom Boden bis zum oberen Rand. Die Fischertechnikkästen sind alle 40 mm hoch. Mit der Bibliothek lassen sich aber auch Kästen mit anderen Höhen erzeugen ([__BoxBase__](BoxBase.md)). In diesem fall muss die abweichende Höhe hier angegeben werden, um die innerere nutzbare Höhe zu ermitteln.

## Rückgabewert
Höhe des benutzbaren Bereichs im Fischertechnik-Sortierkasten in mm. Die Wände sind außen etwa 5 mm höher, haben aber einen Absatz, in den ein gestapelter Kasten oder ein Deckel gelegt wird.

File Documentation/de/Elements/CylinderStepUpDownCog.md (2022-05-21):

# CylinderStepUpDownCog

Zwischenrad Z10 (aus mot2).

- 31052

CylinderStepUpDownCog

## Use
```
use <../Elements/CylinderStepUpDownCog.scad>
```

## Syntax
```
CylinderStepUpDownCog();

space = getCylinderStepUpDownCogSpace();
```

## Rückgabewert getCylinderStepUpDownCogSpace
Fläche als \[x,y]-Liste.

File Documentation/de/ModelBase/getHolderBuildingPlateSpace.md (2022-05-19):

# getHolderbBuildingPlateSpace

Funktion: Liefert die Fläche einer Halterung für Bauplatten.

Dies ist die Fläche einer Halterung, die von [HolderBuildingPlate](HolderBuildingPlate.md) erzeugt wird.

## Use
```
use <../ModelBase/Complex.scad>
```

## Syntax
```
getHolderbBuildingPlateSpace(
    width, 
    count);
```

| Parameter | Typ | Beschreibung |
| --- | --- | --- |
| width | Decimal | Breite der Bauplatte. Die Halter unterstützen die Breiten 30 bis 90 mm. |
| count | Integer | Anzahl der hintereinander aufgestellten Bauplatten. |

## Rückgabewert
Fläche der Halterungen auf Basis der Anzahl (*count*) und der Größe (*width*). Die Toleranz ist eingerechnet.

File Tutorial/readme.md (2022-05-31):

# Ordner für das Tutorial

In diesem Ordner sollte man die SCADE-Dateien des [Tutorials](../Documentation/de/TutorialElements.md) erzeugen und bearbeiten.

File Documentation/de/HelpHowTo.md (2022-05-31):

# Wie man ein Element dokumentiert
in Arbeit

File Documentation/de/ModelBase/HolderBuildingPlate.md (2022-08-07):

# HolderBuildingPlate

Erzeugt Halter für Bauplatten.

Die Bauplatten stehen senkrecht in den Haltern. Über Parameter können die Größen der Bauplatten angegeben werden.

## Use
```
use <../ModelBase/Complex.scad>
```

## Syntax
```
HolderBuildingPlate(
    width, 
    count = 1, 
    dock = false)
```

| Parameter | Typ | Beschreibung |
| --- | --- | --- |
| width | Decimal | Breite der Bauplatte. Die Halter unterstützen die Breiten 30 bis 90 mm. Bei 30 mm werden die beiden Halter außerhalb neben den äußeren Zapfen platziert, ansonsten innerhalb neben den äußeren Zapfen. |
| count | Integer | Anzahl der hintereinander aufgestellten Bauplatten. |
| dock | Boolean | __true__, wenn die Halterung an eine Wand oder einen Trenner des Sortierkastens angedockt und verschmolzen werden soll. In diesem Fall ist der Steg 15 mm hoch statt 10 und ragt in die Wand hinein. Das Element muss dann zur Wand so gedreht werden, dass die Verschmelzung an der richtigen Seite erfolgt. |

## Beispiel
```
use <../../ModelBase/Complex.scad>

HolderBuildingPlate(30);

translate([0, 20, 0])
    HolderBuildingPlate(60);

translate([0, 40, 0])
    HolderBuildingPlate(90);

translate([120, 0, 0])
    HolderBuildingPlate(90, 4, dock=true);

translate([120, 40, 0])
    HolderBuildingPlate(45, 4);
```

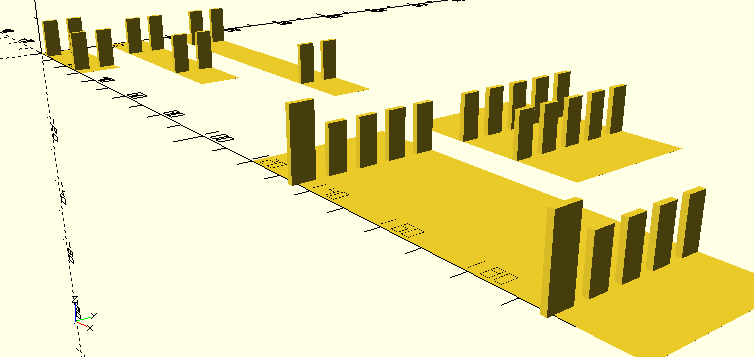
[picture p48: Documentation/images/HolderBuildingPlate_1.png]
HolderBuildingPlate


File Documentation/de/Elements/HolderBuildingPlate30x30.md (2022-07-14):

# HolderBuildingPlate30x30
Bauplatte 30x30 oder 15x30 mit Zapfen oder Clips.
- 31501
- 31510
- 36918
- 38241
- 38259
- 38266
- 38267
- 38268
- 146534
- 156511

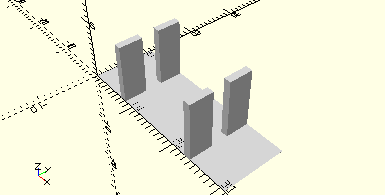
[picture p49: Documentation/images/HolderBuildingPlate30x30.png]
HolderBuildingPlate30x30


## Use
```
use <../Elements/HolderBuildingPlate30x30.scad>
```

## Syntax
```
HolderBuildingPlate30x30(
    count=1,
    dock=false);

space = getHolderBuildingPlate30x30Space(
    count=1);
```

| Parameter | Typ | Beschreibung |
| --- | --- | --- |
| count | Integer | Anzahl der Bauplatten hintereinander. |
| dock | Boolean | __true__, wenn die Halterungen an die Wand des Sortierkastens angedockt werden sollen. Die der Wand zugewandten Stege sind dann höher und ragen zum Verschmelzen in die Wand hinein. Dazu muss das Element mit der Seite direkt an der Wand platziert werden (z.B. per [__Place__](../Base/Place.md) mit __Rotate90__ und __AlignLeft__). |

## Rückgabewert getHolderBuildingPlate30x30Space
Fläche als \[x,y]-Liste

## Beispiel
```
use <../../Elements/HolderBuildingPlate30x30.scad>

HolderBuildingPlate30x30(4, true);
```

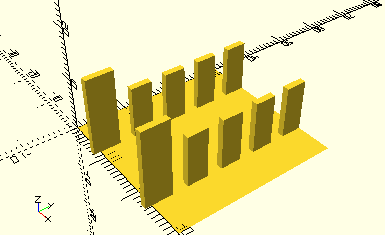
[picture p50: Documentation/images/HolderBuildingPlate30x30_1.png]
HolderBuildingPlate30x30


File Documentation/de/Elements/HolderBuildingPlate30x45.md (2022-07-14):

# HolderBuildingPlate30x45
Bauplatte 30x45 oder 15x45 mit Zapfen oder Clips.
- 31502
- 31511
- 36508
- 38237
- 38238
- 38242
- 38243
- 38248
- 38261
- 38269
- 163041
- 163042

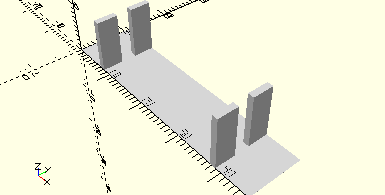
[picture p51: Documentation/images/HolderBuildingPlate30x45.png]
HolderBuildingPlate30x45


## Use
```
use <../Elements/HolderBuildingPlate30x45.scad>
```

## Syntax
```
HolderBuildingPlate30x45(
    count=1,
    dock=false);

space = getHolderBuildingPlate30x45Space(
    count=1);
```

| Parameter | Typ | Beschreibung |
| --- | --- | --- |
| count | Integer | Anzahl der Bauplatten hintereinander. |
| dock | Boolean | __true__, wenn die Halterungen an die Wand des Sortierkastens angedockt werden sollen. Die der Wand zugewandten Stege sind dann höher und ragen zum Verschmelzen in die Wand hinein. Dazu muss das Element mit der Seite direkt an der Wand platziert werden (z.B. per [__Place__](../Base/Place.md) mit __Rotate90__ und __AlignLeft__). |

## Rückgabewert getHolderBuildingPlate30x45Space
Fläche als \[x,y]-Liste

## Beispiel
```
use <../../Elements/HolderBuildingPlate30x45.scad>

HolderBuildingPlate30x45(4, true);
```

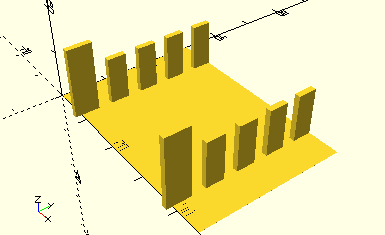
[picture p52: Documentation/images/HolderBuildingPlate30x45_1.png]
HolderBuildingPlate30x45


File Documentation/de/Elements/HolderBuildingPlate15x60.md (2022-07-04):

# HolderBuildingPlate15x60
Bauplatte 15x60.
- 38324
- 38464
- 38474
- 133008

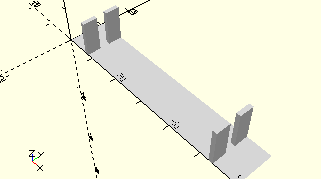
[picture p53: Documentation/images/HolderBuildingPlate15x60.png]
HolderBuildingPlate15x60


## Use
```
use <../Elements/HolderBuildingPlate15x60.scad>
```

## Syntax
```
HolderBuildingPlate15x60(
    count=1,
    dock=false);

space = getHolderBuildingPlate15x60Space(
    count=1);
```

| Parameter | Typ | Beschreibung |
| --- | --- | --- |
| count | Integer | Anzahl der Bauplatten hintereinander. |
| dock | Boolean | __true__, wenn die Halterungen an die Wand des Sortierkastens angedockt werden sollen. Die der Wand zugewandten Stege sind dann höher und ragen zum Verschmelzen in die Wand hinein. Dazu muss das Element mit der Seite direkt an der Wand platziert werden (z.B. per [__Place__](../Base/Place.md) mit __Rotate90__ und __AlignLeft__). |

## Rückgabewert getHolderBuildingPlate15x60Space
Fläche als \[x,y]-Liste

## Beispiel
```
use <../../Elements/HolderBuildingPlate15x60.scad>

HolderBuildingPlate15x60(5, true);
```

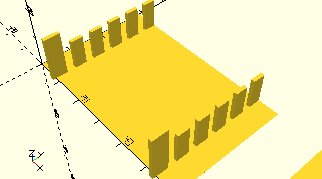
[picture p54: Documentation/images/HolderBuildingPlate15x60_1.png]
HolderBuildingPlate15x60


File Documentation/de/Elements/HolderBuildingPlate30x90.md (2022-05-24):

# HolderBuildingPlate30x90
Bauplatte 30x90.
- 31503
- 38251
- 38485

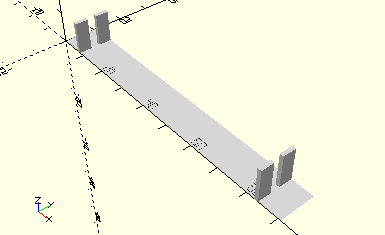
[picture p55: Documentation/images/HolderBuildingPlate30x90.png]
HolderBuildingPlate30x90


## Use
```
use <../Elements/HolderBuildingPlate30x90.scad>
```

## Syntax
```
HolderBuildingPlate30x90(
    count=1,
    dock=false);

space = getHolderBuildingPlate30x90Space(
    count=1);
```

| Parameter | Typ | Beschreibung |
| --- | --- | --- |
| count | Integer | Anzahl der Bauplatten hintereinander. |
| dock | Boolean | __true__, wenn die Halterungen an die Wand des Sortierkastens angedockt werden sollen. Die der Wand zugewandten Stege sind dann höher und ragen zum Verschmelzen in die Wand hinein. Dazu muss das Element mit der Seite direkt an der Wand platziert werden (z.B. per [__Place__](../Base/Place.md) mit __Rotate90__ und __AlignLeft__). |

## Rückgabewert getHolderBuildingPlate30x90Space
Fläche als \[x,y]-Liste

## Beispiel

```
use <../../Elements/HolderBuildingPlate30x90.scad>

HolderBuildingPlate30x90(4, true);
```

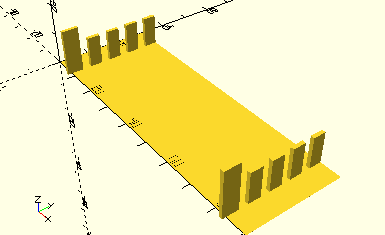
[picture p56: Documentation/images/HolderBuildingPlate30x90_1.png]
HolderBuildingPlate30x30


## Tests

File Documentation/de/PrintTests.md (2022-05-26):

# Elemente mit 3D-Drucker testen

Bevor neue Elemente in Sortierkästen integriert eingebaut werden, sollten sie erst in einem realen Druck getestet werden. Ein Fehlversuch für eine ganze Box ist leider ziemlich teuer. Wenn dann der Kasten weggeworfen werden muss, weil eines der Teile nicht in das verwendete Element passt, ist das ärgerlich und für die Umwelt schlimmer, als wenn nur ein einzelnes Test-Element verdruckt wird.

## Ordner Test/Print

Die mit [__Space__](ModelBase/Space.md) unterlegten Teile sind einzeln nicht druckfähig, weil die Schicht, die in den Boden versenkt wird, zu dünn ist. Um eine druckbare Basis zu bekommen, wurde im Ordner Test/Print das Modul __TestPrint.scad__ zur Verfügung gestellt.

Für jedes Element aus dem Ordner __Elements__ gibt es ein __TestPrint__-Skript mit dem Namensschema __TestPrint*ElementName*.scad__, das für parameterlose Elemente vollständig mit dem VS-Code-Snippet *3dpt* generiert werden kann. Hier der Test für [__AxisCoupling__](Elements/AxisCoupling.md):

```
// 3D Print Test
// AxisCoupling

use <../TestPrint.scad>
use <../../Elements/AxisCoupling.scad>

TestPrint(getAxisCouplingSpace())
    AxisCoupling();
```

## TestPrint
__TestPrint__ erstellt eine Basisfläche in druckbarer, aber sehr dünner Stärke, deren Oberfläche auf der 0-Linie der Z-Position liegt, wie auch die der Stortierkästen. Die Element-__children__ des Moduls werden dadurch mit der Fläche verschmolzen. Es wird quasi der Sortierkasten simuliert. Fläche und das Element werden dann noch um die Bodenstärke angehoben, so dass das resultierende 3D-Objekt an der Position 0,0,0 als STL-Datei exportiert werden kann.

### Syntax
```
TestPrint(
    space)
    {children}
```

| Parameter | Typ | Beschreibung |
| --- | --- | --- |
| space | \[x,y] | Breite und Tiefe der druckbaren Fläche. In den meisten Fällen dürfte das der Fläche entsprechen, die von __get*ElementName*Space()__ für das zu druckende Element geliefert wird. |

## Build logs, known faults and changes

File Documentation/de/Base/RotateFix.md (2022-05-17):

# RotateFix

Rotiert das Children-Element um 0, 90, 180 oder 270 Grad im Uhrzeigersinn. Dabei verbleibt der Ursprung des Elements immer links unten, so dass sich dessen Position auf der Fläche nicht ändert.

## Use
```
use <../Base/Rotation.scad>
include <PlacementOptions.scad>
```

## Syntax
```RotateFix(
  space,
  rotation=Rotate0))
  {children}
```

| Parameter | Typ | Beschreibung |
| --- | --- |  --- |
| space | \[x,y] | Fläche des Elements, das rotiert werden soll. Dies kann z.B. durch __get*ElementName*Space()__ angegeben werden. |
| rotation | Integer (Enum) | Gibt an, wie das Element rotiert werden soll. Mögliche Werte sind die in *PlacementOptions.scad* definierten Konstanten __Rotate0__, __Rotate90__, __Rotate180__ und __Rotate270__. |

## Beispiel

```
use <../../Base/Rotation.scad>

include <../../Base/PlacementOptions.scad>

use <../TestHelper.scad>

Deploy(30) {
    RotateFix(getCubeSpace(), Rotate0)
        Cube();
    RotateFix(getCubeSpace(), Rotate90)
        Cube();
    RotateFix(getCubeSpace(), Rotate180)
        Cube();
    RotateFix(getCubeSpace(), Rotate270)
        Cube();
}
```

Die vier __Cube__-Elemente werden im Abstand von jeweils 30 mm horizontal verteilt. Jedes wird dabei um 90° mehr gedreht, als der linke Nachbar. Der Ursprung des Elements bleibt aber trotz Drehung immer links unten.

RotateFix_1

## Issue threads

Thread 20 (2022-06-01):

Einsätze für Box 500

proggi64, 2022-06-01:
Idee: Statt ganze Box Einsätze für die Boxen designen, die in den Seitenschienen oder unter den Einteilern verankert werden.

proggi64, 2022-06-06:
Box190Inlay and Box190InlayWeb

Closed 2022-06-06.

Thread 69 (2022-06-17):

Erweiterung alle Boxen auch als Inlay über Customizer

proggi64, 2022-06-17:
Die mot-Boxen haben zu viele Elmenete, die integraler Bestandteil der Seitenwände sind. Bei den ec-Kästen war es mit wenigen Modifikationen aber möglich.

proggi64, 2022-06-18:
Customizer *inlay* auf true

Closed 2022-06-18.

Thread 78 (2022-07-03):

FrameLeftCutoff: Wrong cube position, cuts nothing

proggi64, 2022-07-03:
Width and depth are swapped

Closed 2022-07-03.

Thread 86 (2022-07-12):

Rename: Pin to Stud

proggi64, 2022-07-12:
Rename all Modules, Files, Functions und Variables that use the wird "pin" into "stud"

Correction of wrong wording necessary

Closed 2022-07-12.

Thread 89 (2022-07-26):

Motor XS Box too small

proggi64, 2022-07-26:
Use a Box190 and use more elements

Closed 2022-07-26.

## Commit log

2022-05-02 Base files
    Contains base functionality
    [Alignment.scad, Boxes.scad, Constants.scad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]
2022-05-02 Simple and complex element base modules
    [Complex.scad, Simple.scad]
2022-05-02 Initial collection of elements for building blocks
    [AxisCogWheel.scad, AxisCoupling.scad, AxisDial.scad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]
2022-05-02 Tests and samples for all modules
    [AlignmentTestGetAlignedX.scad, AlignmentTestGetAlignedY.scad, BoxesTestBox130.scad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]
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2022-05-02 New ec2, ec1 updated (renamed deployment modules)
    [ec2.stl]
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2022-05-02 ec1 updated, renamed deployment modules
    [ec1.scad]
2022-05-02 New elements, fixes
    [AxisCoupling.scad, AxisHub.scad, HolderBatterySet.scad]
2022-05-02 Additional modules, fixes
    [Boxes.scad, Placement.scad]
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2022-05-03 Correction AngledFrame
    [Simple.scad]
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2022-05-03 Fixed a semicolon, new functions for FrameAxis
    [Complex.scad]
2022-05-03 Started box, not finished, yet
    [mot1.scad]
2022-05-03 FrameMotor6V - new element
    [FrameMotor6V.scad]
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2022-05-03 Correction, two new elements from mot1
    [TestAxisCoupling.scad, TestFrameBracketWithAxle80.scad, TestFrameMotor6V.scad]
2022-05-03 Two new elements from mot1
    [FrameBracketWithAxle80.scad]
2022-05-03 mot1. Not ready, yet
    [mot1.scad]
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2022-05-04 New elements: Frames for brackets
    [TestFrameBracketCombo.scad, TestFrameBracketWithWorm.scad, TestFrameBracketWithoutWorm.scad]
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2022-05-05 Tests FrameRack und RackBase
    [ComplexTestFrameRack.scad, ComplexTestRackBase.scad]
2022-05-05 mot2 - just started - not ready
    [mot2.scad]
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2022-05-06 Rack frames - not ready yet
    [mot2.scad]
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2022-05-06 Tests for CylinderHub and CylinderHubWithZ30, fixed CylinderGear
    [TestCylinderGear.scad, TestCylinderHub.scad, TestCylinderHubWithZ30.scad]
2022-05-06 2x CylinderHubWithZ30. Not ready, yet
    [mot2.scad]
2022-05-06 Additional elements and fixes
    [AxisHub.scad, CylinderAxis30.scad, CylinderHub.scad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]
2022-05-06 Tube: renamed parameters, optional Parameters
    [SimpleTestTube.scad]
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2022-05-07 mot2 additional elements. Not ready, yet
    [mot2.scad]
2022-05-07 STL file of the mot2 box
    [mot2.stl]
2022-05-09 Base for 3D printing tests of elements
    [TestPrint.scad]
2022-05-09 3D print tests of single elements
    Each element is places on a 0.4 mm base plate, ready for a printing test.
    Elements should always be 3D printed before they are released to ensure that the bulding blocks are fitting in real world scenarios.
    [TestPrintAxisClip10.scad, TestPrintComboCompleteBucketPlusCouplingBrackets.scad, TestPrintComboDiscCamPlusCogWheel.scad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]
2022-05-09 Use of renamed AxisHubWithZ30
    [mot2.scad]
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2022-05-13 Fixed box 130x95
    [Fischertechnik Box 95x130.stl]
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2022-05-15 Fixes and extensions, refactoring
    [Constants.scad, Deployment.scad, Fischertechnik Box 95x130.stl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]
2022-05-15 Fixes, extensions, refactoring
    [Complex.scad, Simple.scad]
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2022-05-15 Fixes, Refactoring
    [Deployment.scad, Placement.scad]
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2022-05-19 FrameSpecialFlat corrected, dependent Elements fixed
    [Complex.scad, ComplexTestFrameSpecialFlat.scad, FrameAperture.scad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]
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2022-05-19 Documentation of ModelBase completed
    [Complex.scad]
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2022-05-20 Boxes switched from CAD-designed STL to OpenSCAD code
    [Boxes.scad, BoxesTestBoxBase.scad]
2022-05-20 height parameter for BoxBase, sample code
    [Boxes.scad, BoxesTestBoxBase.scad]
2022-05-20 Default for rotation list, new Helper.scad, fixes for tests
    [Boxes.scad, Deployment.scad, DeploymentTestDeployHorizontal.scad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]
2022-05-20 Fix for rack frames
    [mot2.scad]
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2022-05-20 RailsBasePlate, some tests moved to the right folder
    [RailsBasePlate90x90.scad, TestCylinderAxis30.scad, TestCylinderGear.scad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]
2022-05-20 Multiple new documentation files with partfinder-links
    [RailsBasePlate180x90.scad]
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2022-05-21 Additional documentation and images
    [FrameAngleBlock10x15x15.scad, FrameAxis60Open.scad]
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2022-05-21 Additional documentation of elements
    [ComboFrameBrackets.scad, FrameBracketCombo.scad]
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2022-05-22 Additional elements documented, renamed building plates
    [HolderBatterySet.scad, HolderBuildingPlate30x30.scad, HolderBuildingPlate30x45.scad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]
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2022-05-24 Start ElectronicBlockBoxBase, fix in Boxes
    [Boxes.scad, ElectronicBlockBoxBase.scad]
2022-05-24 hobby electronic building block base
    [Deployment.scad, ElectronicBlockBoxBase.scad]
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2022-05-24 Fixed paths
    [ElectronicBlockBoxBase.scad]
2022-05-25 Electronics Building Block Boxes
    [h4 AN.scad, h4 FF.scad, h4 G.scad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]
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2022-05-25 Additional elements, fixes
    [FrameBTSmartController.scad, FrameCassette.scad, FrameElectronicBlock.scad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]
2022-05-26 Documentation, fixes
    [AxisClip10.scad, AxisFlatHub.scad, AxisHandCrank.scad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]
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2022-05-26 Tutorial box construction german
    [ElektronikGrundbaustein.scad]
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2022-05-29 Started tutorial for elements
    [Complex.scad, FrameAngleAxis.scad, HolderSpringLeg.scad]
2022-05-30 Progress of the tutorial an FrameAngleAxis
    [FrameAngleAxis.scad]
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2022-05-31 Fix FrameAngleAxis
    [FrameAngleAxis.scad]
2022-06-03 Customizer support for elements
    [AxisClip10.scad, CylinderTire20.scad, FrameAngleAxis.scad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]
2022-06-04 Fixed standuing axis tolerance
    [Constants.scad, Simple.scad]
2022-06-04 Fixes, documentation
    [TestPrintHolderSpringLeg.scad]
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2022-06-05 HolderTire45, 3D print tested elements
    [FrameControlLight.scad, HolderTire45.scad, TestHolderTire45.scad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]
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2022-06-06 Inlays for original box 190
    [BoxInlays.scad, BoxInlaysTestBox190Inlay.scad, BoxInlaysTestBox190InlayWeb.scad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]
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2022-06-11 Rackbase and FrameRack changes
    [Complex.scad, ComplexTestRackBase.scad, FrameElectronicBlock.scad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]
2022-06-11 mot3 with new FrameRack
    [mot3.scad]
2022-06-12 Fixes and improvements
    [BoxInlays.scad, BoxInlaysTestBox190Inlay.scad, Boxes.scad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]
2022-06-12 Fixes FrameAngle elements
    [FrameAngleEquilateral.scad, FrameAngleIsosceles.scad, FrameAngleRight.scad]
2022-06-12 Fixed HolderSpringLeg
    [HolderSpringLeg.scad]
2022-06-12 Advances mot3 (not ready, yet)
    [mot3.scad]
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2022-06-12 Fixes in mot2/mot3
    [mot1.stl, mot2.scad, mot2.stl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]
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2022-06-16 Connecting Rods 30 + 60
    [Complex.scad, ComplexTestAxisMiddleSupport.scad, ComplexTestElevatedFramesWithCutoff.scad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]
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2022-06-18 Inlay for ec1 plus box sample doc
    [ec1.scad]
2022-06-18 ec2 and ec3 as Inlays
    [Boxes.scad, ec2.scad, ec3.scad]
2022-06-18 updated ec STLs with inlays
    [ec1.stl, ec1_inlay.stl, ec2.stl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]
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2022-06-20 FrameRails - modelbase module
    [FrameBlockWithPin.scad, PlacementOptions.scad, Simple.scad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]
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2022-07-01 Fixed bug
    [ComboLockingWinchDrumAndHolder.scad]
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2022-07-02 Only 6 mm height
    [FrameSensor45x30.scad]
2022-07-03 Bugfix: FrameLeftCutoff
    [Simple.scad]
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2022-07-03 FrameAngle 15 and 7.5 degrees
    [FrameAngle15.scad, FrameAngle7p5.scad, TestFrameAngle15.scad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]
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2022-07-10 Electronics Box1 not ready
    [Electronics Box1.scad]
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2022-07-10 FrameElectronicsController, Fixes
    [Frame9VBatterySet.scad, FrameElectronicsController.scad, Simple.scad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]
2022-07-10 PROFI Electronis Box 1
    [Electronics Box1.scad]
2022-07-11 Boxes Electronics (not ready)
    [Electronics Box1.scad, Electronics Box2.scad, Electronics Box3.scad]
2022-07-11 Electronics Box 2 ready, Fixed Doc
    [Electronics Box1.scad, Electronics Box3.scad]
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2022-07-13 Fixes, new Constants
    [Constants.scad, Deployment.scad, Electronics Box3.scad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]
2022-07-13 Fixes, FrameReedRelayHolder
    [FrameAngleBlock10x15x15.scad, FrameReedRelayHolder.scad, TestFrameReedRelayHolder.scad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]
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2022-07-19 STL files PROFI Electronics
    Three rendered STL files for PROFI Electronics
    [Electronics Box1.stl, Electronics Box2.stl, Electronics Box3.stl]
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2022-07-26 Fixed Motor XS Box
    [CylinderLockingAxis30.scad, CylinderLockingBevelGear.scad, FrameAxis180.scad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]
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2022-07-30 3D print tolerance corrections
    [FrameControlLight.scad, FrameElectronicBlockConnector.scad]
2022-07-30 Tolerance corrections for 3D print
    [h4 FF.stl, h4 MF.stl, h4 ON.stl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]
2022-07-30 Minor fixes and STLs
    [h4 AN.scad, h4 AN.stl, h4 G.stl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]
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2022-08-07 Wrong AxisCoupling fixed
    [Electronics Box2.scad]
2022-08-07 Fixes, thinner box walls, improved stackability
    [Boxes.scad, Complex.scad]
2022-08-07 Fixes for Electronics Box 2
    [Electronics Box2.scad]
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2022-08-13 More length tolerance for FrameAxis
    [Complex.scad, Electronics Box2.stl, Electronics Box3.stl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]
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2022-08-21 Fixed tolerances and Electronics Box 3
    [Constants.scad, Electronics Box3.scad]
2022-08-21 Update/fix Electronics Box 3 STL
    [Electronics Box3.stl]
2022-08-21 Thinner box walls, doc für new strut functions
    [Boxes.scad, Electronics Box1.stl, Electronics Box2.stl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]
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2022-10-05 Fix for FrameAxis Call
    [FrameBracketWithAxle80.scad]
2022-10-06 Corrected : Angle Block only once, only one locking axis 30
    [Electronics Box2.scad, Electronics Box3.scad]
